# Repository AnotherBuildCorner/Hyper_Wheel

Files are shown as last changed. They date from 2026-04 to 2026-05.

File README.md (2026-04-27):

# Multi-Layer Embedded HID Interface with Rotary Input

A programmable HID control interface that replaces discrete key presses with continuous rotary input, enabling precise, context-aware interaction for workflows like video editing and CAD.

**Codename:** Hyper_Wheel

## Engineering Summary

- 4-layer mixed-signal embedded system (98 × 65 mm) based on nRF52840 (BLE + USB HID)
- RF-aware PCB layout with calculated 50Ω antenna trace on TG155 FR4
- Battery-powered architecture (LiPo + charger + protection + load switching)
- Multi-bus I²C system separating OLED displays and encoders for signal integrity
- Designed within JLCPCB DFM constraints (no blind vias, optimized BOM, 0402/0603 preference)
- Staged bring-up strategy using XIAO validation platform to decouple firmware and hardware risk

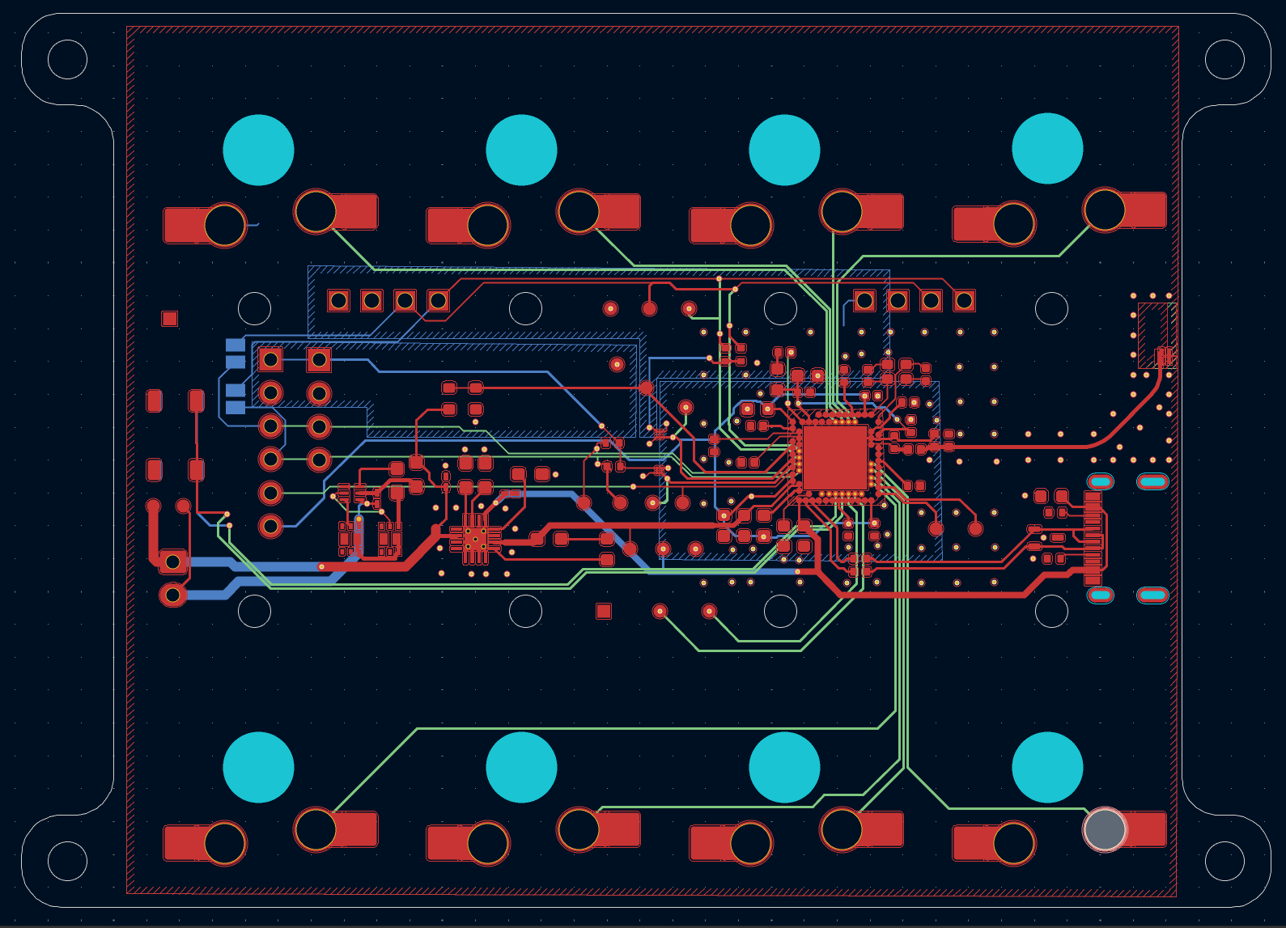
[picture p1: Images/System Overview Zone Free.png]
Full PCB

> > 4-layer mixed-signal PCB with dense MCU fanout, controlled routing, and separated power/RF domains
---

## What This Demonstrates

This project demonstrates the ability to:

- Design a mixed-signal embedded system with RF considerations  
- Make system-level tradeoffs under real constraints (power, layout, manufacturability)  
- Identify and mitigate risk without full simulation tooling  
- Structure hardware bring-up and validation intentionally  

This is not a proof-of-concept—it is a system designed to be built, debugged, and iterated.

---

## Status

- Rev A PCB complete and ready for fabrication  
- Validation hardware in production  
- Firmware development in progress  

---

## Intended Outcome

The goal of this project is to produce a fully functional, portable HID control surface that can be:

- Built using standard PCB manufacturing workflows  
- Assembled and validated without specialized RF tooling  
- Used in real workflows without custom drivers or software dependencies  

Success is defined by reliable operation, predictable behavior, and ease of integration into existing systems.

---

## Concept

### Early Concept Render
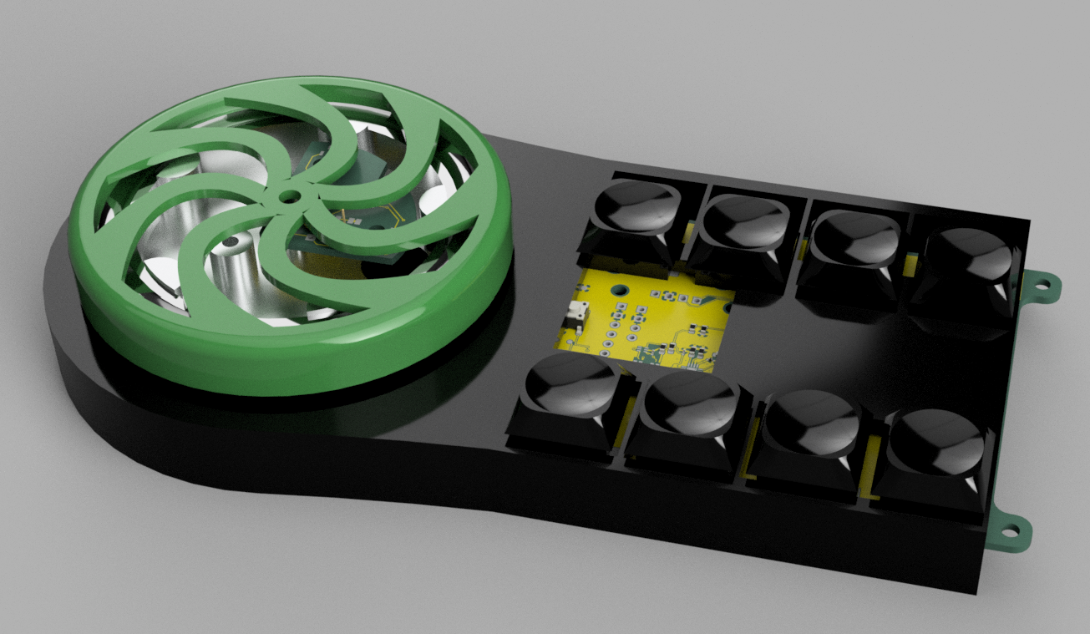
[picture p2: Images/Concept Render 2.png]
Early Render

> *Early prototype render shown for system concept demonstration. Mechanical design is still evolving.*

Hyper Wheel is a rotary-first HID control surface designed to replace discrete macro inputs with continuous, context-aware control.

The system combines:
- High-resolution rotary encoder input  
- Programmable key matrix  
- Onboard display feedback  

Primary use cases:
- Video editing (timeline scrubbing, precision control)  
- CAD navigation  
- General HID-based workflows  

The design prioritizes:
- Compact form factor  
- Driverless operation (USB/BLE HID only)  
- Integration of continuous and discrete input into a single interface  
---

## System Overview

Hyper Wheel is a programmable HID macro device built around a high-resolution magnetic encoder, designed to provide precise, context-aware control.

Unlike typical macro pads:
- Primary input is continuous (rotary), not discrete  
- Output is standard HID (keyboard + mouse)  
- Feedback is integrated via dual OLED displays  

The system is designed for enterprise compatibility:
- No custom drivers  
- USB and BLE HID only  

Current development focuses on validating:
- Power architecture  
- Multi-layer PCB layout with RF considerations  
- Scalable I/O architecture  

## System Architecture

```mermaid
flowchart LR

%% Power Path
USB[USB 5V] --> CHG[LiPo Charger]
BAT[LiPo Battery] --> PROT[Protection Circuit]
PROT --> CHG
CHG --> SYS[nRF52840 VDDH + Internal Regulator]
PROT --> VMON[ADC Batt Divider]
VMON --> MCU_ADC

%% Core System
SYS --> NRF[nRF52840 MCU] 
SYS --> LS[Load Switches]

%% Peripheral Power
LS --> OLED[Dual OLED Displays]
LS --> ENC[AS5600 Encoders]

%% Data / Control
NRF --> I2C1[I2C Bus 1]
NRF <--> I2C2[I2C Bus 2]
NRF --> LS
I2C1 --> OLED
I2C2 <--> ENC

%% Inputs
KEYS[Keyswitches on GPIO] --> NRF

%% Host Communication
NRF <--> USBDATA[USB 2.0]
NRF --> BLE[BLE]
USBDATA <--> HOST[Host Computer]
BLE --> HOST
```

## Key Features

- nRF52840-based system with **BLE + USB HID support**  
- High-resolution **magnetic encoder (AS5600-based)**  
- Dual **I2C OLED displays** for contextual UI feedback  
- **User-defined key mapping** (firmware-controlled)  
- **Left/right-hand agnostic layout** with mode switching  
- **LiPo + USB power architecture**  
- Modular sensor and expansion strategy  
- Fully **driverless operation (standard HID only)**  

---

## Engineering Highlights

### Single-MCU USB + BLE Architecture
- Transitioned from QFN48 to USB-capable aQFN73 to enable USB HID while maintaining BLE
- Preserved single-MCU architecture to reduce system complexity

### Battery-First Power System
- Implemented Nordic VDDH Config 4 architecture for battery-first operation
- USB used for detection only; system powered from charger output
- Enabled internal DC/DC (DCDCEN0/1), eliminating need for external regulator

### RF Design Approach
- Used reference antenna layout with controlled ground zones
- Calculated 50Ω impedance trace for 2.4 GHz operation on TG155 FR4
- Designed for short-range BLE use (desktop device)
- Validation deferred to hardware bring-up

### Routing Density & Layer Strategy
- Moved key matrix to inner layer to reduce congestion
- Improved fanout of high-density MCU region
- Optimized via sizing for manufacturing cost

### Iteration Strategy (Firmware First)
- Developed XIAO-based validation board to decouple firmware and hardware bring-up
- Allows testing of UI, input pipeline, and HID behavior before full PCB assembly

### Constraint-Driven Design

- Designed without access to RF simulation or SI toolchains, relying on first-principles reasoning and reference layouts to achieve first-pass success  
- Applied calculated trace geometry and conservative design margins to mitigate signal integrity risk  
- Prioritized manufacturability and iteration speed over theoretical optimization  
- Structured design to enable validation through hardware bring-up rather than pre-simulation

---

## Key Engineering Decisions

- **Single-MCU architecture (nRF52840)**  
  Reduced system complexity while supporting both BLE and USB HID

- **Battery-first power design (VDDH Config 4)**  
  Enabled seamless USB + battery operation without conflicting domains

- **Split I²C buses**  
  Prevented address conflicts and improved signal integrity under expansion

- **HID-only communication (no custom drivers)**  
  Ensures enterprise compatibility and plug-and-play behavior

- **Staged bring-up using validation hardware**  
  Reduced risk by separating firmware development from full system assembly

- **Conservative RF design without simulation tooling**  
  Relied on reference layouts and controlled geometry with validation deferred to hardware
---

## Validation Status

| Area | Status |
|---|---|
| Power System | Not yet characterized under load |
| RF Performance | Not validated (no RF test equipment available) |
| USB Signal Integrity | Not measured |
| I2C Stability | Not stress-tested |
| Firmware Integration | In progress |

> Validation strategy is structured to isolate failure modes early, reducing system-level debugging complexity during full integration

> Firmware bring-up and subsystem testing occurring prior to full hardware integration.

---

## Power Profile (Preliminary)

The following figures are early design estimates based on component datasheets and expected operating modes. Final values will be validated during bring-up.

### Component-Level Current Estimates

| Component / Mode | Estimated Current | Notes |
|---|---:|---|
| nRF52840, BLE active (+8 dBm) | 14.8 mA | Active BLE operating point on 3.3 V rail |
| OLED display (each) | 12–20 mA | 0.96" Winstar OLED at 3.3 V, ~50% illumination |
| AS5600 encoder (each, active) | 6.4 mA | Active measurement mode |
| Keyswitches | ~0 mA | No static consumption |
| nRF52840 system-off, RAM retained, wake on GPIOTE | 2.36 µA | MCU-only low-power state |

### Estimated System Current

| System Mode | Estimated Current | Notes |
|---|---:|---|
| Active, one OLED + one encoder + BLE | ~33.2–41.2 mA | 14.8 + 12–20 + 6.4 |
| Active, two OLEDs + one encoder + BLE | ~45.2–61.2 mA | Current main-board target configuration |
| Active, two OLEDs + two encoders + BLE | ~51.6–67.6 mA | Higher-end fully populated case |
| Deep sleep / system-off | ~33 µA | Includes MCU, charger, protection IC, hall sensor, FET leakage, and battery divider |

### Estimated Runtime (2000 mAh LiPo)

| Mode | Estimated Runtime |
|---|---:|
| 45.2 mA active draw | ~44 hours |
| 61.2 mA active draw | ~33 hours |
| 67.6 mA active draw | ~30 hours |
| 33 µA sleep current | ~6.9 years theoretical |

Sleep-current validation will also include key-matrix wake behavior, since retained GPIO pullups can dominate standby current if not configured carefully.

> Sleep-mode runtime is a first-order electrical estimate only and does not account for battery self-discharge, cell aging, converter losses, or environmental effects.

> These values are estimates and will be validated during hardware bring-up.

##  Hardware Overview

The following images highlight key aspects of the PCB design, including routing strategy, RF layout considerations, and multi-layer power distribution.

---

### Full PCB Layout (Routing View)
Full PCB

> Overall PCB layout showing multi-layer routing strategy, peripheral distribution, and controlled RF region placement.

---

##  MCU / RF Region Detail

### Top Layer (Routing)
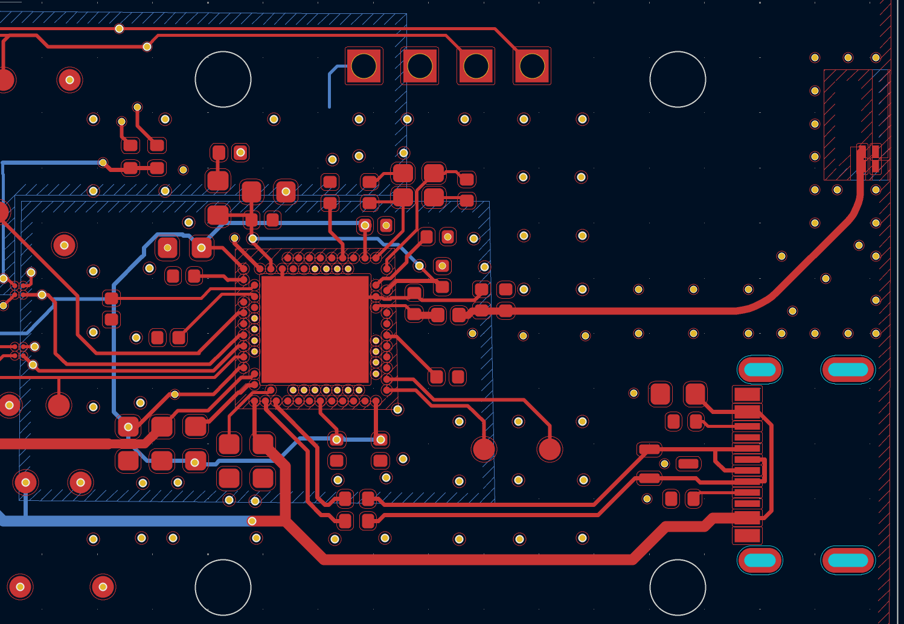
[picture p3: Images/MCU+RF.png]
MCU Routing


> nRF52840 fanout and high-density routing region, including USB interface routing and transition into a controlled antenna region.

---

### Ground Reference Layer
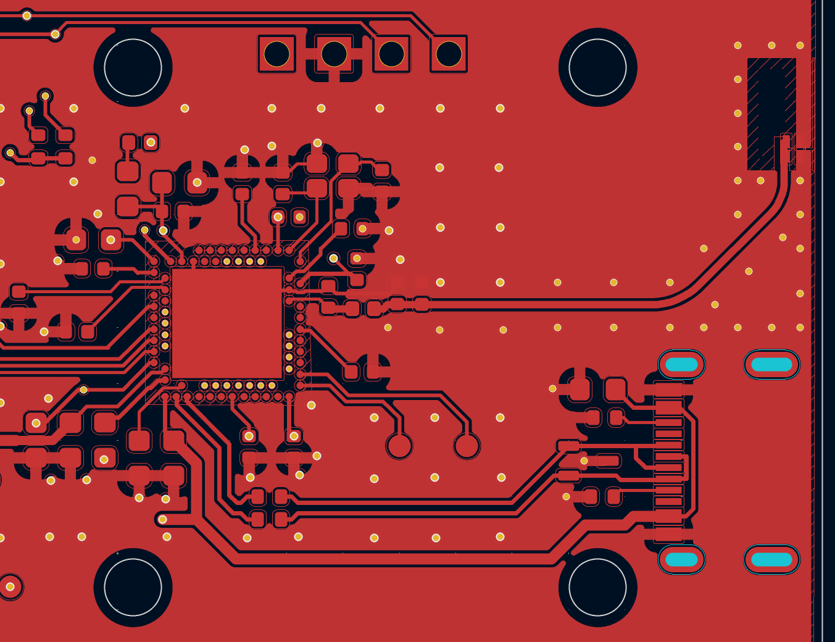
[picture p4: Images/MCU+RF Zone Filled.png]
Ground Plane


> Ground reference layer showing return path continuity, stitching strategy, and antenna clearance region.

---

### Power Distribution Layer || Metal 4
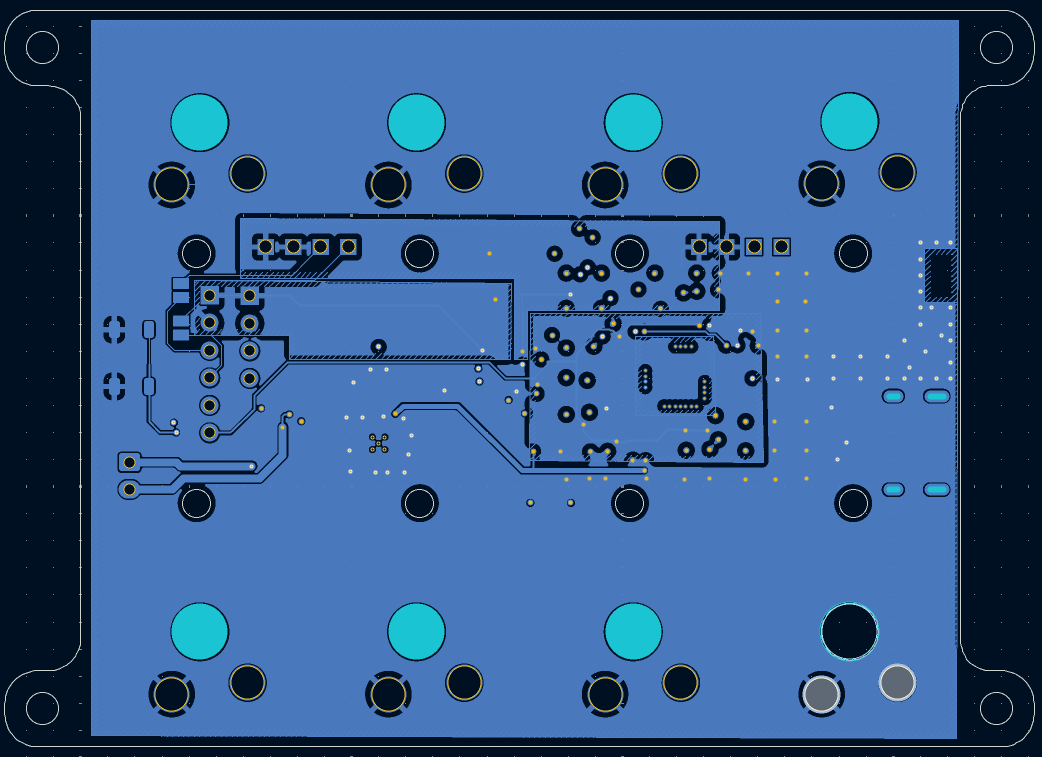
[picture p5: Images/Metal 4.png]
Power Plane


> Multi-zone power distribution separating 3.3V, Load domains, and ground to reduce coupling and improve system stability.

---

##  Layer Stack & Power Distribution

### Full Ground Plane || Metal 3
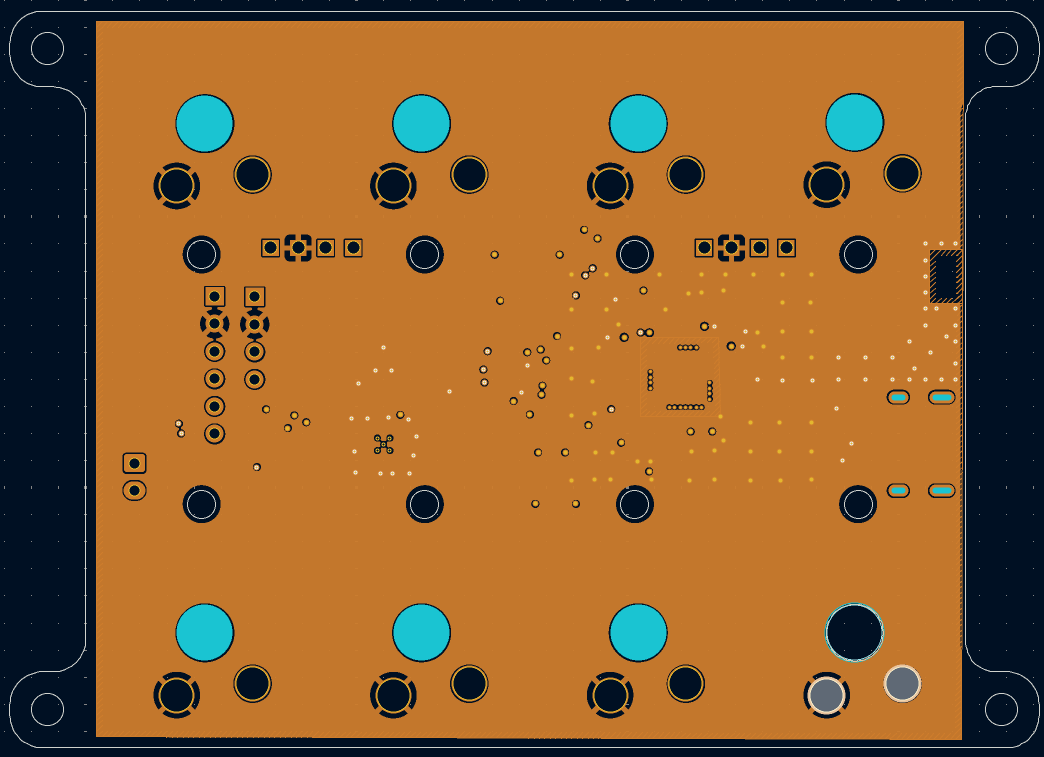
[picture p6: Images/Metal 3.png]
Full Ground


> Continuous ground plane providing low-impedance return paths across the board and supporting RF performance.

---

### Full Signal Plane || Metal 2
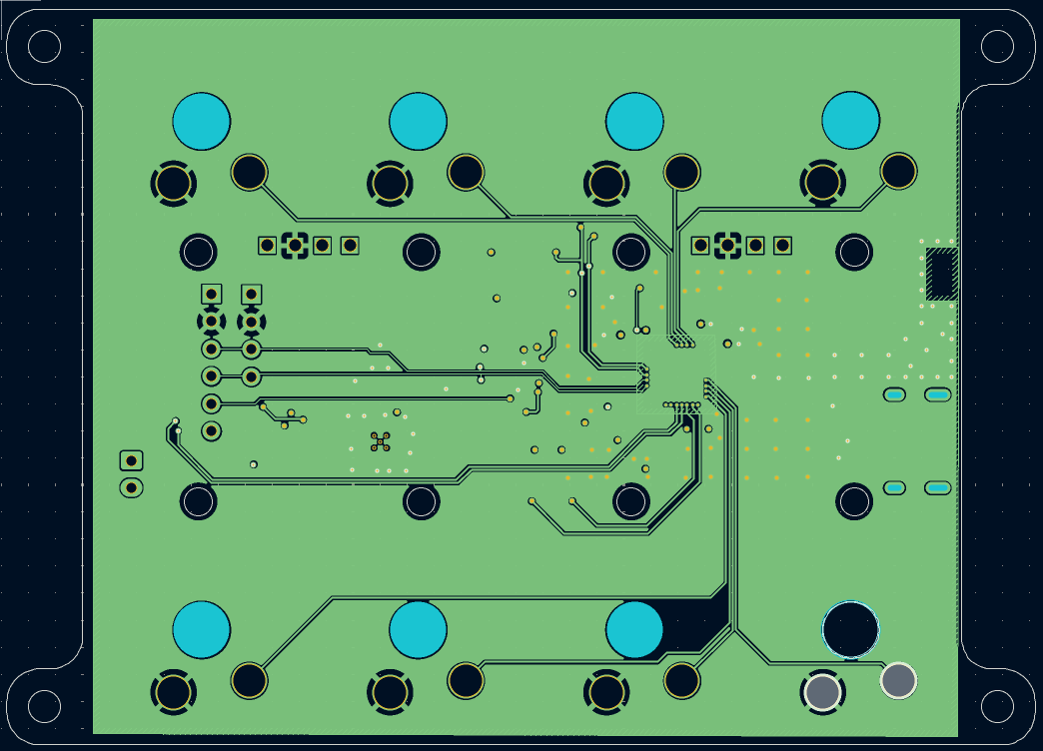
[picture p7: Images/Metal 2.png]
Full Power


> Second layer signal plane for BGA fanout.

---

### Full Top Plane || Metal 1
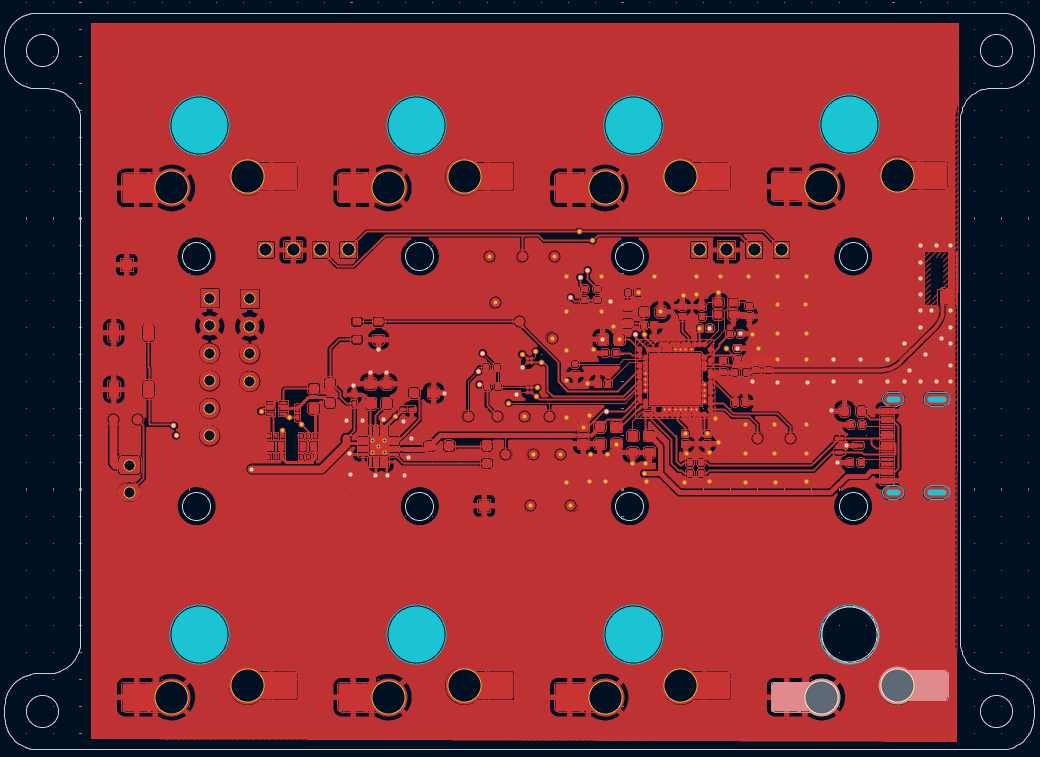
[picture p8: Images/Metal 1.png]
Full Top Plane


> Primary signal plane with all zone ground.

---

##  Dev Platform / Prototype

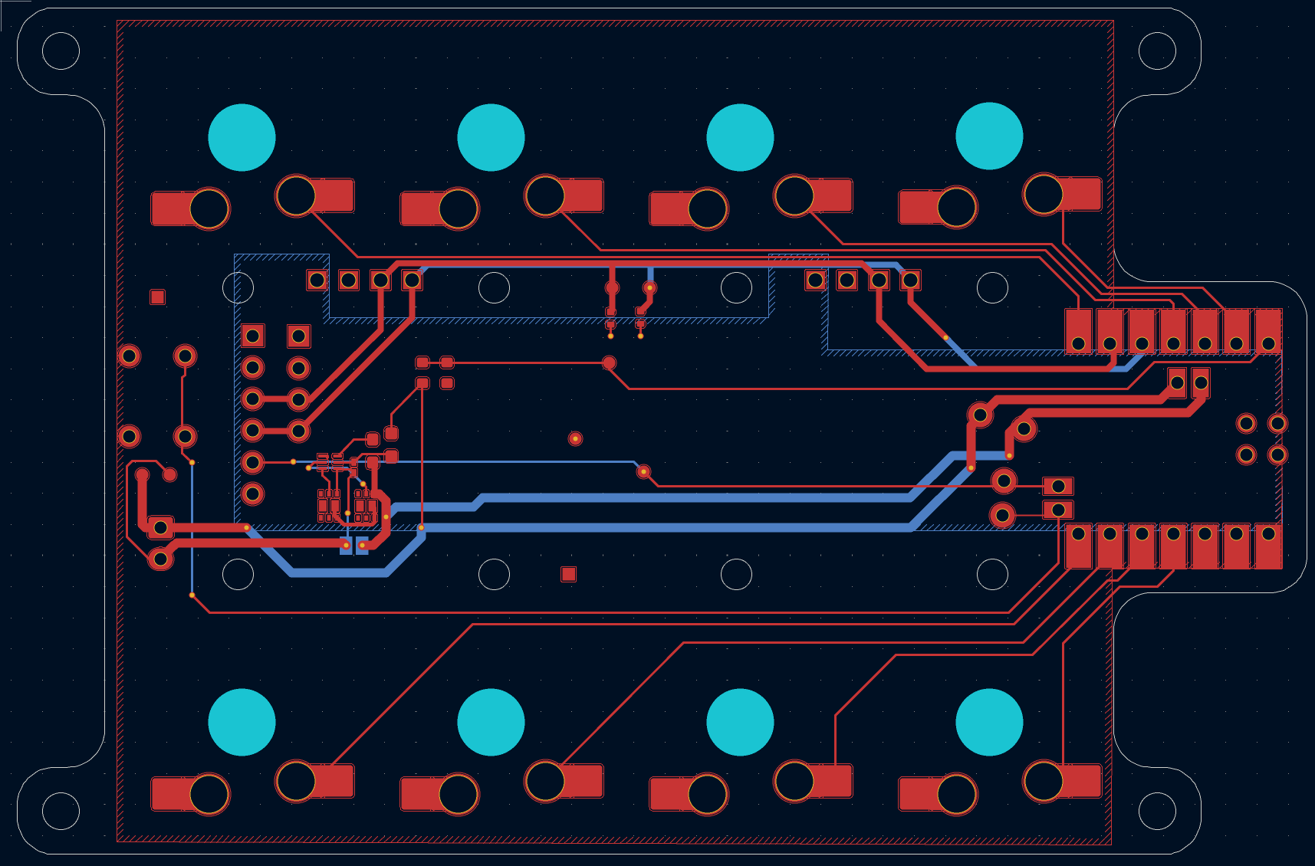
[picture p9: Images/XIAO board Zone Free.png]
XIAO Dev Board

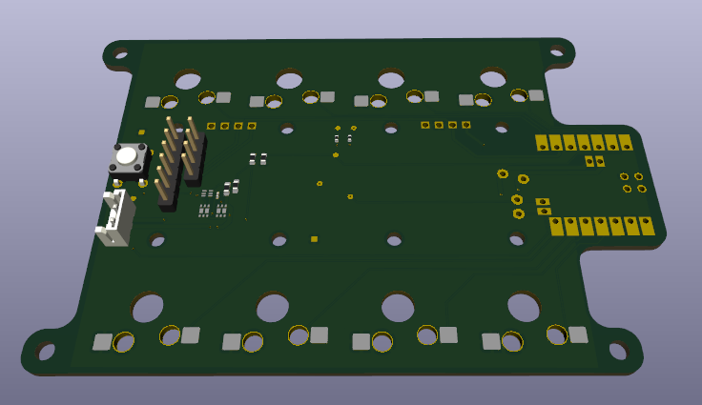
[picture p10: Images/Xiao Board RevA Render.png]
XIAO Render


> Simplified firmware validation platform based on the XIAO nRF52840, enabling rapid iteration of firmware and UI behavior prior to full hardware validation.

### Dev System Architecture

```mermaid
flowchart LR

%% Power Path
USB[USB 5V] --> CHG[XIAO Onboard LiPo Charger]
BAT[LiPo Battery] --> PROT[Protection Circuit]
PROT --> CHG
CHG --> SYS[XIAO VDDH + Internal Regulator]
PROT --> VMON[ADC Batt Divider]
VMON --> MCU_ADC

%% Core System
SYS --> NRF[nRF52840 MCU] 

%% Peripheral Power
SYS --> OLED[Dual OLED Displays]
SYS --> ENC[AS5600 Encoders]

%% Data / Control
NRF <--> I2C1[I2C Bus 1]
I2C1 <--> OLED
I2C1 <--> ENC

%% Inputs
KEYS[Keyswitches on GPIO] --> NRF

%% Host Communication
NRF <--> USBDATA[USB 2.0]
NRF --> BLE[BLE]
USBDATA <--> HOST[Host Computer]
BLE --> HOST
```

---

## Hardware Iterations

### Rev A – Firmware Validation Platform
- XIAO nRF52840-based
- Reduced feature set to validate input, display, and HID stack
- 2-layer board for reduced cost/complexity

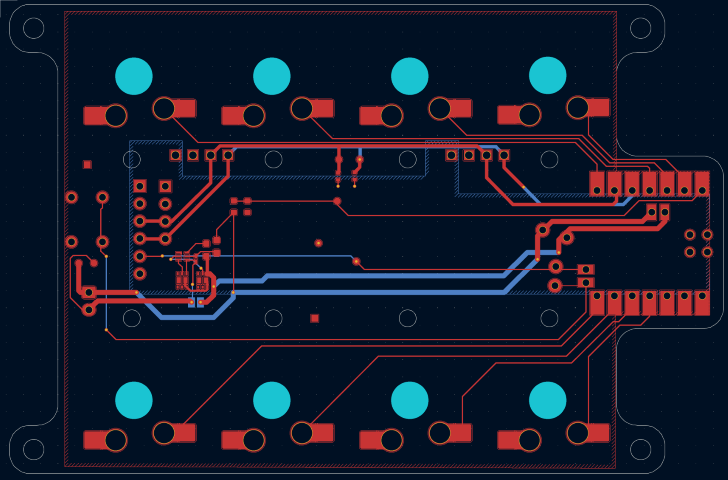
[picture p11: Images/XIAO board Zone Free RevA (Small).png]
 
> Rev A Board.

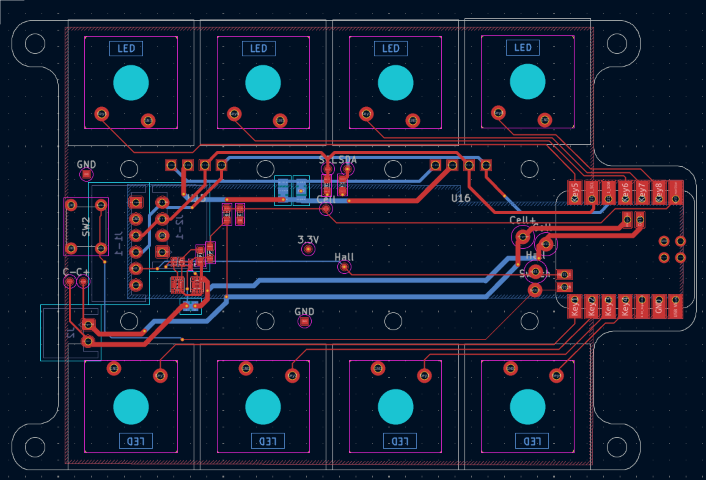
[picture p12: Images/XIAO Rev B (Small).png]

> Rev B board, note change in keyswitch footprints and added jumper network
### Rev B – Connector + Layout Refinement
- Introduced JST right-angle connectors (2/4/6 pin)
- Retained 2.54mm headers for bring-up flexibility
- Implemented rotationally symmetric connector layout
  - Enables cross-compatibility between 4-pin and 6-pin harnesses
  - Increased routing complexity but improved wiring consistency
- Adjusted OLED power routing for improved modularity

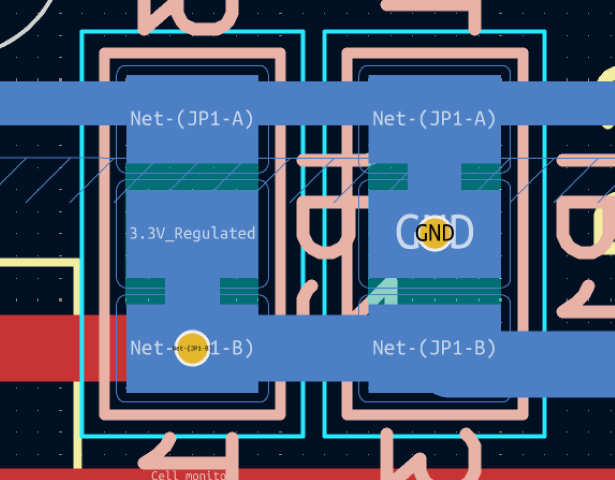
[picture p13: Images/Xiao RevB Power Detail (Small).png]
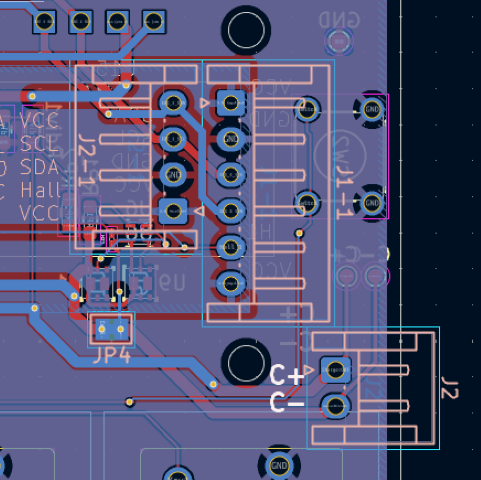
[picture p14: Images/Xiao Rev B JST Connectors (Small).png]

> Right shows the reconfigurable jumper array to switch GND and VCC pins to OLED

### Key Takeaways
- Connector standardization impacts both layout complexity and user error rate
- Bring-up flexibility is worth temporary redundancy (2.54 + JST)
- Physical interface decisions cascade into firmware, assembly, and usability

## Design for Manufacturing (DFM)

This design explicitly considers **PCBA cost and manufacturability**, not just functionality.

- Designed within standard JLCPCB capabilities (no blind vias, no via-in-pad)  
- Optimized via sizing for cost  
- Minimized use of 0201 components where not required  
- Favoring 0402 / 0603 for improved assembly yield  
- Reducing unique BOM values (ongoing)

This ensures the design is **practical for real-world assembly**, not just theoretical performance.

---

##  Assembly / 3D Model

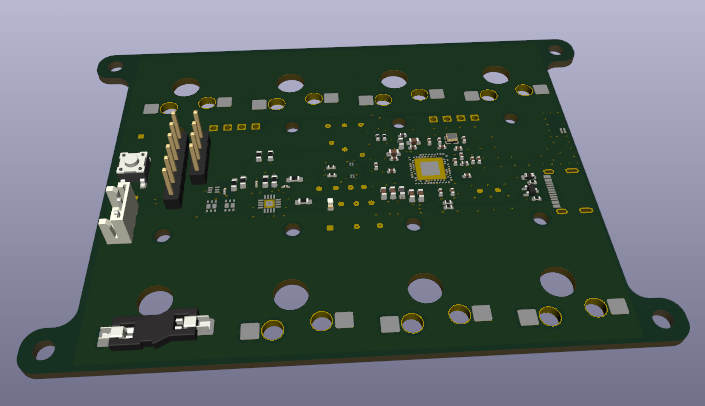
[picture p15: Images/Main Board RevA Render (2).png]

> Not all components have linked 3D models. USB and Keyswitches not shown
---

## Current Status

### Hardware
- Main PCB: Ready for fabrication (Rev A)  
- XIAO-based validation boards: Fabricated, awaiting delivery  
- Power architecture implemented (VDDH-based system)  
- Multi-layer routing and RF region defined  
- Test points and debug access integrated  

### Firmware
- Early development in progress (PlatformIO)  
- HID architecture defined (USB + BLE)  
- Encoder and display integration in progress  
- UI/UX layer not yet implemented  

### Mechanical
- Concept prototype complete (wheel + macro pad)  
- Final enclosure design pending  
- Mounting and integration strategy in development  

---

### Next Milestones

1. Bring-up XIAO validation platform  
2. Validate encoder and OLED pipeline  
3. Verify power behavior under real load  
4. Assemble Rev A main board  
5. Begin enclosure integration  

---

## Design Constraints

- Designed for standard PCB manufacturing (JLCPCB) with no blind/buried vias  
- Limited board size due to encoder geometry and enclosure constraints  
- Required HID-only communication for enterprise compatibility  
- Power system designed around single-cell LiPo with safe charge/discharge behavior

### Key Tradeoffs

- Chose single-MCU (nRF52840) over multi-chip architecture to reduce system complexity at the cost of tighter routing constraints  
- Accepted lack of RF simulation tooling and relied on reference layout + conservative design margins  
- Used internal VDDH regulation to simplify power architecture, trading off external regulator flexibility  
- Split I2C buses to manage address conflicts and maintain signal integrity under expansion

---
## Use Cases

**Primary**
- Video editing (timeline scrubbing, precision control)

**Secondary**
- CAD navigation  
- General productivity workflows  
- Custom macro environments  

---

## Future Work

### Firmware

- Development of configurable HID mapping system  
- Exploration of QMK/ZMK compatibility with encoder-based input  
- Potential on-device configuration interface via OLED UI  

### Mechanical

- Final enclosure design around encoder and key layout  
- Mounting strategy for PCB and battery integration  
- Ergonomic considerations for left/right-handed use

---

## Design Philosophy

- Use **standard HID** instead of custom drivers  
- Prioritize **iteration speed over theoretical perfection**  
- Design within **real manufacturing constraints**  
- Document decisions and tradeoffs explicitly

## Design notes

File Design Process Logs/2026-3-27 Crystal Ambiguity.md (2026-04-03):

# Crystal Footprint and Package Interpretation

## Context

Initial schematic review suggested ambiguity in crystal pin count based on symbol representation.

## Observation

- Schematic representation appeared to imply a third connection
- BOM entry only specified package size (XTAL SMD 2016)
- No explicit pin count provided

## Resolution

Review of reference PCB layout shows:

- 4-pad crystal footprint (2 active + 2 grounded case pads)
- Two pads routed to XC1 / XC2
- Two pads tied to ground plane

## Decision

Use 4-pad 2016 crystal footprint with grounded case.

## Notes

- Schematic symbols can be misleading when nodes are shared visually
- PCB layout is the authoritative reference for footprint selection
- Grounded crystal cases improve EMI and stability in RF designs

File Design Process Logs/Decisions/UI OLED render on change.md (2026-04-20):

# Event-Driven Display Update Model

**Date:** 2026-04-20

## Context
The display was originally updated continuously in the main loop, calling `displayRender()` every iteration.

This caused performance issues:
- OLED updates over I2C consumed significant time
- Encoder responsiveness degraded due to shared I2C bus contention

## Options Considered
- Option A: Continue constant redraw loop
- Option B: Throttle redraw using timing delays
- Option C: Move to event-driven redraw model

## Decision
Adopt event-driven redraw model using a dirty flag system.

## Why
Continuous redraw was unnecessary and interfered with input responsiveness. Most UI frames do not change every loop iteration.

Event-driven updates ensure:
- redraw only occurs when state changes
- I2C bandwidth is preserved
- encoder input remains responsive

## Implementation Notes
- `actionLayerUpdate()` returns a `uiChanged` flag
- Main loop sets `gDisplayDirty` when UI changes
- Mode transitions also force redraw
- Display renders only when `gDisplayDirty == true`

## Risks / Unknowns
- Missed dirty flag updates could cause stale display
- Mode transitions must always trigger redraw

## Revisit Trigger
- If UI becomes more dynamic (animations, live telemetry)
- If missed redraw bugs appear

## Notes
Menu-level caching was removed or minimized due to conflict with external dirty flag system

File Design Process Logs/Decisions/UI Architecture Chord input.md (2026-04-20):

# Input Architecture: System Button, Chords, and Preset Interaction Model

**Date:** 2026-04-20

## Context

The device now includes:
- 8 matrix keys (mapped per preset)
- 1 onboard system button (non-key, global control)
- 1+ encoders (profile-driven behavior)
- Chord detection (simultaneous key presses)

The system requires a scalable, low-friction method to access:
- Preset switching
- Preset editing
- Encoder configuration
- Bluetooth host selection
- System-level settings (orientation, pairing, etc.)

Early approaches risked overloading the system button or requiring deep menu navigation for all operations.

## Decision

Adopt a **layered input architecture** with distinct roles:

### 1. System Button → Preset Access
- **Tap:** Toggle between last two active presets
- **Hold:** Open preset picker UI

### 2. Column Chords (Top + Bottom Key in Same Column) → System Portals
Reserved for firmware-level context entry:

| Column | Function | Activation |
|---|---|---|
| Col 0  | Preset Editor | Contextual |
| Col 1  | System Menu | Tap chord  |
| Col 2  | Bluetooth Menu | Tap chord  |
| Col 3  | Encoder Tools | Hold chord |

### 3. Contextual Behavior Inside Preset Picker
When preset picker is open:
- Encoder scrolls presets
- System button confirms selection
- **Preset Editor chord enters edit mode for the currently highlighted preset**

### 4. Encoder Role (Mode-dependent)
- Normal mode: executes profile-defined action
- Menu mode: navigates selections
- Edit mode: modifies values (keycode, modifiers, labels, etc.)
- Hold-chord mode (encoder tools): performs live adjustments (e.g., sensitivity)

## Architectural Model

Inputs are separated into three tiers:

### Tier 1: Direct Actions
- Matrix keys
- Encoder (normal mode)

### Tier 2: Global Access
- System button (preset control)

### Tier 3: Context Entry
- Reserved chords (system-level mode entry)

### Tier 4: Context Execution
- Encoder + keys operate within active mode (menu/edit/system)

## Key Principles

- **Presets are accessed via the system button, not chords**
- **Chords are used for entering system contexts, not performing actions**
- **Editing is context-sensitive and tied to the currently selected preset**
- **Encoder is the primary control within all non-normal modes**
- **Hold-based chords are used for temporary, continuous adjustments**
- **Avoid overloading with multi-tap/double-tap patterns where possible**

## Rationale

This structure:
- Minimizes accidental activation (physical separation of chords)
- Matches frequency of use (presets = frequent, system settings = rare)
- Reduces reliance on timing-based gestures
- Scales cleanly as features are added
- Keeps UI mental model consistent (enter mode → operate within mode)

## Risks / Unknowns

- Exact chord mappings may need refinement based on ergonomics
- Users may require visual cues for chord discovery
- Encoder sensitivity adjustment behavior (temporary vs persistent) is not yet finalized
- Bluetooth usage patterns may influence whether dedicated chord access remains justified

## Revisit Trigger

Revisit after:
- Preset picker and editor flows are fully implemented
- Encoder adjustment behavior is tested in real use
- Bluetooth switching usage patterns are observed

## Notes

- Preset editor is not a top-level mode; it is accessed from within preset context
- Column chords remain reserved for system-level access only
- Future user-programmable chords may be restricted to non-column combinations

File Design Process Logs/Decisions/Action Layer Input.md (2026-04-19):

# Action Layer Owns Input Modes and Reserved Menu Entry

**Date:** 2026-04-19

## Context
The firmware had begun splitting into hardware input, keymap config, display rendering, and transport layers, but the central application/action layer was still missing. A specific need emerged for an internal menu system that can be entered without extra hardware, while preserving reversible device orientation and future keymap editability.

## Options Considered
- Option A: Bind menu entry to a dedicated hardware button outside the key matrix
- Option B: Reserve a hidden chord on the existing 8-key matrix
- Option C: Bind menu access as a normal mappable action within the keymap

## Decision
The action layer will own device mode switching and menu dispatch. Internal menu entry will initially use a reserved logical-key chord rather than a raw physical button chord or a user-mappable key action.

## Why
The action layer is the correct place to decide whether inputs should be interpreted as normal HID actions or as internal UI/menu controls. Using logical keys for the reserved chord preserves usability across both device orientations. Keeping menu entry outside the user keymap avoids conflicts with editable mappings and guarantees access to firmware-owned functions.

## Implementation Notes
Initial action layer structure includes:
- MODE_NORMAL
- MODE_MENU

Initial reserved menu entry:
- hold logical keys 1–4 for 1 second

Initial menu controls:
- encoder = navigate
- logical key 1 = select
- logical key 2 = back/exit

Normal HID output is suppressed while the reserved chord is being evaluated.

## Risks / Unknowns
A hidden chord may still be less discoverable than a dedicated system button. Exact menu control bindings may need refinement after display integration and real use testing. Future system controls such as BLE pairing, profile switching, or configuration save/load may require additional menu states or a broader system state model.

## Revisit Trigger
Revisit if:
- a dedicated system button is added
- logical chord entry proves awkward in use
- menu functionality expands beyond simple root navigation
- user-editable keymaps introduce conflicts with current assumptions

## Notes
The entry trigger is intentionally decoupled from the menu state machine so it can later be replaced by dedicated hardware, BLE commands, or maintenance/debug triggers without rewriting menu behavior.

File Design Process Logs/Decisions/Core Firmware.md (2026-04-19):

# Core Firmware Architecture Will Be Stabilized Before Menu and BLE Expansion

**Date:** 2026-04-19

## Context
The firmware now includes working pieces for button input, physical-to-logical key mapping, encoder step detection, USB HID transport, display rendering, and an early action layer. BLE service scaffolding also exists, but it is not yet integrated into the active application flow. Menu handling has started inside the action layer, but the normal-mode control path is not yet fully stabilized.

## Options Considered
- Option A: Continue adding menu and BLE features directly into the current scaffold
- Option B: Pause feature expansion and stabilize the architecture around the normal-mode control path first

## Decision
Core architecture stabilization will happen before expanding menu behavior or BLE integration.

## Why
The current codebase has the correct major pieces, but the full normal operating path is not yet cleanly complete. Continuing to add menu and BLE behavior before the normal path is stabilized would increase coupling and debugging difficulty. A stable baseline should exist where hardware input, logical mapping, action lookup, transport routing, and display state all work cleanly in normal mode before additional layers are added.

## Implementation Notes
Near-term architecture target:
- Definitions/config layer
- Hardware input layer
- Transport layer
- UI/render layer
- Application/action routing layer
- Minimal main entry point

Near-term order of work:
1. stabilize normal mode
2. add transport abstraction for USB/BLE routing
3. separate menu behavior into a dedicated menu layer
4. integrate BLE into the common action path
5. add persistence/config editing later

## Risks / Unknowns
Delaying menu and BLE work may feel slower in the short term, but it reduces the chance of architectural churn and hidden coupling. Encoder behavior, display redraw policy, and reserved chord handling may still need refinement during stabilization.

## Revisit Trigger
Revisit once:
- all 8 keys work end-to-end in normal mode
- encoder routing is finalized for normal mode
- action dispatch no longer depends directly on temporary debug or USB-only assumptions

## Notes
The immediate milestone is not feature breadth. It is a clean, reliable normal-mode pipeline that future menu and BLE layers can build on.

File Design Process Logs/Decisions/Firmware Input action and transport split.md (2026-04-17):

# Firmware Input / Action / Transport Split

**Date:** 2026-04-17

## Context
Initial bring-up started from single-file Arduino test sketches for encoder, OLED, and HID behavior. As USB HID, button scanning, display layout, and future BLE support began to converge, keeping all logic in one sketch became increasingly fragile. There was also a risk of coupling the encoder directly to keyboard output and coupling display logic directly to internal modules.

## Options Considered
- Option A:
  Keep most logic in a monolithic sketch and continue extending it with direct calls between buttons, encoder, HID, and OLED code.

- Option B:
  Split firmware into separate modules for inputs, mapping/action resolution, transport, and display rendering, while allowing the encoder to bypass keyboard-specific mapping when needed.

## Decision
Adopt a modular firmware structure where:
- buttons own GPIO scan, debounce, and edge detection
- encoder owns AS5600 reading and motion/step generation
- key/button mappings and encoder bindings resolve into actions
- USB/BLE act as transport layers
- display code renders a prepared display state rather than owning business logic

The encoder may bypass a keyboard-specific keymap when needed, but it should still resolve into the same action layer as the buttons.

## Why
This preserves flexibility without letting the encoder or OLED become side systems with their own incompatible logic paths. It supports:
- keyboard shortcuts for Resolve-style control
- future non-key actions such as scroll or consumer/media control
- future BLE transport without rewriting the core input model
- stable OLED rendering without circular dependencies between modules

## Implementation Notes
Current direction is:
- `buttons.*` for key GPIO handling
- `encoder.*` for AS5600 wheel handling
- `usb_hid.*` for USB keyboard transport
- `display.*` for OLED rendering from a display-state struct
- orientation and label layout handled separately from hardware scan logic

OLED grouping is defined as:
- screen A = keys 5, 6, 1, 2
- screen B = keys 7, 8, 3, 4

## Risks / Unknowns
- HID timing still needs cleanup to remove blocking delays
- BLE transport may impose different timing or report-structure needs
- final action model may need to expand beyond keyboard-only behavior
- shared I2C bus timing with encoder and dual OLEDs may need tuning

## Revisit Trigger
Revisit if:
- encoder needs scroll/media behavior instead of keyboard-only output
- BLE integration forces a different action abstraction
- OLED update timing interferes with input responsiveness
- menu/layer logic begins to blur module boundaries again

## Notes
The immediate proof point for this architecture is successful integration of:
1. dual OLED runtime screen
2. 8-button scan path
3. encoder and button actions through one common dispatch path

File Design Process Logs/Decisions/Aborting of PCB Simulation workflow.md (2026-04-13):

# Aborting Full PCB Simulation Workflow

**Date:** 2026-04-10

## Context
A possible simulation workflow was investigated for deeper PCB analysis, primarily around PDN, EM, and board-level behavior. The rough open-source path appeared to be KiCad → SALOME → Elmer, with the hope that copper features could be selectively simplified or excluded during model preparation.

The intent was to determine whether a full or near-full board analysis workflow was practical for this design, particularly for a multilayer PCB with dense routing, stitched vias, power distribution, USB, and RF concerns.

## Options Considered
- Option A: Build a full analysis workflow using KiCad exports into SALOME/Elmer and attempt to simulate large portions of the real PCB geometry.
- Option B: Use simplified or targeted analysis only, limiting simulation to specific concerns such as antenna behavior, rough thermal checks, or hand-calculated power integrity.
- Option C: Seek a more dedicated PDN / SI toolchain, accepting that most professional-grade options are commercial and likely impractical for this project.

## Decision
Abort the attempt to pursue full-board FEM / PDN-style analysis as a primary design workflow.

Instead, use targeted analysis only where it provides clear value, and rely on standard PCB design practice, simplified checks, and hand calculations for the rest.

## Why
The open-source simulation path appears to require far more geometry cleanup and abstraction work than is justified for this design.

Key reasons:
- SALOME / Elmer are not PCB-aware tools and do not naturally understand traces, pads, vias, or nets as design objects.
- Selectively excluding traces or simplifying copper after export is not straightforward unless geometry is already separated appropriately.
- A real multilayer board with stitching vias and normal routing detail would require substantial model preparation effort.
- The likely outcome is spending significant time building a simulation pipeline rather than resolving actual board risks.
- Dedicated PDN / SI tools that better match this type of problem are generally commercial and not reasonable for this project budget.

This makes full-board simulation a poor time investment relative to the likely design benefit.

## Implementation Notes
Going forward:
- Use simulation only for narrowly scoped problems where the result meaningfully affects layout decisions.
- RF / antenna behavior remains a possible candidate for targeted simulation.
- Thermal checks may still be worth doing with simplified geometry if needed.
- Power integrity should be handled primarily through layout discipline, trace/via sizing, return path awareness, and hand calculations unless a specific issue emerges.

## Risks / Unknowns
- Some second-order effects may go unmodeled.
- USB and RF behavior will rely more heavily on best practices than numerical verification.
- There is still some chance that a lighter-weight or more specialized free tool could be found later for one subset of the problem.

## Revisit Trigger
Revisit this decision if:
- A specific board issue appears that cannot be explained or resolved by normal layout review.
- A targeted simulation need emerges with clear scope and payoff.
- A practical free or low-cost PCB-aware analysis tool becomes available.
- The design grows substantially in complexity or power density.

## Notes
This is not a rejection of analysis in general. It is a rejection of building a full-board open-source simulation workflow when the tooling overhead outweighs the design value for this project.

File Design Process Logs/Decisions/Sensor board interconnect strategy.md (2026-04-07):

## Sensor Board Interconnect Strategy

**Date:** 2026-04-06

- Short internal cable (~40mm) inside single enclosure considered acceptable for AS5600/hall daughterboard
- Keeps main board compact and avoids extending PCB length by ~40mm
- Requires defined padout and strain relief strategy
- 6 pin layout (2 power, 1 ground, 2 I2c, and one switch)
- considering 1.25mm pitch ribbon connect

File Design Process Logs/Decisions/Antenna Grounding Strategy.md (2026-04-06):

# Antenna Zone and Grounding Strategy

**Date:** 2026-04-06

## Context
Chip antenna layout showed excessive GND pullback and poor copper merging behavior.  
Initial assumption pointed to custom rule conflicts, but behavior was inconsistent with rule definitions.

## Options Considered
- Option A: Increase global clearance
- Option B: Use custom rules to force zero clearance
- Option C: Adjust zone settings and pad connection locally

## Decision
Use localized zone and pad behavior control:
- Reduce zone clearance to 0.127mm
- Disable thermal relief for antenna GND pads
- Maintain footprint-defined keepout zones

## Why
- Global rules distorted RF geometry unnecessarily  
- Custom rules did not affect zone-level behavior  
- Zone clearance directly controlled copper pullback  
- Pad connection mode controlled actual electrical merging  

## Implementation Notes
- Zone clearance was incorrectly set to 0.5mm  
- Pads 2 and 3 require solid GND connection  
- Keepout zones embedded in footprint ensure portability  

## Risks / Unknowns
- RF performance not validated  
- Geometry deviates slightly from reference layout  
- Sensitive to nearby structures (USB, enclosure, battery)

## Revisit Trigger
- Poor BLE range or instability  
- Layout changes near antenna  
- Transition to production validation

## Notes
This issue originated from zone-level settings, not custom rule definitions.

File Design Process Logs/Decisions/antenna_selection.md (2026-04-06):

# 2.4 GHz Antenna Selection

**Date:** 2026-04-02

## Context
Need compact 2.4 GHz antenna for NRF52-based design with limited board space.

## Options Considered
- Johanson 2450AT07A0100001T (compact, higher gain, requires keepout)
- Johanson variant allowing ground underneath (lower performance, easier layout)
- Center board variant also considered

## Decision
Selected 2450AT07A0100001T chip antenna

## Why
- Better gain performance
- Smaller footprint
- Acceptable tradeoff vs layout constraints
- Center board model unacceptably expensive

## Risks / Unknowns
- No RF validation tools (no VNA/spectrum analyzer)
- Matching network tuning not verified
- Layout sensitivity (ground clearance, feed trace, orientation)

## Revisit Trigger
- Poor range / connection instability during real-world testing

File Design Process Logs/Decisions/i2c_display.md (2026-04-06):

# I2C Display Architecture

**Date:** 2026-04-02

## Context
Want UI feedback for key assignments

## Options Considered
- Single OLED
- Dual OLEDs on same bus
- Fully integrated display vs module
- Run each screen on separate bus, shared with one AS5600 each

## Decision
- Two I2C OLED modules on same bus [Tentative]
- Using prebuilt modules instead of raw OLED integration

## Why
- Faster implementation
- Library compatibility
- Visual layout (corner displays)

## Risks / Unknowns
- I2C address conflicts (must be configurable)
- Bus capacitance (especially if wiring expands)
- Limited refresh rate if both update frequently

## Revisit Trigger
- If UI lag or bus instability appears

---

# OLED Integration Strategy

## Context
Choice between integrating OLED directly vs using module

## Decision
Use I2C OLED module footprint instead of full integration

## Why
- Avoids driver/library complexity
- Reduces firmware risk
- Faster iteration

## Risks / Unknowns
- Larger footprint
- Less control over hardware optimization

## Revisit Trigger
- If moving toward production or space becomes critical

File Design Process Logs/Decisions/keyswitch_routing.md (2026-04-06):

# Keyswitch Routing Strategy

**Date:** 2026-04-02

## Context
Dense routing around MCU causing fanout congestion

## Options Considered
- Route on top layers (simpler but crowded)
- Push switch matrix to inner layer (Layer 3)

## Decision
Moved keyswitch routing to Layer 3

## Why
- Improves fanout from MCU
- Reduces congestion on outer layers
- Cleaner routing paths

## Risks / Unknowns
- Debug visibility reduced
- Potential coupling/noise if ground reference is poor

## Revisit Trigger
- If signal integrity or scanning issues appear

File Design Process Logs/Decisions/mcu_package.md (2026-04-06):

# Package Selection Trade Study

**Date:** 2026-03-28

## Context
Initial design targeted QFN48 for easier assembly.

## Discovery
QFN48 does not support USB and limits functionality.

## Impact
USB HID not available, conflicts with system requirements.

## Options Considered
- Remain on QFN48
- Add secondary MCU
- Transition to USB-capable package

## Decision
Transition to USB-capable package (aQFN73)

## Why
- Enables native USB HID
- Preserves single-MCU architecture

## Risks / Unknowns
- Increased assembly difficulty

## Notes
Reinforces importance of verifying package capabilities early.

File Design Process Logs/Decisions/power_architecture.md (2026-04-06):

# Power Architecture Update — Config 1 → Config 4

**Date:** 2026-03-28

## Context
Initial power architecture aligned with Nordic Config 1, assuming USB as primary supply.

## Problem
Config 1 conflicts with battery-first system design and existing charger architecture.

## Observations
Config 4 supports battery-backed operation and USB functionality.

## Decision
Transition to Config 4 power architecture.

## Why
- Aligns with battery-first behavior
- Avoids conflicting power domains
- Maintains USB functionality
- Improves efficiency via DC/DC

## Implementation Notes
- VDDH from charger output
- USB VBUS used for detection only
- DCDCEN0 / DCDCEN1 enabled
- External LDO removed

## Risks / Unknowns
- Must ensure valid VDDH range
- Requires proper low-voltage cutoff handling
- Careful USB routing required

## Revisit Trigger
- During bring-up validation

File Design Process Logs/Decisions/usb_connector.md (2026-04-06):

# USB-C Connector Placement

**Date:** 2026-04-02

## Context
USB-C connector is relatively near MCU / antenna region. System is expected to use either BLE or USB in most operating modes, with charging + BLE as a possible overlap case.

## Decision
Current placement retained for now; relocation under wheel section remains a fallback option.

## Why
- Layout constraints
- Reduced concern about simultaneous high USB data activity and BLE operation

## Risks / Unknowns
- Antenna detuning from nearby connector/cable/ground
- Charger or USB power-path noise during BLE use while charging
- Mechanical and routing tradeoffs not fully resolved

## Revisit Trigger
- Before final placement lock
- If BLE range or stability is poor in testing, especially while charging

## Notes

### USB/BLE Coexistence Assumption
System is expected to operate primarily in one of three modes:
- BLE on battery
- USB wired operation
- USB charging with BLE active

Design does not assume sustained high-speed USB data activity concurrent with BLE.
This reduces expected coexistence issues, but antenna placement and USB region layout still require care.

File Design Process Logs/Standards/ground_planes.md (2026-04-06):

# Ground Plane Strategy

**Date:** 2026-04-02

## Context
4-layer board design.

## Strategy
Use dedicated internal ground planes with outer layer fills.

## Structure
- Layers 2 and 3: solid ground
- Layers 1 and 4: signal + partial fill

## Rationale
- Improves return paths
- Reduces noise
- Supports RF + digital stability

## Risks / Tradeoffs
- Improper stitching → fragmented ground
- Antenna keepout violations

## Revisit Trigger
- Final layout review

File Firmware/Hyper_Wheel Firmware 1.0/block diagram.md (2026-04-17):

```mermaid

flowchart LR
KEY[GPIO Keys] --> HAND[Input Handler]
ENC[Rotary Encoder] --> HAND

PRE[Internal Presets] --> KMAP[Key Binding Map]
PRE --> EMAP[Encoder Binding Map]

HAND --> ROT[Orientation / Position Map]

ROT --> KMAP
ROT --> EMAP

KMAP --> ACT[Action Resolver]
EMAP --> ACT

ACT --> BLE[BLE HID]
ACT --> USB[USB HID]
ACT --> OLM[OLED Menu Control]

OLED[OLED Screen]
PRE --> OLED
KMAP --> OLED
OLM --> OLED

```

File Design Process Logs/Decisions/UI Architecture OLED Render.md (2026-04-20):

# Display Architecture Split (Mode-Specific Rendering)

**Date:** 2026-04-20

## Context
The initial display system used a single quadrant-based renderer designed for the main operating screen, where key labels are displayed in fixed positions corresponding to physical buttons.

When implementing the preset picker, this renderer was reused, requiring menu content to be forced into the quadrant layout.

## Options Considered
- Option A: Continue using quadrant renderer for all UI modes
- Option B: Introduce separate rendering paths for different UI modes

## Decision
Adopt separate render paths per UI mode:
- Normal mode uses quadrant renderer
- Preset picker uses dedicated list-style renderer
- Future modes (edit/system) will define their own render paths

## Why
Quadrant rendering is tightly coupled to the key-label display model and does not translate well to menu/list interfaces. Forcing menu content into this structure created unnecessary complexity and reduced clarity.

Separating render paths allows each mode to use a layout appropriate to its function.

## Implementation Notes
- Added `displayRenderNormal(...)`
- Added `displayRenderPresetPicker(...)`
- Preset picker renders directly from `ActionLayerState`, not `DisplayState`
- Removed menu usage of quadrant fill logic

## Risks / Unknowns
- Additional render paths may increase display module complexity
- Future modes may require further layout abstraction

## Revisit Trigger
- When implementing preset editor or system menu UI
- If rendering logic becomes duplicated across modes

## Notes
Display module remains centralized; separation is at function level, not file level (for now)

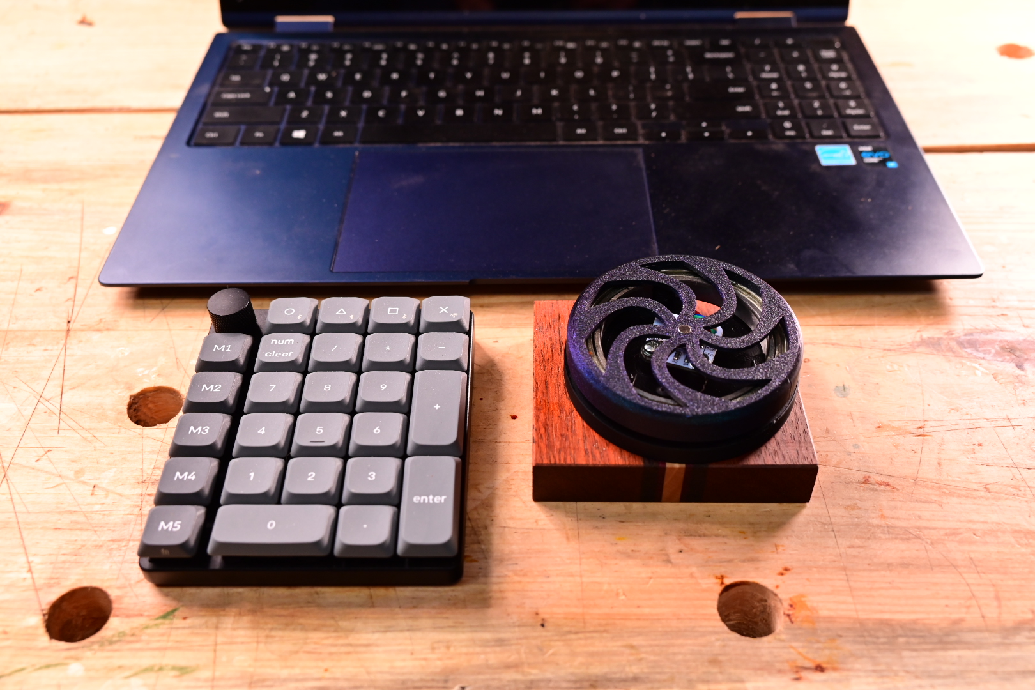
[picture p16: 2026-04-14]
Images/Concept Full.JPG

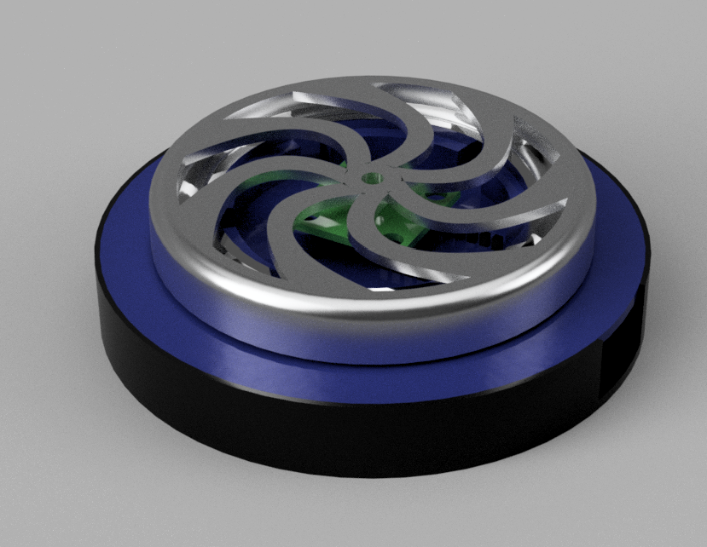
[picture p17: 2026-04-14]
Images/Original Concept.png

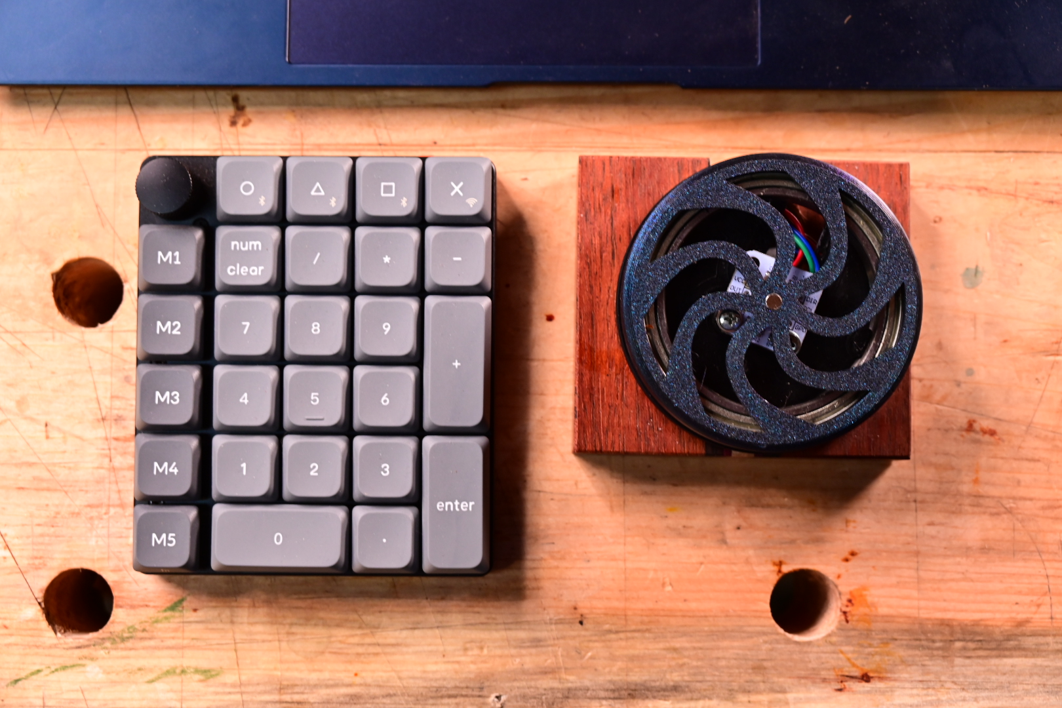
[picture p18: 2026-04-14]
Images/Concept Top Down.JPG

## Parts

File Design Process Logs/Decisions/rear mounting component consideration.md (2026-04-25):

# Rear-Mounted Component Strategy for Final Board

**Date:** 2026-04-24

## Context
Rev A XIAO board inspection showed that front-side component placement creates mechanical and accessibility constraints. The keyswitch sockets were misunderstood as front-mounted parts when they are actually rear-mounted for front-facing switches. The OLED module pinout also created a layout failure due to mismatch between reference symbol assumptions and the final module used.

## Options Considered
- Option A: Keep most components front-mounted.
- Option B: Rear-mount most SMT components except through-hole/user-facing items.
- Option C: Rear-mount most SMT components and replace OLED module with onboard SSD1306/display circuitry.

## Current Direction
Rear-mounting most non-through-hole components is under consideration for the final board.

## Why
Rear mounting may improve test pad access, reduce front-side crowding, and leave the front face primarily for user-interface elements: keys, display, wheel, and any required indicators.

## Implementation Notes
- Keep THT/mechanical interface items front-oriented where needed.
- Re-check hotswap socket footprint side/orientation explicitly.
- Verify OLED/display pinout from the exact final part, not a generic module reference.
- Charge LED may need a light pipe, edge-facing LED, or alternate visible indicator strategy.
- Onboard SSD1306/display integration may change this decision.

## Risks / Unknowns
- Rear-mounted parts may complicate assembly or enclosure clearance.
- Charge indicator visibility may become awkward.
- Display strategy is not yet settled.
- Test pad access improves only if enclosure/mechanical design leaves the rear reachable.

## Revisit Trigger
Revisit before Rev B/full-board routing is locked, especially after deciding between OLED module and onboard SSD1306/display implementation.

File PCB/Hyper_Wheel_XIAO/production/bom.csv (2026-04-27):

Designator | Footprint | Quantity | Value | LCSC Part #
CELL+, CELL-, HALL_2, SWITCH | TestPoint_Plated_Hole_D2.0mm | 4 | TestPoint
CH1, CH2, CH3, CH4, CH5, CH6, CH7, CH8 | SW_KS33_1u | 8 | KS33_SW_HS
CP1 | 0201 | 1 | 0.1u
J1-1 | JST_EH_S6B-EH_1x06_P2.50mm_Horizontal | 1 | Conn_01x06_Socket
J2 | JST_EH_S2B-EH_1x02_P2.50mm_Horizontal | 1 | LIPO
J2-1 | JST_EH_S4B-EH_1x04_P2.50mm_Horizontal | 1 | Conn_01x04_Socket
JP4 | SolderJumper-2_P1.3mm_Bridged_Pad1.0x1.5mm | 1 | Jumper_2_Bridged
RDIV1 | 0603 | 1 | 150k
RDIV2 | 0603 | 1 | 300k
RI1, RI2 | 0603 | 2 | 4.7k
RP1 | 0603 | 1 | 2.2k
RP2 | 0603 | 1 | 330
SW2 | SW_TH_Tactile_Omron_B3F-100x | 1 | SW_Push
U1, U9 | CDS85301-DQK0006B | 2 | CSD85301Q2
U15, U16 | OLED 128x64 | 2 | ~
U2 | XIAO-nRF52840-Sense-14P-THTMOD | 1 | Seeed Studio XIAO nRF52840
U6 | BQ29700-DSE0006A | 1 | BQ29700DSER

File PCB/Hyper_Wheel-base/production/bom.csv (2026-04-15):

Designator | Footprint | Quantity | Value | LCSC Part #
C1, C17, C18, C2 | 0402 | 4 | 12p
C10, C13, C22 | 0402 | 3 | N.C.
C11 | 0402 | 1 | 100p
C12, C25, C26, C5, C7, C8 | 0402 | 6 | 100n
C14, C15, C23, C24 | 0603 | 4 | 1.0u
C16 | 0402 | 1 | 47n
C19, C20, C21, C6 | 0603 | 4 | 4.7u
C3 | 0402 | 1 | 0.8p
C4 | 0402 | 1 | 0.5p
C9 | 0402 | 1 | 820p
CH1, CH2, CH3, CH4, CH5, CH6, CH7, CH8 | SW_KS33_HS_KS-2P02B01-02_HS_1u | 8 | KS33_SW_HS
CP1 | 0201 | 1 | 0.1u
CP2 | 0201 | 1 | 1u
CP3 | 0201 | 1 | 4.7u
D1 | 0603 | 1 | D_TVS
DP1 | 0603 | 1 | LED
J1-1 | PinHeader_1x06_P2.54mm_Vertical | 1 | Conn_01x06_Socket
J2 | JST_EH_B2B-EH-A_1x02_P2.50mm_Vertical | 1 | LIPO
J2-1 | PinHeader_1x04_P2.54mm_Vertical | 1 | Conn_01x04_Socket
J3 | USBC-CONN_8p94X6p5X3p16_12L_GCC | 1 | USB4215-03-A
JP1, JP2 | SolderJumper-2_P1.3mm_Open_Pad1.0x1.5mm | 2 | Jumper_2_Open
L1 | 0402 | 1 | 4.7nH
L2, L4 | 0603 | 2 | 10uH
L3 | 0402 | 1 | 15nH
RCC1, RCC2 | 0402 | 2 | 5.1k
RD1, RD2, RS1, RS2 | 0402 | 4 | 4.7k
RDIV1 | 0603 | 1 | 150k
RDIV2 | 0603 | 1 | 300k
RP1 | 0603 | 1 | 2.2k
RP2 | 0603 | 1 | 330
RP3 | 0603 | 1 | 1.5k
RP4 | 0603 | 1 | 4.12k
RP5 | 0603 | 1 | 1.18k
RP6 | 0603 | 1 | 1.13k
RUSB1, RUSB2 | 0402 | 2 | 22
SW1, SW2 | SW_SPST_PTS647_Sx38 | 2 | SW_Push
U1, U9 | CDS85301-DQK0006B | 2 | CSD85301Q2
U10, U4 | DBV0006A_L | 2 | TPS22916CNYFPR
U11 | SOT-323_SC-70 | 1 | TPD2EUSB30ADRTR
U13, U3 | AS5600L-ASOM_AMS | 2 | AS5600L-ASOM
U14, U8 | DRV5032-DBZ0003A-IPC_A | 2 | DRV5032FCDBZR
U15, U16 | OLED 128x64 | 2 | ~
U17 | 2450AT07A0100T_JOT+Keepout | 1 | 2450AT07A0100T
U2 | NORDIC_NRF52840-QIAA-R7 | 1 | NRF52840-QIAA-R7
U6 | BQ29700-DSE0006A | 1 | BQ29700DSER
U7 | BQ24074-QFN50P300X300X100-17N | 1 | BQ24074RGTR
Y1 | Crystal_SMD_2016-4Pin_2.0x1.6mm | 1 | 32MHz

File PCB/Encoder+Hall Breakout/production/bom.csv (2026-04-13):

Designator | Footprint | Quantity | Value | LCSC Part #
3.3V1, CCW1 | SolderJumper-2_P1.3mm_Open_Pad1.0x1.5mm | 2 | Jumper_2_Open
5V1, CW1 | SolderJumper-2_P1.3mm_Bridged_Pad1.0x1.5mm | 2 | Jumper_2_Bridged
C1 | 0603 | 1 | 100n
C2 | 0603 | 1 | 10u
J1-2 | PinHeader_1x06_P2.54mm_Vertical | 1 | Conn_01x06_Pin
OUT1 | PinHeader_1x01_P1.00mm_Vertical | 1 | TestPoint
PGO1 | TestPoint_Pad_D2.0mm | 1 | TestPoint
R1, R2 | 0603 | 2 | 4.7k
U1 | AS5600L-ASOM_AMS | 1 | AS5600L-ASOM
U2, U3 | DRV5032-DBZ0003A-MFG | 2 | DRV5032FCDBZR

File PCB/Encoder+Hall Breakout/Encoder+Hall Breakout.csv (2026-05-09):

Reference | Qty | Value | DNP | Exclude from BOM | Exclude from Board | Footprint | Datasheet
3.3V1,CCW1 | 2 | Jumper_2_Open |  |  |  | Jumper:SolderJumper-2_P1.3mm_Open_Pad1.0x1.5mm
5V1,CW1 | 2 | Jumper_2_Bridged |  |  |  | Jumper:SolderJumper-2_P1.3mm_Bridged_Pad1.0x1.5mm
C1 | 1 | 100n |  |  |  | Capacitor_SMD:C_0603_1608Metric_Pad1.08x0.95mm_HandSolder
C2 | 1 | 10u |  |  |  | Capacitor_SMD:C_0603_1608Metric_Pad1.08x0.95mm_HandSolder
J1-2 | 1 | Conn_01x06_Pin |  |  |  | Connector_PinHeader_2.54mm:PinHeader_1x06_P2.54mm_Vertical
OUT1 | 1 | TestPoint |  |  |  | Connector_PinHeader_1.00mm:PinHeader_1x01_P1.00mm_Vertical
PGO1 | 1 | TestPoint |  |  |  | TestPoint:TestPoint_Pad_D2.0mm
R1,R2 | 2 | 4.7k |  |  |  | Resistor_SMD:R_0603_1608Metric_Pad0.98x0.95mm_HandSolder
U1 | 1 | AS5600L-ASOM |  |  |  | Hyper_Wheel:AS5600L-ASOM_AMS | AS5600L-ASOM
U2,U3 | 2 | DRV5032FCDBZR |  |  |  | Hyper_Wheel:DRV5032-DBZ0003A-MFG | https://www.ti.com/lit/gpn/drv5032

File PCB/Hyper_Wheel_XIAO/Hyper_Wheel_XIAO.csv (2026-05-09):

Reference | Qty | Value | DNP | Exclude from BOM | Exclude from Board | Footprint | Datasheet
Cell+1,Cell-1,Hall1,Switch1 | 4 | TestPoint |  |  |  | TestPoint:TestPoint_Plated_Hole_D2.0mm
CH1,CH2,CH3,CH4,CH5,CH6,CH7,CH8 | 8 | KS33_SW_HS |  |  |  | Hyper_Wheel:SW_KS33_1u
CP1 | 1 | 0.1u |  |  |  | Capacitor_SMD:C_0201_0603Metric_Pad0.64x0.40mm_HandSolder
J1-1 | 1 | Conn_01x06_Socket |  |  |  | Connector_JST:JST_EH_S6B-EH_1x06_P2.50mm_Horizontal
J1-2 | 1 | Conn_01x06_Pin
J2 | 1 | LIPO |  |  |  | Connector_JST:JST_EH_S2B-EH_1x02_P2.50mm_Horizontal
J2-1 | 1 | Conn_01x04_Socket |  |  |  | Connector_JST:JST_EH_S4B-EH_1x04_P2.50mm_Horizontal
JJ2-2 | 1 | Conn_01x04_Pin
JP4 | 1 | Jumper_2_Bridged |  |  |  | Jumper:SolderJumper-2_P1.3mm_Bridged_Pad1.0x1.5mm
Rdiv1 | 1 | 150k |  |  |  | Resistor_SMD:R_0603_1608Metric_Pad0.98x0.95mm_HandSolder
Rdiv2 | 1 | 300k |  |  |  | Resistor_SMD:R_0603_1608Metric_Pad0.98x0.95mm_HandSolder
RI1,RI2 | 2 | 4.7k |  |  |  | Resistor_SMD:R_0603_1608Metric_Pad0.98x0.95mm_HandSolder
RP1 | 1 | 2.2k |  |  |  | Resistor_SMD:R_0603_1608Metric_Pad0.98x0.95mm_HandSolder
RP2 | 1 | 330 |  |  |  | Resistor_SMD:R_0603_1608Metric_Pad0.98x0.95mm_HandSolder
SW2 | 1 | SW_Push |  |  |  | Button_Switch_THT:SW_TH_Tactile_Omron_B3F-100x
U1,U9 | 2 | CSD85301Q2 |  |  |  | Hyper_Wheel:CDS85301-DQK0006B | https://www.ti.com/lit/gpn/csd85301q2
U2 | 1 | Seeed Studio XIAO nRF52840 |  |  |  | Hyper_Wheel:XIAO-nRF52840-Sense-14P-THTMOD
U3,U13 | 2 | AS5600L-ASOM |  |  |  | Hyper_Wheel:AS5600L-ASOM_AMS | AS5600L-ASOM
U6 | 1 | BQ29700DSER |  |  |  | Hyper_Wheel:BQ29700-DSE0006A | https://www.ti.com/lit/gpn/bq2970
U8,U14 | 2 | DRV5032FCDBZR |  |  |  | Hyper_Wheel:DRV5032-DBZ0003A-IPC_A | https://www.ti.com/lit/gpn/drv5032
U15,U16 | 2 |  |  |  |  | Hyper_Wheel:OLED 128x64

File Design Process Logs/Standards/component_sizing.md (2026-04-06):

# Passive Component Sizing Strategy

**Date:** 2026-03-26

## Context
Reference design uses 0201 components extensively.

## Strategy
Divide components into categories based on function.

## Categories / Rules
- RF-Critical (retain 0201)
- Timing-Critical (0402 consideration)
- General Passives (0402)
- Bulk Components (0603)

## Rationale
- Maintain RF integrity
- Improve assembly success rate
- Reduce placement difficulty

## Notes
Component size affects parasitics at RF frequencies.

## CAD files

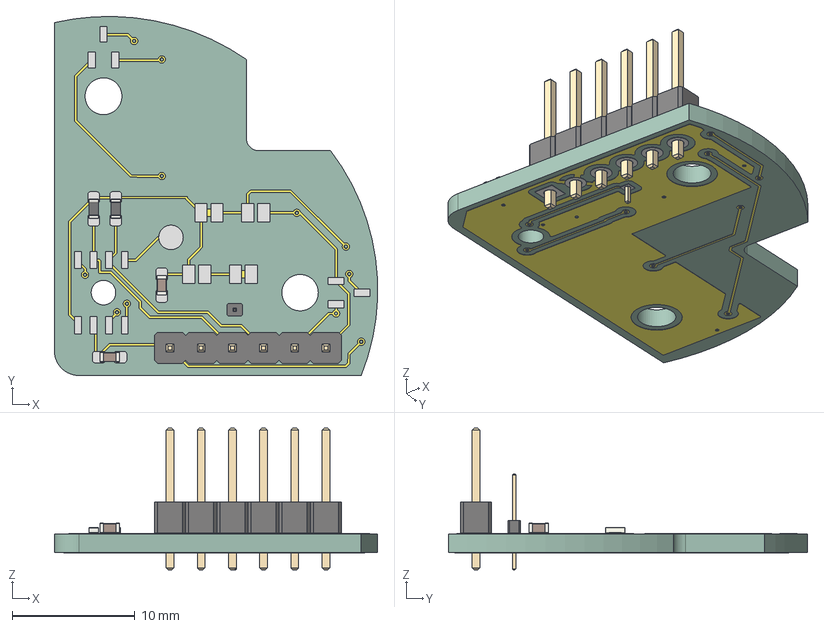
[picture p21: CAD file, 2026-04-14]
PCB/Encoder+Hall Breakout/Encoder Breakout.step
26.3 x 29.2 x 11.5 mm
PinHeader_1x01_P1.00mm_Vertical
R_0603_1608Metric x 2
C_0603_1608Metric x 2
PinHeader_1x06_P2.54mm_Vertical
Encoder+Hall Breakout_copper
Encoder+Hall Breakout_pad
Encoder+Hall Breakout_via
Encoder+Hall Breakout_PCB

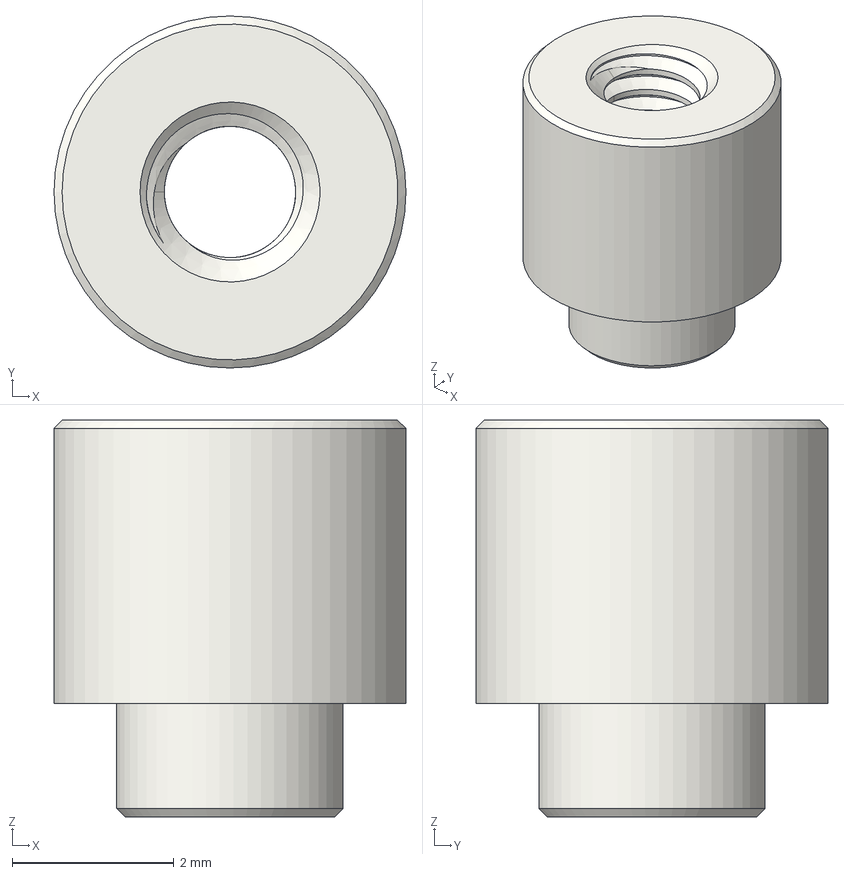
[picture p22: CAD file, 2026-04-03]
PCB/Hyper_Wheel_XIAO/Vendor Parts/marbastlib-main/marbastlib-main/3dmodels/Mounting_Wuerth_WA-SMSI-M2_H3P5mm_9774035243R.step
4.35 x 4.35 x 4.90 mm

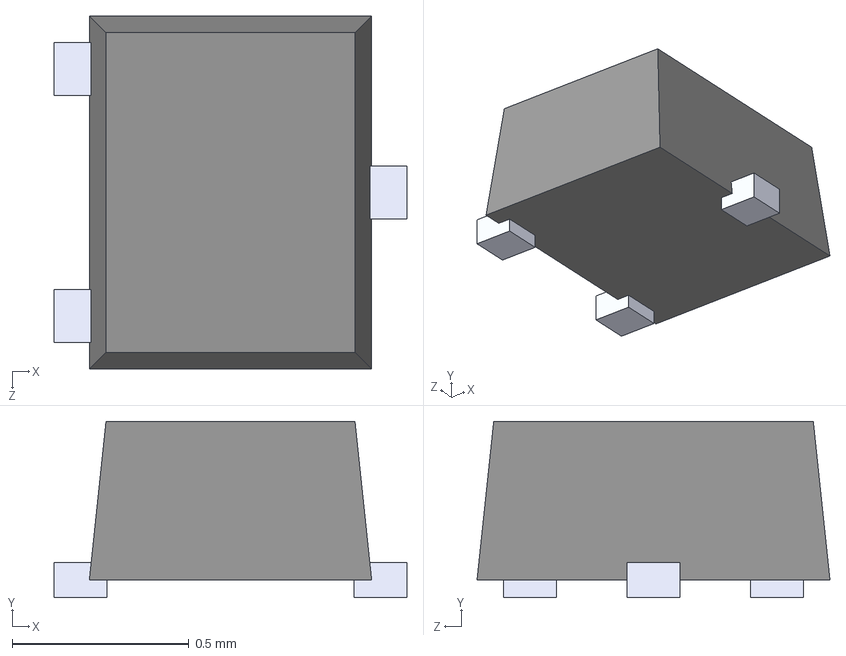
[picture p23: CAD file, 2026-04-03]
PCB/Hyper_Wheel_XIAO/Vendor Parts/TPD2EUSB30ADRTR/TPD2EUSB30ADRTR.step
1.00 x 0.5 x 1.00 mm

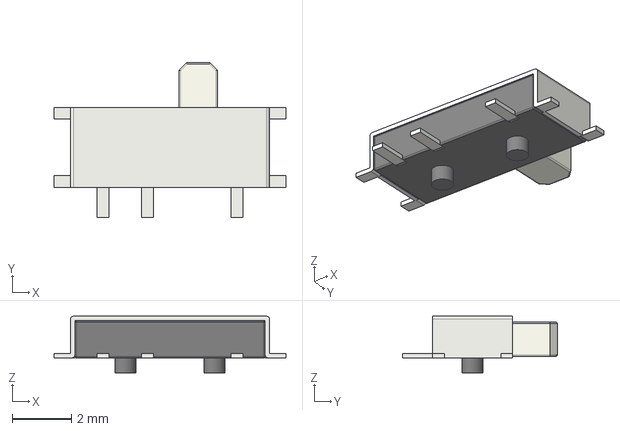
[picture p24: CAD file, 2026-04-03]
PCB/Hyper_Wheel_XIAO/Vendor Parts/marbastlib-main/marbastlib-main/3dmodels/SW_MSK12C02.step
7.80 x 5.20 x 1.90 mm

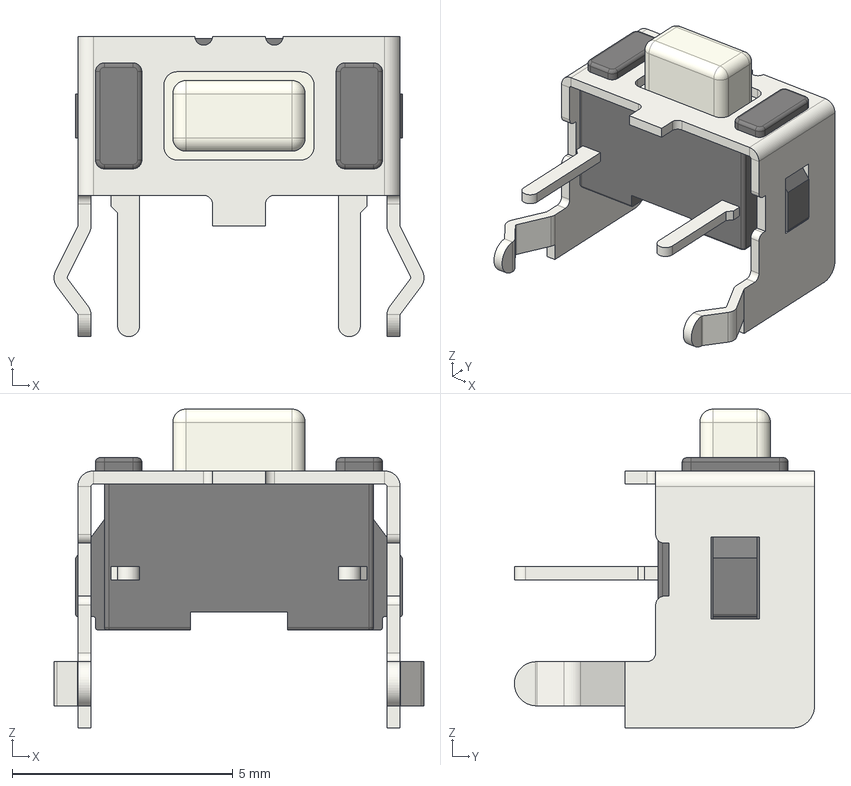
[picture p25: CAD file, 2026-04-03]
PCB/Hyper_Wheel_XIAO/Vendor Parts/marbastlib-main/marbastlib-main/3dmodels/SW_SKHLLC.step
8.38 x 6.80 x 7.22 mm

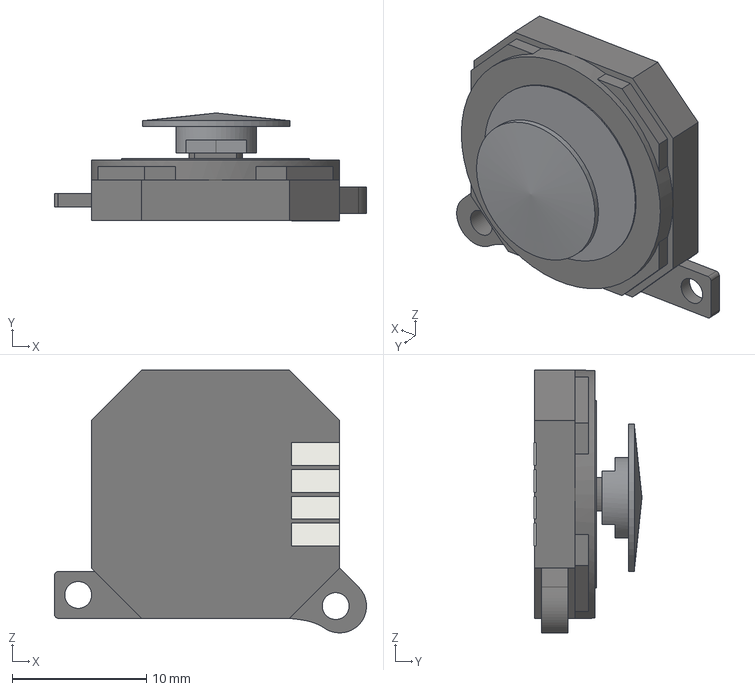
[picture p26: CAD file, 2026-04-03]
PCB/Hyper_Wheel_XIAO/Vendor Parts/marbastlib-main/marbastlib-main/3dmodels/PNT_psp1000.step
23.2 x 8.05 x 19.6 mm

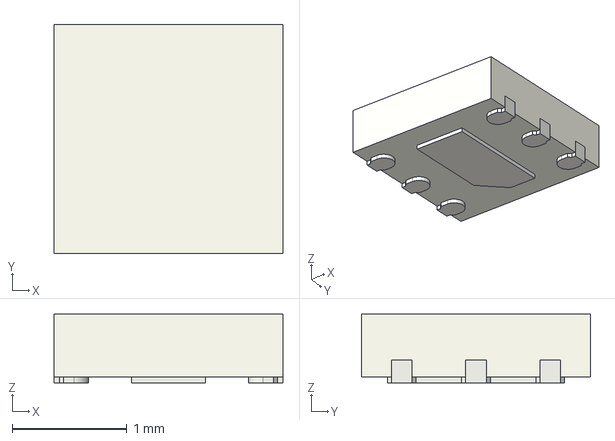
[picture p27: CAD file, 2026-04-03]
PCB/Hyper_Wheel_XIAO/Vendor Parts/marbastlib-main/marbastlib-main/3dmodels/Texas_OPT3004DNPR_QFN-6_EP_2x2_Pitch0.65mm.step
2.00 x 2.00 x 0.6 mm

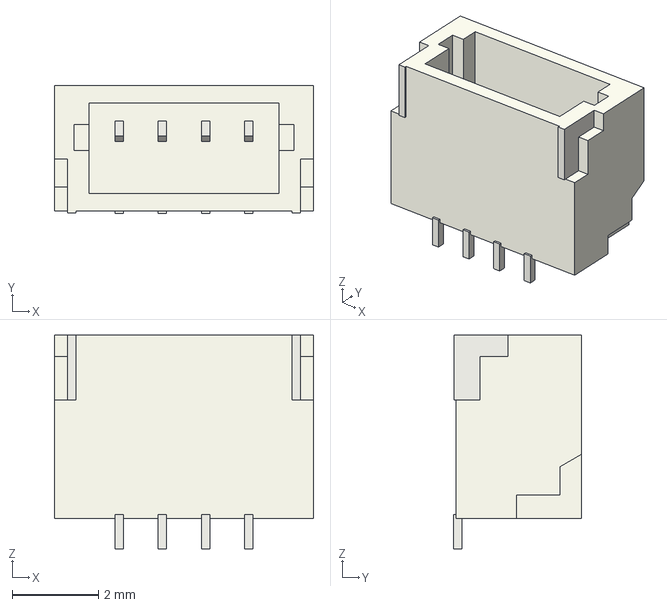
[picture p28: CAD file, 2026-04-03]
PCB/Hyper_Wheel_XIAO/Vendor Parts/marbastlib-main/marbastlib-main/3dmodels/CON_SM04B-SRSS-TB.step
6.00 x 2.96 x 4.95 mm

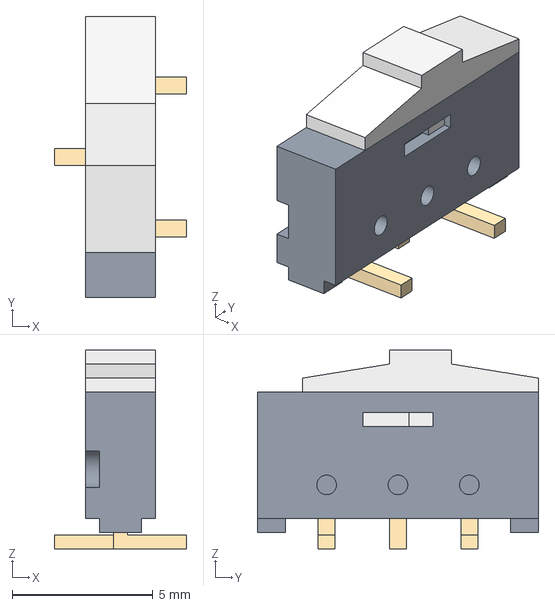
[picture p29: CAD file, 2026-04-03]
PCB/Hyper_Wheel_XIAO/Vendor Parts/marbastlib-main/marbastlib-main/3dmodels/SW_ESP3020.step
4.70 x 10.0 x 7.08 mm

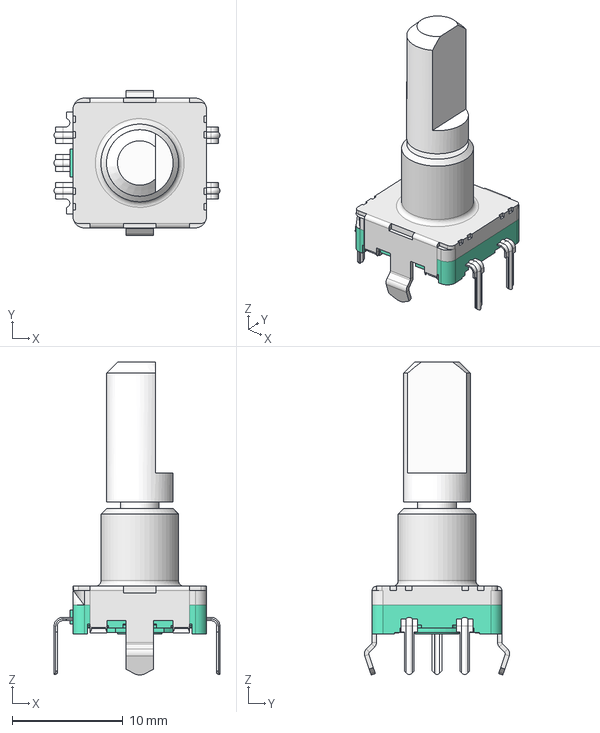
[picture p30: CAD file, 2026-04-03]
PCB/Hyper_Wheel_XIAO/Vendor Parts/marbastlib-main/marbastlib-main/3dmodels/ROT_EC11E.step
14.9 x 13.1 x 28.2 mm

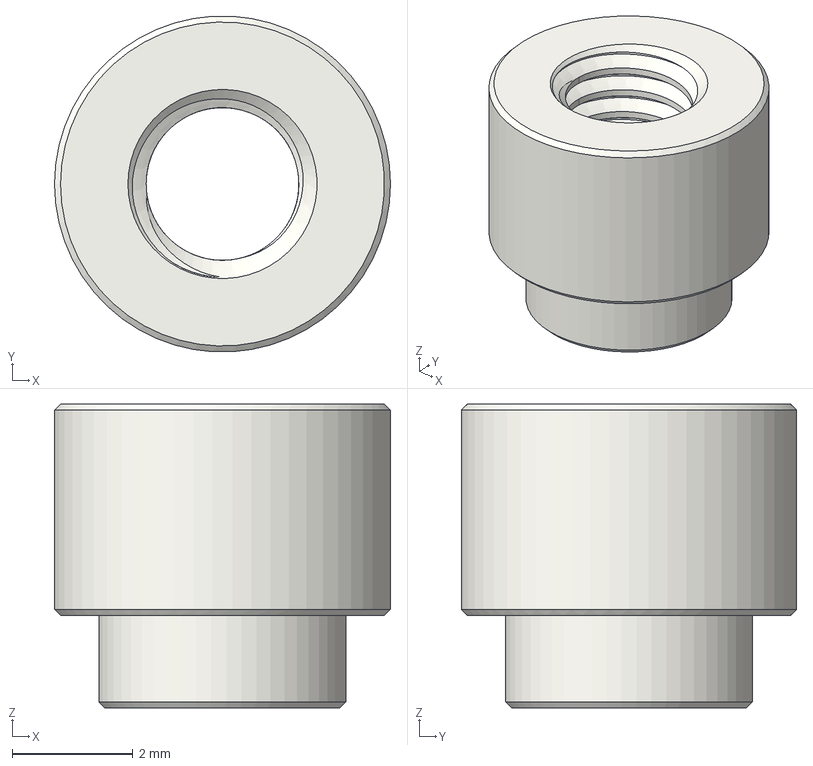
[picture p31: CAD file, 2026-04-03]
PCB/Hyper_Wheel_XIAO/Vendor Parts/marbastlib-main/marbastlib-main/3dmodels/Mounting_Sinhoo_SolderElement_SMTSO3035CTJ.step
5.56 x 5.55 x 5.03 mm

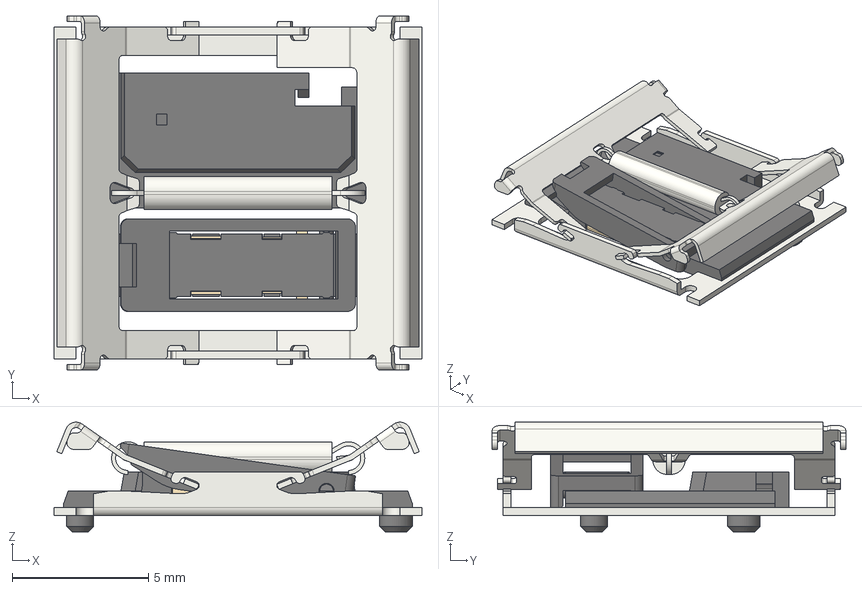
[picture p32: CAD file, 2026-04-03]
PCB/Hyper_Wheel_XIAO/Vendor Parts/marbastlib-main/marbastlib-main/3dmodels/SW_Kailh_CPG1316S-2.step
13.5 x 13.0 x 4.03 mm
PG1316S-»ù×ù
Çý¶¯¸Ë
Æ½ºâ¼Ü
À»É
PG1316S-¶¯½Ó´¥Æ¬-´ ø´¥µã
PG1316S-¾²Æ¬-´ø´¥µ ã
Æ½ºâ¼Ü-B
1316S-»ù×ù¿¨¼þ

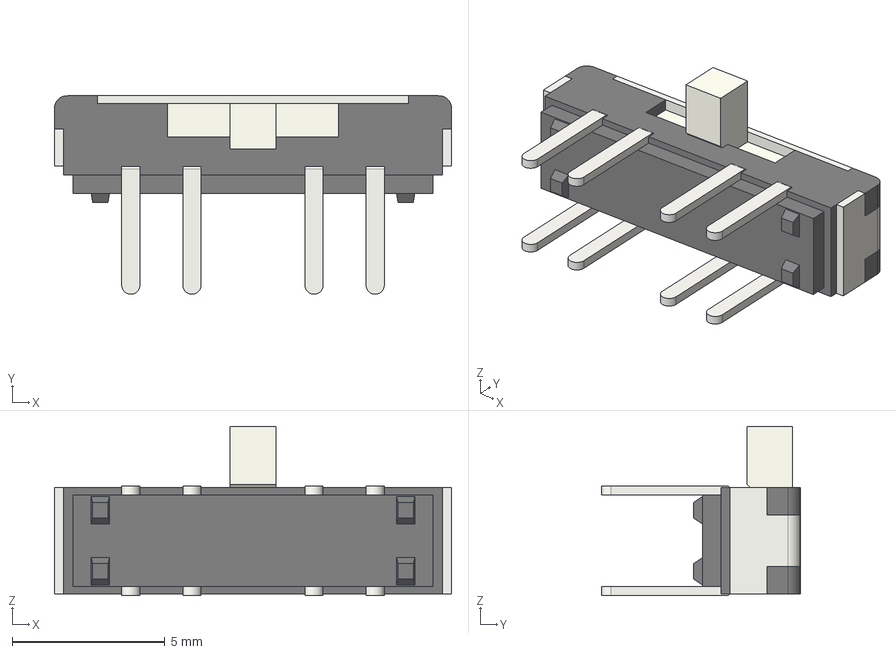
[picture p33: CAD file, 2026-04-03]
PCB/Hyper_Wheel_XIAO/Vendor Parts/marbastlib-main/marbastlib-main/3dmodels/SW_SSSS223900.step
13.0 x 6.50 x 5.55 mm

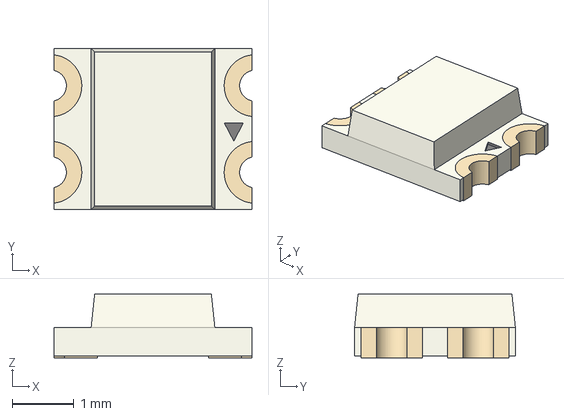
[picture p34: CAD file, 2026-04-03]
PCB/Hyper_Wheel_XIAO/Vendor Parts/marbastlib-main/marbastlib-main/3dmodels/LED_Everlight_15-13DR6GHBHC-A012T.step
3.20 x 2.60 x 1.03 mm

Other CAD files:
PCB/Hyper_Wheel_XIAO/Vendor Parts/marbastlib-main/marbastlib-main/3dmodels/CON_781710004.step
PCB/Hyper_Wheel_XIAO/Vendor Parts/marbastlib-main/marbastlib-main/3dmodels/Texas_X2QFN-12_1.6x1.6mm.step
PCB/Hyper_Wheel_XIAO/Vendor Parts/marbastlib-main/marbastlib-main/3dmodels/CON_SM13B-SRSS-TB.step
PCB/Hyper_Wheel_XIAO/Vendor Parts/marbastlib-main/marbastlib-main/3dmodels/CON_781710002.step
PCB/Hyper_Wheel-base/Vendor Parts/59453_062110ECHLF/59453-062110ECHLF.step
PCB/Hyper_Wheel_XIAO/Vendor Parts/BQ24074RGTR/BQ24074RGTR.step
PCB/Hyper_Wheel_XIAO/Vendor Parts/NRF52840_QIAA_R7/NRF52840-QIAA-R7.step
PCB/Hyper_Wheel_XIAO/Vendor Parts/marbastlib-main/marbastlib-main/3dmodels/ANT_Johanson_2450AT18D0100001E v1.step
PCB/Hyper_Wheel_XIAO/Vendor Parts/marbastlib-main/marbastlib-main/3dmodels/CON_2082940020.step
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

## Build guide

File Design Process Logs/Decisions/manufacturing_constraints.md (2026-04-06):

# Manufacturing Constraints - JLCPCB

**Date:** 2026-04-02

## Context
Board must meet JLCPCB standard capabilities (low-cost tier)

## Constraints
- Trace width: 0.127 mm used (min 0.1 mm)
- Spacing: 0.1 mm
- Power traces: 0.2 mm where possible
- No blind/buried vias
- No vias in pad under NRF

## Decision
Designed within standard JLC constraints

## Why
- Keeps cost low
- Avoids advanced fabrication requirements

## Risks / Unknowns
- Tight tolerances → higher failure risk
- Power integrity may be marginal on thin traces
- Routing compromises due to via limitations

## Revisit Trigger
- If thermal or voltage drop issues appear
- If routing becomes overly constrained → consider upgrading stackup

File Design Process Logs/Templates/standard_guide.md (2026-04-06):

# Standard Entry Guide

Use this when:
- You define a rule used across the entire design
- You categorize behavior (e.g., component sizing, grounding)

Rules:
- Applies globally, not to one decision
- Should guide future decisions

Do NOT use for:
- One-off choices

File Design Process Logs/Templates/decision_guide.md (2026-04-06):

# Decision Entry Guide

Use this when:
- You choose between options
- The choice affects layout, architecture, or behavior

Rules:
- Keep all reasoning (do not compress thinking)
- Always include WHY
- Include risks even if uncertain

Do NOT use for:
- Small adjustments
- Ongoing exploration

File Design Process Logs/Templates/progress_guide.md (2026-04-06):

# Progress Log Guide

Reference example:
(see existing entries)

Use this when:
- You did work
- You changed layout or routing
- You discovered an issue

Tags:
- [WIP] → ongoing work
- [OPEN] → unresolved issue
- [DECISION] → major choice made
- [CONSTRAINT] → external limitation
- [TEST NEEDED] → unverified assumption

Rules:
- Keep entries short
- Always include why it mattered (1 line)
- Do NOT explain deeply (that belongs in decision files)

Structure:
- Bullet = action
- Sub-bullet = meaning

Daily Summary:
- Direction → what improved
- Risk → biggest concern
- Next Focus → next likely step

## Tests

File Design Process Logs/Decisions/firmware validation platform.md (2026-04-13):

# Firmware Validation Platform Architecture

**Date:** 2026-04-12

## Context
The original design aimed to integrate full system functionality on a custom nRF52840 PCB, including power management (LiPo charging, load switches), multiple I2C buses, and low-power optimization.

This introduced significant complexity in layout and bring-up:
- High GPIO demand exceeding available pins
- Increased routing complexity (multi-layer, power domains)
- Higher risk during initial firmware validation

A faster iteration path was needed to validate firmware, UI, and core functionality independently.

---

## Options Considered

- Option A: Continue full custom board  
  - Pros:
    - Direct path to final hardware
    - No migration required  
  - Cons:
    - Slower iteration
    - Higher debugging complexity
    - Firmware blocked by hardware issues

- Option B: Simplified dev board using XIAO nRF52840  
  - Pros:
    - Rapid bring-up
    - Reduced layout complexity (2-layer)
    - Known-good RF and power subsystem  
  - Cons:
    - Limited GPIO
    - Missing system features
    - Requires later migration

---

## Decision
Adopt a dedicated firmware validation platform using the XIAO nRF52840.

This platform:
- Prioritizes firmware and UI validation
- Uses a simplified 2-layer PCB
- Removes non-critical systems (charger, load switching, secondary I2C)
- Preserves physical layout for key interfaces (switches and displays)

---

## Why
Iteration speed is the primary constraint.

Separating firmware from full hardware:
- Enables independent firmware development
- Reduces compounded debugging complexity
- Allows faster iteration cycles

---

## Implementation Notes

- Removed due to GPIO limits:
  - Load switches
  - Secondary I2C bus

- Converted to 2-layer PCB
- Simplified power distribution (rear-layer zones)
- Updated components to 0603 where practical
- Added bypass jumpers for LiPo anti-drain circuit
- Maintained placement for:
  - Key switches
  - OLED displays
- Added board extension to accommodate XIAO module

Planned:
- AS5600 + hall sensor breakout boards
  - Include I2C pull-ups
  - Add protection components for reuse

---

## Risks / Unknowns

- Firmware may depend on simplified hardware assumptions
- Migration risks:
  - Power sequencing differences
  - I2C loading changes
  - GPIO reassignment conflicts
- Load switching and low-power behavior not validated
- Breakout boards may not reflect final signal integrity

---

## Revisit Trigger

- Firmware reaches stable baseline:
  - Input handling
  - Display control
  - Encoder behavior

- Need to validate:
  - Power system
  - Multi-device I2C
  - Battery management

---

## Notes

Firmware must use assignable / abstracted pin definitions.

Failure to enforce this will significantly increase migration difficulty.

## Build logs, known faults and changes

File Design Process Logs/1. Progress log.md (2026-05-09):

[2026-03-26]

- Performed component size analysis [WIP]
  - Evaluated physical constraints of major components
  - Informed feasibility of compact layout

---

[2026-03-27]

- Investigated crystal selection ambiguity [OPEN]
  - Identified uncertainty in correct spec / configuration
  - Flagged for clarification before final schematic lock

---

[2026-03-28]

- Evaluated nRF52840 package options [DECISION]
  - Identified limitation: QFN48 lacks USB support 
  - Confirmed VDD/VDDH constraints and lack of USB HID capability
  - Transitioned to USB-capable package (aQFN73)

- Established single-MCU architecture direction [DECISION]
  - Rejected dual-MCU USB bridge approach (complexity + power concerns)

- Defined early power architecture approach [WIP]
  - Evaluating battery + USB power interaction
  - Considering charging + runtime scenarios

---

[2026-04-02]

- Switched to chip antenna layout (Johanson 2450AT07A0100001T) [DECISION]
  - Prioritized gain and compact size over layout flexibility
  - Will rely on reference layout due to lack of RF validation tools [TEST NEEDED]

- Moved keyswitch routing to Layer 2 [DECISION]
  - Improved fanout and routing cleanliness

- Continued refinement of key placement [WIP]
  - Adjusting layout to support routing strategy

- Locked into JLCPCB standard constraints [CONSTRAINT]
  - 0.127 mm traces, 0.1 mm spacing
  - 0.2 mm power traces where possible
  - No blind/buried vias, no via-in-pad under NRF

- Increased display count from 1 → 2 I2C OLEDs [DECISION]
  - Shared bus configuration
  - Intended for per-corner key assignment display (optional)

- Added footprint for I2C OLED module [DECISION]
  - Avoided full OLED integration due to library constraints

- Identified concern with USB-C placement near MCU + antenna [OPEN]
  - Considering relocation under wheel section

- Established 4-layer ground strategy [DECISION]
  
  - Layers 1 & 2: signal + partial ground fill
  - Layer 3: solid ground plane
  - Layer 4: power zones with partial ground plane

- Things to consider
    - Location of power circuitry/LIPo   Under Wheel or with keyswitches?
    - Unlocking MCU "grouping" to clean up traces.
    - USB placement relative to Antenna
    - Will Oleds interfere with the MCU signals below?

## 2026-04-06

- [Adjusted antenna GND zone clearance] [DECISION]
  - Reduced from 0.5mm → 0.127mm
  - Removed unintended copper pullback around antenna pads

- [Forced solid connection on antenna GND pads] [DECISION]
  - Disabled thermal relief on pads 2 and 3
  - Ensures proper RF grounding at matching network

- [Validated footprint-based keepout strategy] [WIP]
  - Confirmed antenna clearance region enforced via footprint rule areas
  - Maintains layout portability

- [Diagnosed copper pour behavior issue] [OPEN]
  - Initial issue resembled pad-based clearance halo
  - Root cause traced to zone clearance, not custom rules

### Daily Summary
- Direction: Antenna layout now behaves predictably and aligns closer to reference intent  
- Risk: RF performance still unverified (no measurement tools)  
- Next Focus: Validate surrounding geometry (top copper edge, USB proximity, inner layer clearance)

## 2026-04-06 2.0

- [Completed power circuitry routing] [WIP]
  - Core power path wired and integrated
  - Enables full system bring-up path

- [Placed reset and mode switches] [DECISION]
  - Reset moved to backside (diagnostic use only)
  - Top-side intended for full normal operation

- [Shifted sensor architecture to external breakout] [DECISION]
  - AS5600 + hall sensors likely off-board via 6-wire connection
  - Reduces board size pressure and routing complexity

- [Evaluated interconnect strategy for external sensors] [OPEN]
  - Considering ribbon cable vs compact connector
  - Impacts I2C routing, pull-ups, and mechanical layout

- [Deferred second AS5600 implementation] [DECISION]
  - Simplifies current revision and reduces routing overhead

- [Identified antenna layout issue] [OPEN]
  - Matching network not placed close enough to antenna
  - May degrade RF performance

- [Noted missing mechanical features] [OPEN]
  - No mounting holes defined yet
  - Impacts enclosure and usability

- [Evaluating board density strategy] [OPEN]
  - Large unused board space currently present
  - Tradeoff between compact layout vs functional separation (power vs MCU/USB)

- [Detected OLED footprint misalignment] [CONSTRAINT]
  - Screen not centered relative to footprint
  - True centering would require additional board space

- [Planned RGB LED integration] [WIP]
  - Add RGB LEDs and control rail to final design
  - Impacts power budget and routing

### Daily Summary
- Direction: Core system architecture stabilizing (power, IO structure, antenna identified issues)  
- Risk: Antenna layout + connector decisions may require rework  
- Next Focus: Finalize antenna geometry, choose connector strategy, begin layout tightening

- [Split internal and external wheel interconnect strategy] [DECISION]
  - Internal sensor/module link can use short fixed 1.25mm interconnect
  - External wheel should remain easily swappable via dedicated connector strategy

- [Considering modular external wheel interface] [WIP]
  - Main board may expose a 4-pin internal connector to an intermediate wheel interface
  - Preserves option for later pogo-pin or alternate external connector implementation

### Daily Summary
- Direction: Interconnect architecture is separating into permanent internal links vs serviceable external links
- Risk: External connector choice still depends on enclosure alignment and serviceability goals
- Next Focus: Define 4-pin pinout and decide whether external module is locking connector or pogo-based

## 2026-04-07

- Added two 2.54mm header options for external/peripheral I2C connections [WIP]
  - Added one 6-pin header and one 4-pin header to support modular display / sensor hookup options.
  - Why it mattered: keeps the board flexible while layout and peripheral grouping are still in flux.

- Standardized the first four pins of the 6-pin header to match the 4-pin header and display pinout [DECISION]
  - Shared pinout is Power, GND, SCL, SDA.
  - Why it mattered: reduces wiring ambiguity and allows the same screen pin order to be reused across connector options.

- Added both pin-header and socket/header-side schematic support with hall sensors and AS5600s placed beyond the connectors [WIP]
  - Connectorized sensor/display branches are now present in schematic so footprints can be deleted later depending on final architecture.
  - Why it mattered: preserves optionality without needing to redraw the schematic each time the connector plan changes.

- Removed the third load switch from the design [DECISION]
  - Current plan now assumes two screens and one AS5600 can share one switched rail.
  - Why it mattered: simplifies power switching and reduces part count if grouped-load current stays reasonable.

- Left open the grouping split between displays and AS5600 devices across the two switched branches [OPEN]
  - May move to one rail for both AS5600s and the other for both screens instead of a mixed grouping.
  - Why it mattered: final grouping affects power budget, startup behavior, and how cleanly peripherals can be selectively disabled.

- Need to confirm worst-case current draw for two I2C OLEDs on one switched rail [TEST NEEDED]
  - Question remains whether two OLED modules together could exceed the intended ~150 mA load-switch budget.
  - Why it mattered: this determines whether the current 2-switch plan is safe or whether power partitioning needs to change.

### Daily Summary
- Direction: connector strategy is getting more modular and the schematic now supports easier footprint pruning later.
- Risk: OLED current draw may be high enough to make the current load grouping marginal depending on screen type and brightness.
- Next Focus: verify display current worst-case, then lock which peripherals share each switched rail.

## 2026-04-09

- RF / layout review updates [WIP]
  - Ran the board past a layout engineer with high-speed SerDes experience and applied a broad set of cleanup changes.
  - Why it mattered: external review helped catch layout quality issues before committing further.

- Antenna network thermal relief change [DECISION]
  - Removed thermal pad connections for the antenna pi network.
  - Why it mattered: reduces unnecessary impedance and parasitic effects in the RF matching path.

- USB routing review [WIP]
  - Reviewed USB high-speed routing assumptions, added/checked surrounding ground stitching, and kept unrelated signals away from the pair.
  - Why it mattered: improves confidence in signal integrity for the USB path.

- USB layer interaction note [OPEN]
  - Noted the remaining question around possible impedance discontinuity from signals on inner layers beneath the USB routing, though current judgment is that it is likely a non-issue because the crossed lines are functionally static.
  - Why it mattered: records the last known uncertainty instead of losing it.

- PDN geometry cleanup [WIP]
  - Cleaned up acute angles in the power distribution routing.
  - Why it mattered: improves manufacturability and general layout quality.

- Metal 4 power plane update [DECISION]
  - Reworked metal 4 into a 4-zone plane: 3.3V, Load1, Load2, and remaining ground.
  - Why it mattered: supports cleaner power distribution and reduces resistive drop versus narrower routed distribution.

- Ground plane opening cleanup [WIP]
  - Removed / corrected odd via-related ground plane openings near traces.
  - Why it mattered: avoids unnecessary plane disturbance and keeps return paths cleaner.

- Power trace width increase [DECISION]
  - Increased USB 5V and LiPo power paths to 0.75 mm to reduce IR drop.
  - Why it mattered: aligns better with low-drop power delivery practice and supports the broader plane-based power strategy.

### Daily Summary
- Direction: Layout quality and power distribution improved through outside review and targeted cleanup.
- Risk: Remaining uncertainty is mainly around whether the USB routing sees any meaningful discontinuity from underlying inner-layer signals.
- Next Focus: Final USB sanity check, then broader DRC / manufacturability pass before calling the layout stable.

## 2026-04-10

- Test pads added for key debug and power nodes. [WIP]
  - Power cell, USB VBUS, charger line, 3.3V
  - Load1, Load2, Load1 CTRL, Load2 CTRL
  - Hall sensor, I2C lines, cell monitor
  - SWDCLK, SWDIO
  - Improves bring-up, power validation, and firmware recovery access

- Two spare test pads added. [WIP]
  - Reserved for future debug needs or late-stage signal access
  - Provides flexibility if gaps are found during bring-up

- USB D+ and D− test pads omitted. [DECISION]
  - Existing access is sufficient for probing
  - Avoids unnecessary disturbance to higher-speed USB routing

- RGB support removed from design. [DECISION]
  - Addressable LED options conflicted with low-power supply architecture (voltage requirements)
  - Prevents non-essential feature from complicating power design

### Daily Summary
- Direction: Improved debug accessibility and simplified overall design
- Risk: Potential missing probe points may still appear during bring-up
- Next Focus: Mount holes and final manufacturability cleanup

## 2026-04-10

- Investigated PCB FEM / PDN simulation workflow [WIP]
  - Explored KiCad → SALOME → Elmer path
  - Why it mattered: determine feasibility of full-board analysis before committing time

- Identified geometry and tooling limitations [CONSTRAINT]
  - SALOME cannot selectively ignore traces without pre-separated geometry
  - KiCad exports do not provide usable per-trace control
  - Why it mattered: blocks practical simplification of real PCB layout

- Evaluated alternative PDN tooling options [WIP]
  - Looked for KiCad-integrated PDN tools and plugins
  - Determined no mature or maintained solution exists
  - Why it mattered: confirmed lack of lightweight analysis path

- Aborted full-board simulation approach [DECISION]
  - Shifted toward targeted simulation + standard design practice
  - Why it mattered: avoids time sink with low expected return

### Daily Summary
- Direction: Narrowed analysis strategy to only high-value simulation targets (RF, possibly thermal)
- Risk: Reduced visibility into second-order PDN / SI effects
- Next Focus: Define targeted simulation scope (antenna region) or return to layout refinement

## 2026-04-12

- Rebuilt board around XIAO nRF52840 dev module [DECISION]
  - Shifted from full custom MCU layout to dev-focused architecture to accelerate firmware bring-up

- Reduced board to 2-layer design [DECISION]
  - Simplifies fabrication and iteration speed for early-stage testing

- Removed load switches, charger circuit, and secondary I2C bus [CONSTRAINT]
  - GPIO limitations on XIAO forced reduction in feature set

- Redesigned rear layer power zones [WIP]
  - Adjusted for simplified power distribution without multi-rail switching

- Moved select components to 0603 [STANDARD]
  - Improves hand assembly reliability for rapid iteration

- Added bypass jumpers for LiPo anti-drain circuit [TEST NEEDED]
  - Allows flexible validation of power behavior vs protection circuitry

- Maintained key switch and display placement [WIP]
  - Preserves mechanical/UI consistency across design iterations

- Added board bump-out for XIAO module [CONSTRAINT]
  - Required to physically accommodate prebuilt module footprint

- Defined dev board scope (not optimized for low power) [DECISION]
  - Prioritizes functionality testing over power optimization

- Planned AS5600 + hall sensor breakout boards [WIP]
  - Will include I2C pull-ups and protection to make modules reusable

### Daily Summary
- Direction:
  Strong pivot toward a functional dev platform instead of full system complexity

- Risk:
  Reduced visibility into final architecture (power + switching behavior)

- Next Focus:
  Design and validate AS5600 breakout modules

  ## 2026-04-13

- Updated via strategy across the full board model [DECISION]
  - Increased constrained VIP/BGA escape vias from 0.15 mm hole to 0.2 mm hole.
  - Cleaned up general vias to a 0.3 / 0.5 mm minimum where space allowed.
  - This was primarily driven by JLC cost structure, since 0.2 mm vias are substantially cheaper than 0.25 mm-class handling.

- Adjusted local silkscreen placement [WIP]
  - Repositioned silkscreen markings to reduce conflicts with dense layout regions.
  - Labeling around the nRF remains crowded, since readable text cannot practically be reduced below 1 mm in the available space.

- Pulled edge ground vias back near the antenna region [DECISION]
  - Shifted edge stitching slightly inward near the board cutout area.
  - This avoids conflicts with board edge/cutout constraints and keeps the antenna-edge region cleaner.

- Reduced unnecessary edge ground stitching on the far board edges [DECISION]
  - Dropped dedicated ground stitch vias on the farthest board edges.
  - Keyswitch ground through-holes already provide sufficient grounding/stitching function in those areas.

- Adjusted impedance assumptions for Tg155 laminate [CONSTRAINT]
  - Compared NP-155FR Dk (~4.3 @ 1 GHz) against prior Tg135-based assumptions (~4.5–4.7)
  - Resulting trace width correction (~0.336 → ~0.330 mm) falls within JLC ±0.02 mm tolerance
  - No layout change made; variation dominated by fabrication tolerance, not material shift

### Daily Summary
- Direction: Via strategy was cleaned up for lower fabrication cost and more consistent manufacturability, while edge and silkscreen details were refined.
- Risk: Dense silkscreen around the nRF remains compromised and may require accepting partial labeling or off-part references.
- Next Focus: Verify the updated via set against final DRC/fab assumptions and decide how much local silkscreen near the nRF is worth keeping.
- Consider small packakage adjustments to reduce cost.
- Removing 0201 components and finding a different load switch package will save $25 in "advanced setup"
- reduction in number of different components will save on feeder fees $1.58 per
- PCBA BOM not complete. some components lacking references
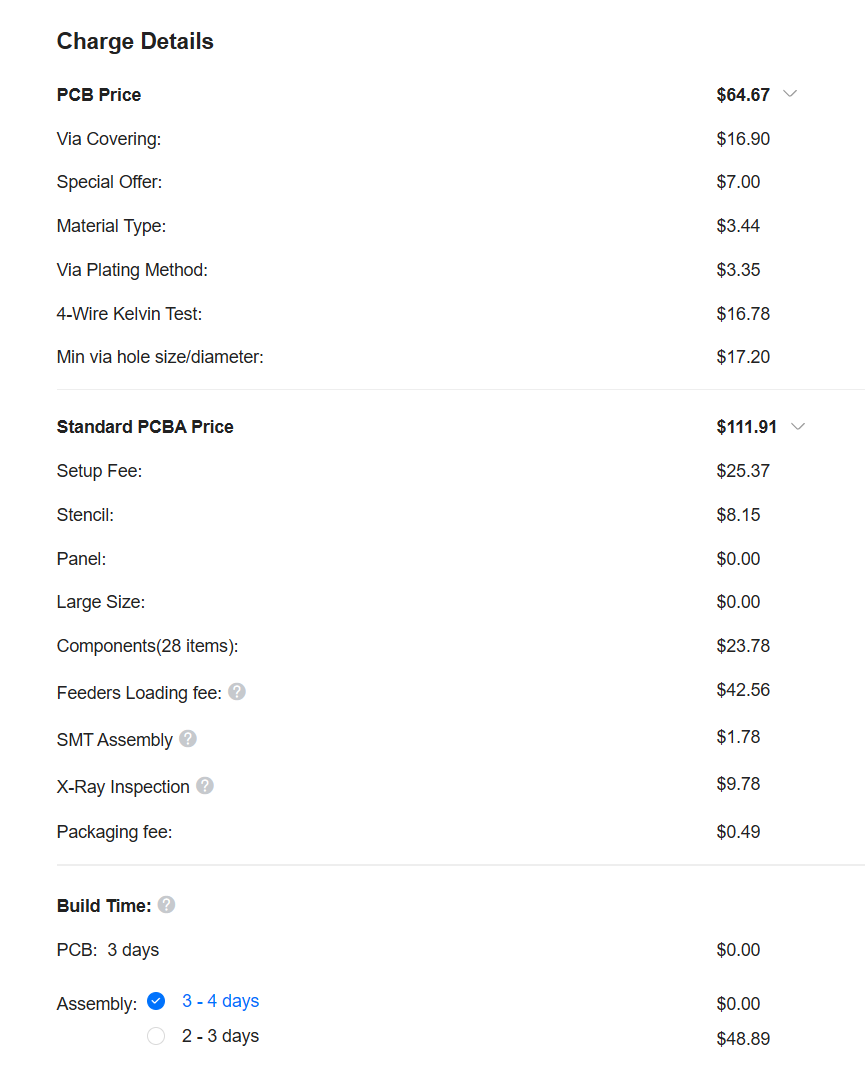
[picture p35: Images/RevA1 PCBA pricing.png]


## 2026-04-15

- Switched load switch selection from TPS22916 to TPS22860 [DECISION]
  - Moved to the SOT-23 package for easier assembly and more practical layout handling.
  - Acceptable because switched rail current is expected to stay well below the 200 mA limit.

- Added recommended local decoupling for the new load switch [WIP]
  - Added 1 µF and 100 nF capacitors per documentation.
  - Improves local stability and keeps the implementation aligned with the intended use of the part.

- Rerouted the affected area to support the new package and capacitor placement [WIP]
  - Updated surrounding routing and placement to fit the larger package and support components.
  - Keeps the power switching section clean and manufacturable after the part swap.

- Retained dual switched rails even though one switch could support the expected load [DECISION]
  - Kept separate switched domains for modular bring-up sequencing: OLEDs first, then encoders.
  - Preserves staged debugging and subsystem isolation during early validation.

- Accepted higher RDS(on) in exchange for lower leakage and better package practicality [DECISION]
  - TPS22860 has higher on-resistance than the previous part, but load current is low enough that the added active loss is not a concern.
  - Priority remains low leakage current and easier implementation, not minimizing a small increase in active power consumption.

### Daily Summary
- Direction: Load switch implementation was simplified mechanically while preserving low-leakage behavior and staged subsystem bring-up.
- Risk: Need to confirm real switched-rail current stays comfortably below the 200 mA limit during worst-case OLED and encoder activity.
- Next Focus: Verify rail current in expected operating modes and confirm the revised switched section behaves cleanly in layout and bring-up.

## 2026-04-17

- [Firmware architecture split into input/output modules] [WIP]
  - Separated encoder, buttons, USB HID transport, and display planning into distinct modules rather than keeping logic in one sketch
  - This matters because the project is moving from test code into a reusable firmware structure

- [USB HID transport validated on working PlatformIO environment] [DECISION]
  - Isolated a PlatformIO environment that preserves serial and allows successful USB keyboard output
  - This matters because firmware bring-up can now continue without repeatedly falling back to bootloader recovery

- [Encoder migrated from Arduino test sketch into modular firmware] [WIP]
  - Ported AS5600 read, wrap-diff math, and step generation into a dedicated encoder module
  - This matters because the wheel now has a reusable input path independent of direct HID send code

- [Encoder USB keypress repeat issue traced to HID release timing] [DECISION]
  - Determined that the apparent “freewheeling” behavior was caused by key release timing rather than the encoder math itself; increasing release delay from 1 ms to 2 ms resolved the stuck-repeat behavior
  - This matters because it avoids chasing the wrong root cause in the encoder logic

- [Buttons module separated from keymap logic] [DECISION]
  - Established that GPIO scanning, debounce, and edge detection belong in a dedicated buttons module rather than in keymap handling
  - This matters because it keeps hardware input, mapping, and HID transport from collapsing into one file

- [Dual OLED runtime UI layout defined] [WIP]
  - Defined OLED grouping as screen A = 5/6/1/2 and screen B = 7/8/3/4, with profile and last-command center fields
  - This matters because runtime display layout is now tied to the physical board arrangement rather than an abstract top/bottom split

### Daily Summary
- Direction: Core firmware is shifting from proof-of-concept sketches into a modular architecture with working USB HID and encoder input
- Risk: HID timing and shared I2C/display integration may still create interaction issues as more modules come online
- Next Focus: Bring up the dual OLEDs using a clean display-state interface, then connect the 8-button scan path into the same action pipeline

# Input Architecture Direction Established (System Button + Chord Model)

**Date:** 2026-04-20

## Summary

Defined a layered input architecture combining the system button, column chords, and encoder-driven interaction to support preset access, editing, and system-level controls.

## Key Updates

- Assigned the onboard system button as the primary **preset control interface**:
  - Tap: toggle between last two presets
  - Hold: open preset picker

- Established **column chords (top+bottom key pairs)** as reserved system-level entry points:
  - Used to enter specific contexts such as system menu, Bluetooth menu, encoder tools, and preset editing

- Defined **preset editor access as contextual**:
  - While in preset picker, pressing the preset editor chord opens the editor for the currently highlighted preset

- Established **encoder as the primary control mechanism** for:
  - Menu navigation
  - Value editing
  - Context-specific adjustments (e.g., sensitivity via hold chord)

- Identified distinction between:
  - Runtime controls (quick access)
  - Editing flows (deliberate)
  - System configuration (rare)

## Architectural Direction

Adopted a 4-tier input model:
1. Direct actions (keys + encoder)
2. Global access (system button)
3. Context entry (reserved chords)
4. Context execution (encoder + keys within modes)

## Notes

- Preset switching remains easily accessible without relying on chords
- Chords are reserved for entering system contexts, not performing actions directly
- Encoder-based adjustments (e.g., sensitivity) will be implemented as temporary hold-chord behaviors initially
- Full menu and edit flows still pending implementation

## Status

- Architecture defined
- Implementation partially complete
- Next steps include:
  - Wiring chord detection into action layer
  - Implementing preset picker behavior
  - Linking encoder configuration to profile changes

  ## 2026-04-20

- [Action] [DECISION]
  - Identified persistent internal storage as the next required architecture layer before deep preset editing
  - Presets are no longer treated as temporary hardcoded test data only; future behavior assumes presets must survive reboot

- [Action] [WIP]
  - Defined next-stage need for a config storage system to load/save the full keymap profile structure
  - Current plan is to keep a default known-good config and load a runtime config from internal memory at boot

- [Action] [CONSTRAINT]
  - Without persistence, preset switching and editing have limited practical value
  - Encoder settings, labels, active preset state, and future BLE/system settings all depend on a stable storage path

### Daily Summary
- Direction: Shifted from temporary bring-up logic toward a real persistent configuration architecture
- Risk: Storage implementation details and validation/CRC handling are not yet defined
- Next Focus: Define default config location, runtime config ownership, and load/save API for internal memory

- [Preset picker behavior implemented and validated] [WIP]
  - System button tap toggles presets, hold opens picker, encoder scrolls, release confirms selection
  - This matters because preset interaction is now functional and matches the defined input architecture

- [System button hold-release behavior corrected for preset picker] [DECISION]
  - Initial implementation caused picker to close on release after hold; added suppression flag to ignore first release event
  - This matters because it enables proper “hold to enter, release to interact” behavior instead of requiring button hold during navigation

- [Display redraw moved to event-driven model] [DECISION]
  - Replaced continuous redraw loop with action-layer-driven dirty flag and mode-change detection
  - This matters because constant OLED updates were interfering with encoder responsiveness due to shared I2C bus usage

- [Preset picker UI separated from quadrant display renderer] [DECISION]
  - Introduced dedicated preset picker rendering path instead of reusing quadrant layout
  - This matters because menu-style interfaces do not map cleanly to key-label quadrant rendering and require independent layout logic

- [Preset picker render cache caused stale display on re-entry] [DECISION]
  - Menu did not redraw after first use due to cached highlight/mode state; resolved by invalidating or removing picker cache
  - This matters because UI state must be reset between menu sessions to avoid hidden state bugs

- [Keymap indexing mismatch caused incorrect key output vs displayed labels] [OPEN]
  - Observed mismatch between displayed label and emitted keycode; traced to keymap indexing alignment rather than input mapping
  - This matters because logical key ordering must remain consistent across display, mapping, and action layers

- [Encoder interaction tuned via mode-specific step thresholds] [WIP]
  - Introduced separate step counts for normal operation and preset picker navigation
  - This matters because UI navigation requires different responsiveness than HID key emission

  ## 2026-04-24

- [Rev A XIAO board received and inspected] [WIP]
  - Physical board arrived and initial fitment checks exposed several layout and footprint issues.
  - Why it mattered: Rev A successfully served its purpose as a firmware/mechanical validator rather than a final production board.

- [Keyswitch footprint issue identified] [OPEN]
  - Hotswap key sockets were placed as if they mounted on the front side of the PCB, but the selected sockets are rear-mounted for front-facing switches.
  - Why it mattered: Current footprints prevent the keyswitches from locating perfectly square and require correction before Rev B/full-board layout.

- [OLED pinout mismatch identified] [OPEN]
  - Design used a reference pin order of VCC / GND / SCL / SDA, while the final OLED module uses GND / VCC / SCL / SDA.
  - Why it mattered: The OLED module cannot be used as laid out without rework or a revised footprint/pinout.

- [OLED-to-key spacing reviewed] [WIP]
  - Screen position relative to the keys may be slightly too tight.
  - Why it mattered: Rev B should slightly open the spacing to improve assembly tolerance and visual/mechanical comfort.

- [Rear-mounted component strategy considered] [OPEN]
  - Considering moving most non-through-hole components to the rear of the final board, while keeping THT/mechanical user-facing items on the front.
  - Why it mattered: Rear mounting may improve test pad accessibility and simplify front-side user interface geometry.

- [Charge indicator visibility reconsidered] [OPEN]
  - If components move to the rear, the charge indicator LED may need a side light pipe or alternate visibility strategy.
  - Why it mattered: The LED is one of the few components with a user-facing reason to remain visible.

- [OLED module vs onboard SSD1306 reconsidered] [OPEN]
  - Considering whether the final board should continue using an OLED module or move to an onboard SSD1306/display implementation.
  - Why it mattered: This choice affects connector/pinout risk, component placement, assembly complexity, and final enclosure/display integration.

### Daily Summary
- Direction: Rev A exposed exactly the kind of physical integration problems the validator board was meant to catch.
- Risk: Footprint/pinout assumptions from modules and reference symbols are now the biggest Rev B layout risk.
- Next Focus: Correct keyswitch socket orientation/footprints, verify OLED pinout strategy, and decide whether final-board components should be rear-mounted.

## 2026-04-24

- [Rev B XIAO board layout updates] [WIP]
  - Incorporated mechanical and electrical corrections identified from Rev A bring-up.
  - Why it mattered: Moves design closer to a manufacturable and reliable final architecture.

- [OLED pinout flexibility added via jumper system] [DECISION]
  - Removed fixed power/ground plane connections and replaced with 3-pad jumper configuration.
  - Default configuration supports GND / VCC / SCL / SDA, with reversible option via trace cut and re-bridge.
  - Why it mattered: Eliminates dependency on inconsistent OLED module pinouts and prevents Rev A-style mismatch failures.

- [Keyswitch positioning adjusted] [WIP]
  - Shifted keyswitches 1mm toward board edge while maintaining board outline.
  - Why it mattered: Improves mechanical fit and alignment based on Rev A observations.

- [Keyswitch orientation revised] [WIP]
  - Rotated one row of switches to mirror across horizontal axis instead of matching prior orientation.
  - Why it mattered: Likely improves routing symmetry and/or usability depending on layout intent.

- [Keyswitch mounting method changed] [DECISION]
  - Replaced hotswap sockets with direct soldered switch connections.
  - Why it mattered: Removes footprint ambiguity, reduces mechanical tolerance issues, and improves reliability for a compact board.

### Daily Summary
- Direction: Rev B is shifting from “validation board” to “intentional hardware design,” reducing ambiguity in both pinout and mechanical interfaces.
- Risk: Jumper-based OLED routing introduces potential user error and signal integrity concerns if not laid out cleanly.
- Next Focus: Validate jumper routing integrity, and re-check front/rear component strategy before finalizing placement.

## 2026-04-27

- Updated power connector placement [WIP]  
  - Moved for improved routing and mechanical accessibility

- Switched primary connectors to JST right-angle variants (2-pin, 4-pin, 6-pin) [DECISION]  
  - Improves cable management and board edge usability

- Retained 2.54mm connectors in parallel [CONSTRAINT]  
  - Allows use of existing inventory and flexibility during bring-up

- Evaluated alternative connector systems (Molex PicoBlade, FPC) [OPEN]  
  - Potential for final design refinement, especially for main encoder interface

- Main encoder connector may migrate to higher-density option [OPEN]  
  - Balances robustness vs space; not locked yet

- Sub-encoder connector remains JST [DECISION]  
  - External interface ambiguity favors simpler, field-friendly connector

- Considered OLED harness cutaway routing feature [DECISION]  
  - Dismissed due to added mechanical complexity with minimal benefit

- Updated 4-pin and 6-pin connectors to rotational symmetry [DECISION]  
  - Increases layout complexity, but keeps wire order consistent per connector
  - Allows the 4-pin connector to physically fit into the 6-pin position without changing wiring order
  - Reduces harness/pinout confusion despite added PCB routing complexity

- Added silkscreen labeling for connector clarity [WIP]  
  - Mitigates wiring ambiguity from connector symmetry

- Noted connector compatibility risk from 4-pin/6-pin symmetry [OPEN]  
  - Cross-fit behavior must be documented to avoid incorrect assumptions during assembly

### Daily Summary
- Direction: Cleaner connector strategy forming; moving toward more intentional I/O architecture  
- Risk: Connector cross-compatibility could cause incorrect population if undocumented  
- Next Focus: Lock connector standard for Rev C and define pinout/keying strategy
- RevB sent for Fab

## 2026-05-09

- [System Bring-Up] [WIP]
  - V2 dev board powered and functional
  - Encoder (AS5600L @ 0x40) reading raw angle correctly
  - Full motion pipeline verified (angle → diff → accum → step → action → HID)
  - Why it mattered: confirms end-to-end firmware path is valid and hardware is operational

- [Bug Fix] [DECISION]
  - HID keypress failure traced to repeated `Wire.begin()` from I2C scanner
  - Removing redundant initialization restored USB HID functionality
  - Why it mattered: establishes that I2C init must be owned centrally (setup only)

- [Hardware Observation] [CONSTRAINT]
  - JST connectors not ideal for final design
  - Vertical connector footprint too tight; right-angle footprint preferred and should be enforced
  - Why it mattered: impacts assembly reliability and usability

- [Hardware Observation] [DECISION]
  - Removed I2C pullups from sensor board
  - System now relies on OLED onboard pullups
  - Why it mattered: avoids parallel pullup reduction and bus instability (previous 4.7k issue)

- [Architecture Update] [DECISION]
  - Encoder system refactored to support multi-instance (A/B abstraction)
  - Action layer updated to use encoder ID instead of global calls
  - Why it mattered: enables future second encoder without redesign

- [Firmware Insight] [OPEN]
  - AS5600L requires explicit address handling vs AS5600 fixed address assumption
  - Library differences between AS5600 and AS5600L confirmed
  - Why it mattered: prevents future integration confusion

### Daily Summary

- Direction:
  - System stable from sensor input → HID output
  - Hardware + firmware integration baseline achieved on V2

- Risk:
  - I2C initialization order can silently break unrelated subsystems (USB timing)
  - Connector selection/layout may require revision before final board spin

- Next Focus:
  - Implement BLE HID transport
  - Begin power characterization (BLE vs USB, idle vs active)
  - Validate sleep / wake behavior with sensors.

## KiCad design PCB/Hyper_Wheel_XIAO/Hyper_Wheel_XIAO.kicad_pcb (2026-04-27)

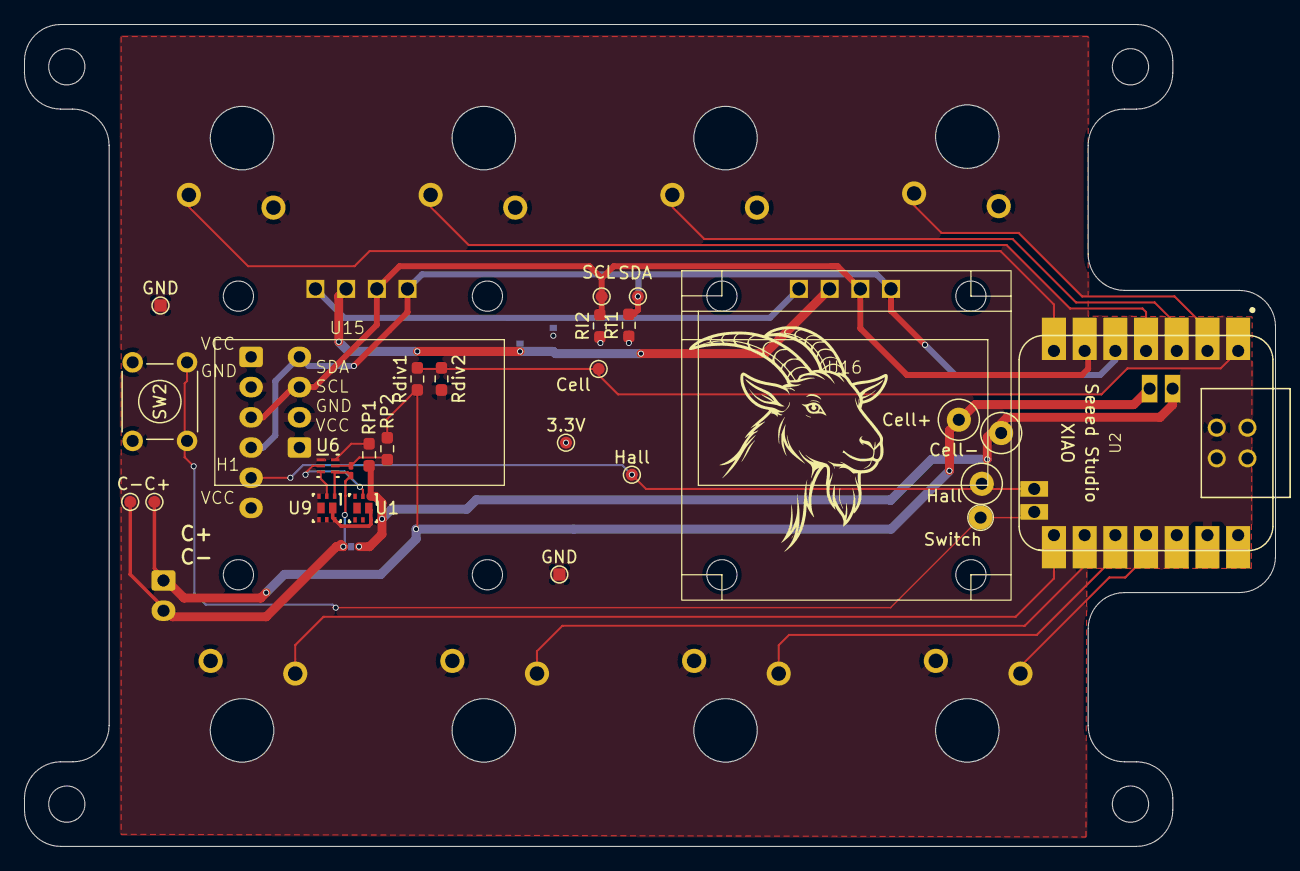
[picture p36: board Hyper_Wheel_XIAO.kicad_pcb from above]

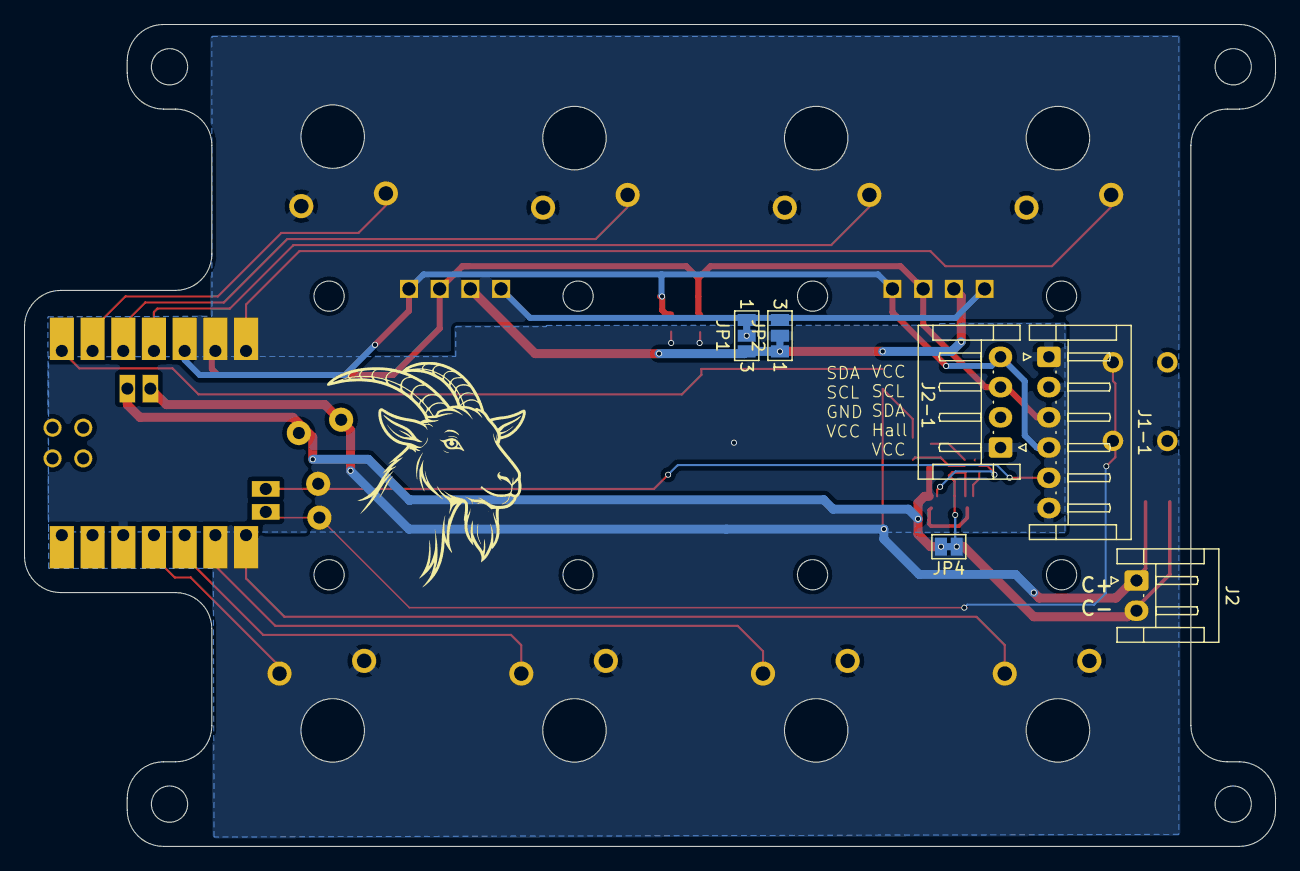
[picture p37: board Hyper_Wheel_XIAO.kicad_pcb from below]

Board: 2 copper layers, 103.5 x 68.0 mm, 41 parts (6 on the bottom side), 25 nets.

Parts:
3.3V: TestPad; TestPoint_Pad_D1.0mm
C+: TestPad; TestPoint_Pad_D1.0mm
C-: TestPad; TestPoint_Pad_D1.0mm
CH1, CH2, CH3, CH4, CH5, CH6, CH7, CH8: KS33_SW_HS; SW_KS33_1u
CP1: 0.1u; C_0201_0603Metric_Pad0.64x0.40mm_HandSolder
Cell: TestPad; TestPoint_Pad_D1.0mm
Cell+: TestPoint; TestPoint_Plated_Hole_D2.0mm
Cell-: TestPoint; TestPoint_Plated_Hole_D2.0mm
GND: TestPad; TestPoint_Pad_D1.0mm
GND#2: TestPad; TestPoint_Pad_D1.0mm
Hall: TestPoint; TestPoint_Plated_Hole_D2.0mm
Hall#2: TestPad; TestPoint_Pad_D1.0mm
J1-1: Conn_01x06_Socket; JST_EH_S6B-EH_1x06_P2.50mm_Horizontal
J2: LIPO; JST_EH_S2B-EH_1x02_P2.50mm_Horizontal
J2-1: Conn_01x04_Socket; JST_EH_S4B-EH_1x04_P2.50mm_Horizontal
JP1, JP2: Jumper_3_Bridged12; SolderJumper-3_P1.3mm_Bridged12_Pad1.0x1.5mm_NumberLabels
JP4: Jumper_2_Bridged; SolderJumper-2_P1.3mm_Bridged_Pad1.0x1.5mm
RI1, RI2: 4.7k; R_0603_1608Metric_Pad0.98x0.95mm_HandSolder
RP1: 2.2k; R_0603_1608Metric_Pad0.98x0.95mm_HandSolder
RP2: 330; R_0603_1608Metric_Pad0.98x0.95mm_HandSolder
Rdiv1: 150k; R_0603_1608Metric_Pad0.98x0.95mm_HandSolder
Rdiv2: 300k; R_0603_1608Metric_Pad0.98x0.95mm_HandSolder
SCL: TestPad; TestPoint_Pad_D1.0mm
SDA: TestPad; TestPoint_Pad_D1.0mm
SW2: SW_Push; SW_TH_Tactile_Omron_B3F-100x
Switch: TestPoint; TestPoint_Plated_Hole_D2.0mm
U1, U9: CSD85301Q2; CDS85301-DQK0006B
U2: Seeed Studio XIAO nRF52840; XIAO-nRF52840-Sense-14P-THTMOD
U6: BQ29700DSER; BQ29700-DSE0006A
U15, U16: OLED 128x64

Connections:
3.3V_Regulated: 3.3V.1 (Pin_1_1), J1-1.1, J1-1.6, J2-1.1, JP2.2 (C), RI1.1, RI2.1, U2.12 (3V3)
/Cell-: Cell-.1 (1_1), JP4.2 (B), RP1.2, U1.1 (S1), U2.21 (BAT-)
/Cell_monitor: Cell.1 (Pin_1_1), Rdiv1.2, Rdiv2.1, U2.1 (P0.02_A0_D0)
/Hall_1: Hall.1 (1_1), Hall#2.1 (Pin_1_1), J1-1.5, U2.19 (P0.09_NFC1)
/I2C_1_SCL: J1-1.3, J2-1.3, RI2.2, SCL.1 (Pin_1_1), U2.6 (P0.05_A5_D5_SCL), U15.3 (SCL), U16.3 (SCL)
/I2C_1_SDA: J1-1.4, J2-1.4, RI1.2, SDA.1 (Pin_1_1), U2.5 (P0.04_A4_D4_SDA), U15.4 (SDA), U16.4 (SDA)
/Key1: CH1.1, U2.8 (P1.12_D7_RX)
/Key2: CH2.1, U2.9 (P1.13_D8_SCK)
/Key3: CH3.1, U2.10 (P1.14_D9_MISO)
/Key4: CH4.1, U2.11 (P1.15_D10_MOSI)
/Key5: CH5.1, U2.7 (P1.11_D6_TX)
/Key6: CH6.1, U2.4 (P0.29_A3_D3)
/Key7: CH7.1, U2.3 (P0.28_A2_D2)
/Key8: CH8.1, U2.2 (P0.03_A1_D1)
/Power Handling/Cell-: C-.1 (Pin_1_1), CP1.2, J2.2, JP4.1 (A), U6.4 (VSS), U9.1 (S1)
/Switch: SW2.1, Switch.1 (1_1), U2.20 (P0.10_NFC2)
ChargerOUT: C+.1 (Pin_1_1), Cell+.1 (1_1), J2.1, RP2.2, Rdiv1.1, U2.22 (BAT+)
GND: CH1.2, CH2.2, CH3.2, CH4.2, CH5.2, CH6.2, CH7.2, CH8.2, GND.1 (Pin_1_1), GND#2.1 (Pin_1_1), J1-1.2, J2-1.2, JP1.2 (C), Rdiv2.2, SW2.2, U2.13 (GND), U2.17 (GND)
unnamed: JP1.1 (A), JP2.3 (B), U15.1 (GND), U16.1 (GND)
unnamed: JP1.3 (B), JP2.1 (A), U15.2 (VCC), U16.2 (VCC)
unnamed: U1.6 (D1), U1.7 (D1), U9.6 (D1), U9.7 (D1)
unnamed: U1.2 (G1), U6.2 (COUT)
unnamed: CP1.1, RP2.1, U6.5 (BAT)
unnamed: U6.3 (DOUT), U9.2 (G1)
unnamed: RP1.1, U6.6 (V-)

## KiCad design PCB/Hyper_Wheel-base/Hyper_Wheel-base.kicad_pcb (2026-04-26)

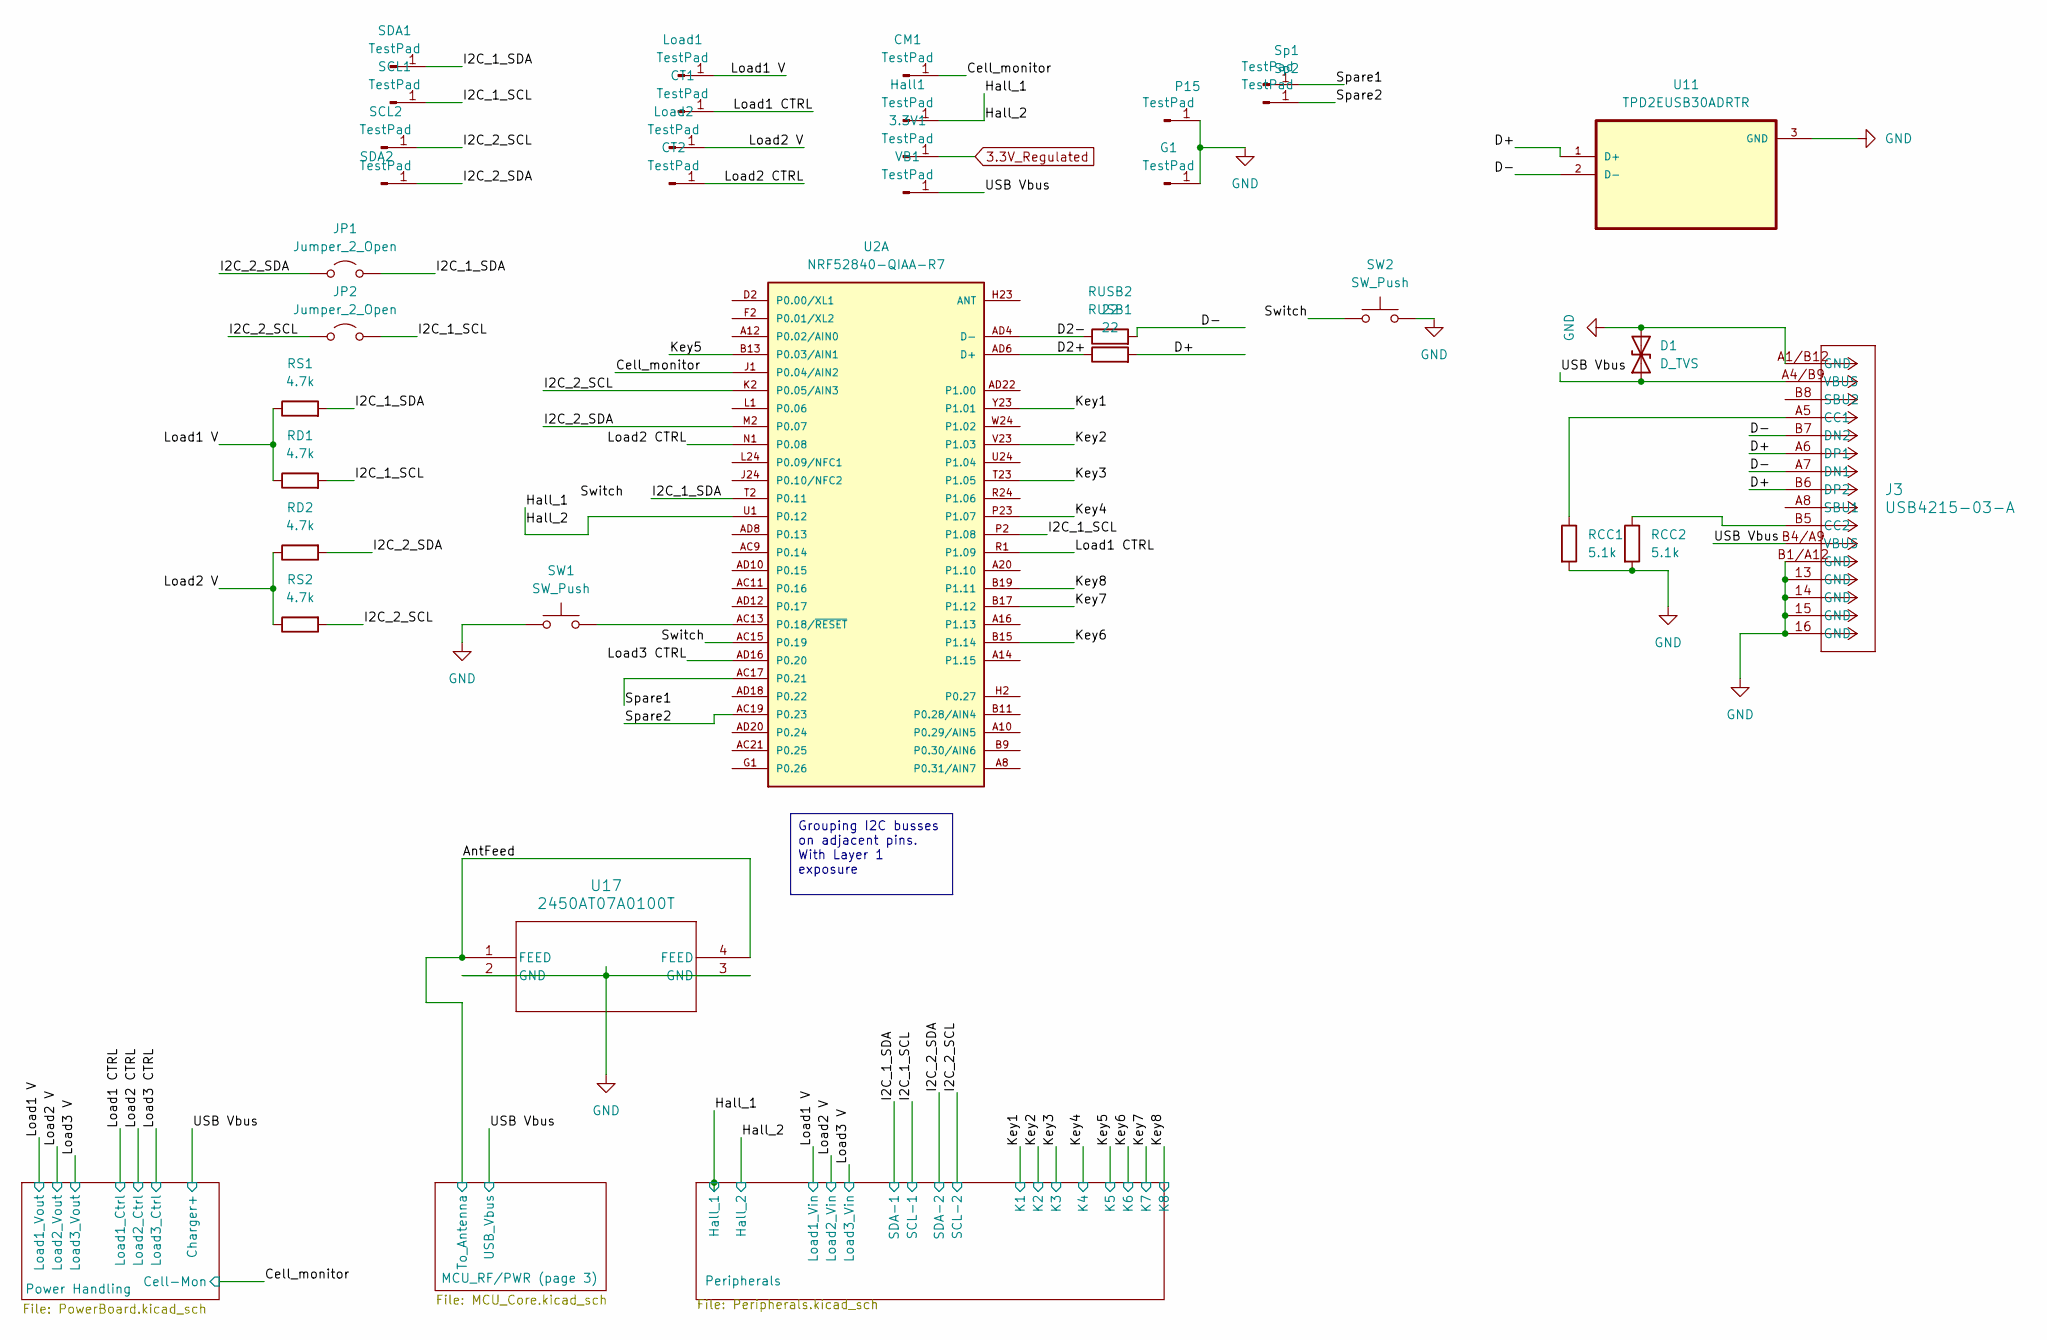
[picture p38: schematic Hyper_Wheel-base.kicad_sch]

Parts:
3.3V1: TestPad; TestPoint_Pad_D1.0mm
CM1: TestPad; TestPoint_Pad_D1.0mm
CT1, CT2: TestPad; TestPoint_Pad_D1.0mm
D1: D_TVS; D_0603_1608Metric
G1: TestPad; TestPoint_Pad_D1.0mm
Hall1: TestPad; TestPoint_Pad_D1.0mm
J3: USB4215-03-A; USBC-CONN_8p94X6p5X3p16_12L_GCC
JP1, JP2: Jumper_2_Open; SolderJumper-2_P1.3mm_Open_Pad1.0x1.5mm
Load1, Load2: TestPad; TestPoint_Pad_D1.0mm
P15: TestPad; TestPoint_Pad_D1.0mm
RCC1, RCC2: 5.1k; R_0402_1005Metric
RD1, RD2: 4.7k; R_0402_1005Metric
RS1, RS2: 4.7k; R_0402_1005Metric
RUSB1, RUSB2: 22; R_0402_1005Metric
SCL1, SCL2: TestPad; TestPoint_Pad_D1.0mm
SDA1, SDA2: TestPad; TestPoint_Pad_D1.0mm
SW1, SW2: SW_Push; SW_SPST_PTS647_Sx38
Sp1, Sp2: TestPad; TestPoint_Pad_D1.0mm
U2: NRF52840-QIAA-R7; NORDIC_NRF52840-QIAA-R7; PARTREV 1.2
U11: TPD2EUSB30ADRTR; SOT-323_SC-70
U17: 2450AT07A0100T; 2450AT07A0100T_JOT+Keepout
VB1: TestPad; TestPoint_Pad_D1.0mm

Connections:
3.3V_Regulated: 3.3V1.1 (Pin_1_1); also elsewhere on the board
/AntFeed: U17.1 (FEED), U17.4 (FEED); also elsewhere on the board
/Cell_monitor: CM1.1 (Pin_1_1), U2.J1 (P0.04/AIN2); also elsewhere on the board
/D2+: RUSB1.1, U2.AD6 (D+)
/D2-: RUSB2.1, U2.AD4 (D-)
/D+: J3.A6 (DP1), J3.B6 (DP2), RUSB1.2, U11.1 (D+)
/D-: J3.A7 (DN1), J3.B7 (DN2), RUSB2.2, U11.2 (D-)
/Hall_1: Hall1.1 (Pin_1_1), U2.U1 (P0.12); also elsewhere on the board
/I2C_1_SCL: JP2.2 (B), RD1.2, SCL1.1 (Pin_1_1), U2.P2 (P1.08); also elsewhere on the board
/I2C_1_SDA: JP1.2 (B), RS1.2, SDA1.1 (Pin_1_1), U2.T2 (P0.11); also elsewhere on the board
/I2C_2_SCL: JP2.1 (A), RS2.2, SCL2.1 (Pin_1_1), U2.K2 (P0.05/AIN3); also elsewhere on the board
/I2C_2_SDA: JP1.1 (A), RD2.2, SDA2.1 (Pin_1_1), U2.M2 (P0.07); also elsewhere on the board
/Key1: U2.Y23 (P1.01); also elsewhere on the board
/Key2: U2.V23 (P1.03); also elsewhere on the board
/Key3: U2.T23 (P1.05); also elsewhere on the board
/Key4: U2.P23 (P1.07); also elsewhere on the board
/Key5: U2.B13 (P0.03/AIN1); also elsewhere on the board
/Key6: U2.B15 (P1.14); also elsewhere on the board
/Key7: U2.B17 (P1.12); also elsewhere on the board
/Key8: U2.B19 (P1.11); also elsewhere on the board
/Load1 CTRL: CT1.1 (Pin_1_1), U2.R1 (P1.09); also elsewhere on the board
/Load1 V: Load1.1 (Pin_1_1), RD1.1, RS1.1; also elsewhere on the board
/Load2 CTRL: CT2.1 (Pin_1_1), U2.N1 (P0.08); also elsewhere on the board
/Load2 V: Load2.1 (Pin_1_1), RD2.1, RS2.1; also elsewhere on the board
/Load3 CTRL: U2.AD16 (P0.20)
/Spare1: Sp1.1 (Pin_1_1), U2.AC17 (P0.21)
/Spare2: Sp2.1 (Pin_1_1), U2.AC19 (P0.23)
/Switch: SW2.1, U2.AC15 (P0.19)
/USB Vbus: D1.1 (A1), J3.A4/B9 (VBUS), J3.B4/A9 (VBUS), VB1.1 (Pin_1_1); also elsewhere on the board
GND: D1.2 (A2), G1.1 (Pin_1_1), J3.13 (GND), J3.14 (GND), J3.15 (GND), J3.16 (GND), J3.A1/B12 (GND), J3.B1/A12 (GND), P15.1 (Pin_1_1), RCC1.2, RCC2.2, SW1.1, SW2.2, U11.3 (GND), U17.2 (GND), U17.3 (GND); also elsewhere on the board
unnamed: J3.A5 (CC1), RCC1.1
unnamed: J3.B5 (CC2), RCC2.1
unnamed: SW1.2, U2.AC13 (P0.18/~RESET)
unnamed 57: U2.H23 (ANT); also elsewhere on the board
unnamed 65: U2.D2 (P0.00/XL1); also elsewhere on the board
unnamed 66: U2.F2 (P0.01/XL2); also elsewhere on the board

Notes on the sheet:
Grouping I2C busses on adjacent pins. With Layer 1 exposure

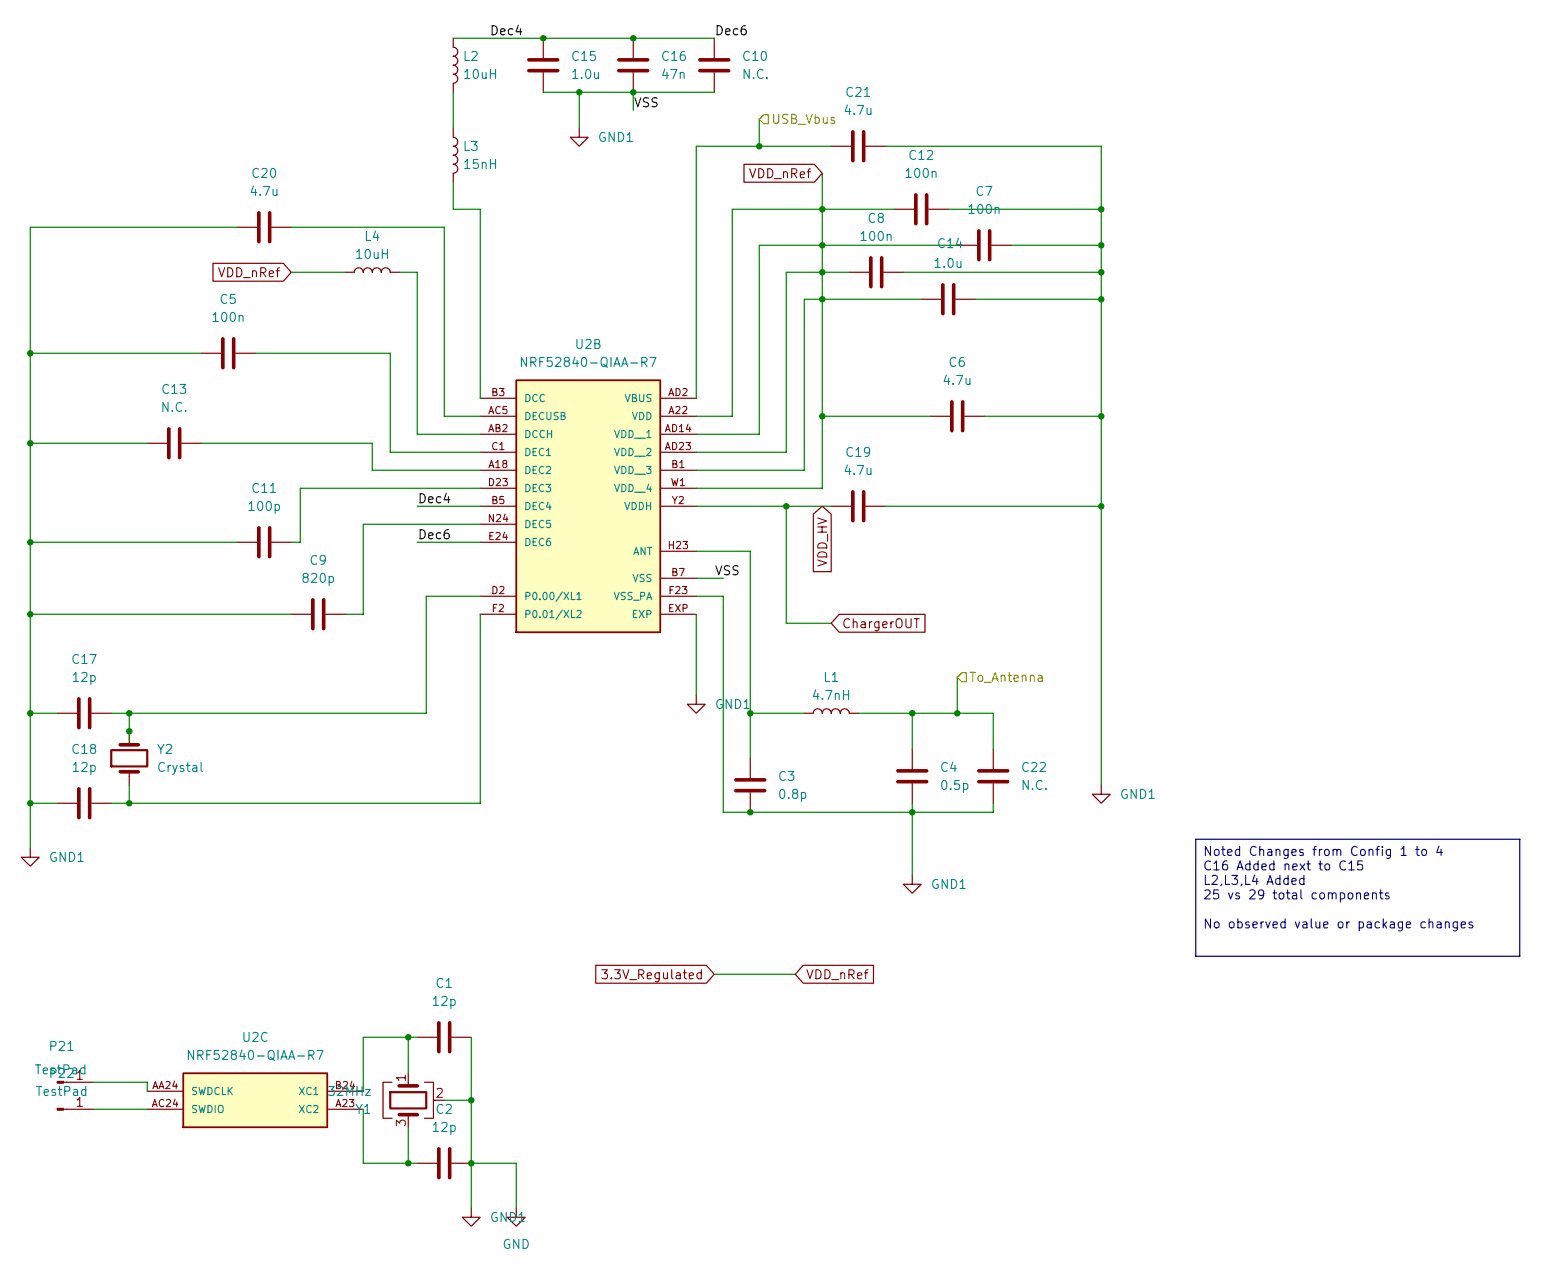
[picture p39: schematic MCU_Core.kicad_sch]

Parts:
C1, C2, C17, C18: 12p; C_0402_1005Metric
C3: 0.8p; C_0402_1005Metric
C4: 0.5p; C_0402_1005Metric
C5, C7, C8, C12: 100n; C_0402_1005Metric
C6, C19, C20, C21: 4.7u; C_0603_1608Metric
C9: 820p; C_0402_1005Metric
C10, C13, C22: N.C.; C_0402_1005Metric
C11: 100p; C_0402_1005Metric
C14, C15: 1.0u; C_0603_1608Metric
C16: 47n; C_0402_1005Metric
L1: 4.7nH; L_0402_1005Metric
L2, L4: 10uH; L_0603_1608Metric
L3: 15nH; L_0402_1005Metric
P21, P22: TestPad; TestPoint_Pad_D1.0mm
U2: NRF52840-QIAA-R7; NORDIC_NRF52840-QIAA-R7; PARTREV 1.2
Y1: 32MHz; Crystal_SMD_2016-4Pin_2.0x1.6mm
Y2: Crystal

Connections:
3.3V_Regulated: C6.1, C7.1, C8.1, C12.1, C14.1, L4.1, U2.A22 (VDD), U2.AD14 (VDD__1), U2.AD23 (VDD__2), U2.B1 (VDD__3), U2.W1 (VDD__4); also elsewhere on the board
/AntFeed: C4.2, C22.1, L1.2; also elsewhere on the board
/MCU_RF/PWR (page 3)/Dec4: C10.2, C15.2, C16.2, L2.1, U2.B5 (DEC4), U2.E24 (DEC6)
/USB Vbus: C21.1, U2.AD2 (VBUS); also elsewhere on the board
ChargerOUT: C19.1, U2.Y2 (VDDH); also elsewhere on the board
GND: C1.2, C2.2, C3.1, C4.1, C5.1, C6.2, C7.2, C8.2, C9.1, C10.1, C11.1, C12.2, C13.1, C14.2, C15.1, C16.1, C17.1, C18.1, C19.2, C20.1, C21.2, C22.2, U2.B7 (VSS), U2.EXP, U2.F23 (VSS_PA), Y1.2 (G), Y1.4 (G); also elsewhere on the board
unnamed: L2.2, L3.1
unnamed: P21.1 (Pin_1_1), U2.AA24 (SWDCLK)
unnamed: P22.1 (Pin_1_1), U2.AC24 (SWDIO)
unnamed: C3.2, L1.1, U2.H23 (ANT)
unnamed: L3.2, U2.B3 (DCC)
unnamed: L4.2, U2.AB2 (DCCH)
unnamed: C5.2, U2.C1 (DEC1)
unnamed: C13.2, U2.A18 (DEC2)
unnamed: C11.2, U2.D23 (DEC3)
unnamed: C9.2, U2.N24 (DEC5)
unnamed: C20.2, U2.AC5 (DECUSB)
unnamed: C17.2, U2.D2 (P0.00/XL1), Y2.2
unnamed: C18.2, U2.F2 (P0.01/XL2), Y2.1
unnamed: C1.1, U2.B24 (XC1), Y1.1
unnamed: C2.1, U2.A23 (XC2), Y1.3

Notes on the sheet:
Noted Changes from Config 1 to 4 C16 Added next to C15 L2,L3,L4 Added 25 vs 29 total components No observed value or package changes

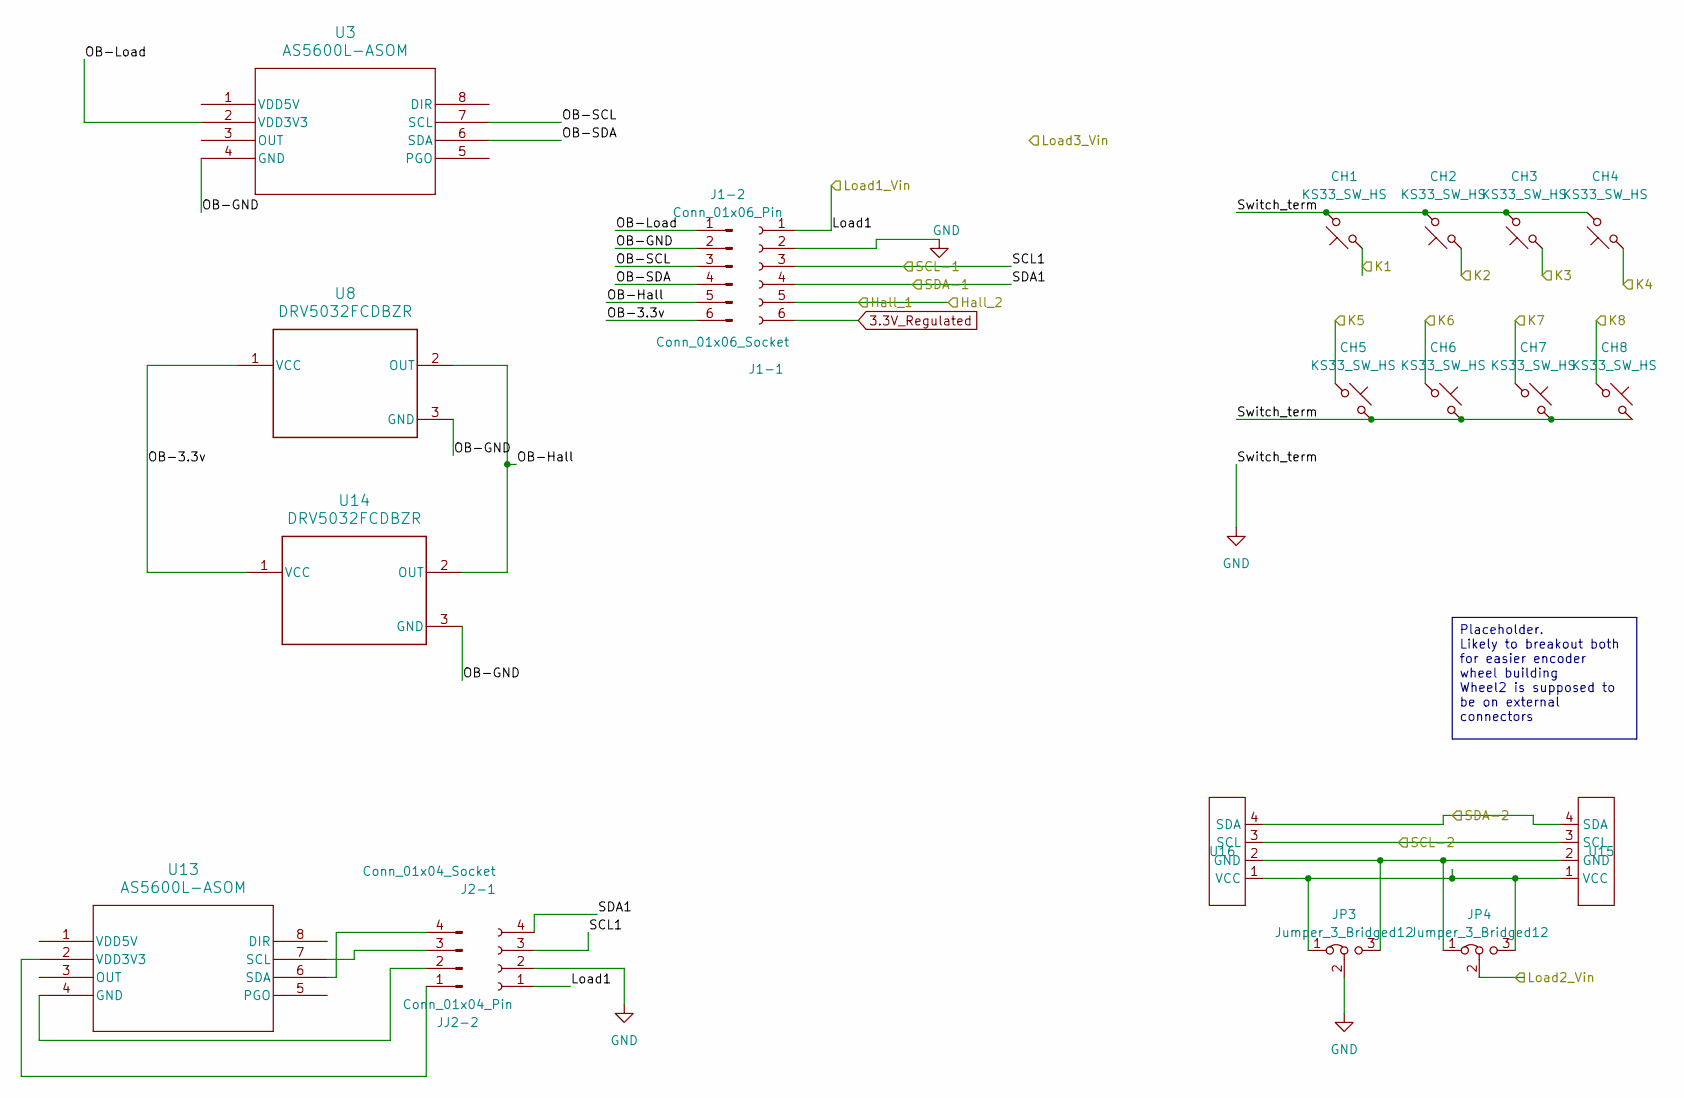
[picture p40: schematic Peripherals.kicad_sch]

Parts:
CH1, CH2, CH3, CH4, CH5, CH6, CH7, CH8: KS33_SW_HS; SW_KS33_HS_KS-2P02B01-02_HS_1u
J1-1: Conn_01x06_Socket; PinHeader_1x06_P2.54mm_Vertical
J1-2: Conn_01x06_Pin
J2-1: Conn_01x04_Socket; PinHeader_1x04_P2.54mm_Vertical
JJ2-2: Conn_01x04_Pin
JP3, JP4: Jumper_3_Bridged12; SolderJumper-3_P1.3mm_Bridged12_Pad1.0x1.5mm
U3, U13: AS5600L-ASOM; AS5600L-ASOM_AMS
U8, U14: DRV5032FCDBZR; DRV5032-DBZ0003A-IPC_A
U15, U16: OLED 128x64

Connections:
3.3V_Regulated: J1-1.6; also elsewhere on the board
/Hall_1: J1-1.5; also elsewhere on the board
/I2C_1_SCL: J1-1.3, J2-1.3; also elsewhere on the board
/I2C_1_SDA: J1-1.4, J2-1.4; also elsewhere on the board
/I2C_2_SCL: U15.3 (SCL), U16.3 (SCL); also elsewhere on the board
/I2C_2_SDA: U15.4 (SDA), U16.4 (SDA); also elsewhere on the board
/Key1: CH1.1; also elsewhere on the board
/Key2: CH2.1; also elsewhere on the board
/Key3: CH3.1; also elsewhere on the board
/Key4: CH4.1; also elsewhere on the board
/Key5: CH5.1; also elsewhere on the board
/Key6: CH6.1; also elsewhere on the board
/Key7: CH7.1; also elsewhere on the board
/Key8: CH8.1; also elsewhere on the board
/Load1 V: J1-1.1, J2-1.1; also elsewhere on the board
/Load2 V: JP4.2 (C); also elsewhere on the board
/Peripherals/OB-3.3v: J1-2.6, U8.1 (VCC), U14.1 (VCC)
/Peripherals/OB-GND: J1-2.2, U3.4 (GND), U8.3 (GND), U14.3 (GND)
/Peripherals/OB-Hall: J1-2.5, U8.2 (OUT), U14.2 (OUT)
/Peripherals/OB-Load: J1-2.1, U3.2 (VDD3V3)
/Peripherals/OB-SCL: J1-2.3, U3.7 (SCL)
/Peripherals/OB-SDA: J1-2.4, U3.6 (SDA)
GND: CH1.2, CH2.2, CH3.2, CH4.2, CH5.2, CH6.2, CH7.2, CH8.2, J1-1.2, J2-1.2, JP3.2 (C); also elsewhere on the board
unnamed: JJ2-2.1, U13.2 (VDD3V3)
unnamed: JJ2-2.2, U13.4 (GND)
unnamed: JJ2-2.3, U13.7 (SCL)
unnamed: JJ2-2.4, U13.6 (SDA)
unnamed: JP3.1 (A), JP4.3 (B), U15.1 (GND), U16.1 (GND)
unnamed: JP3.3 (B), JP4.1 (A), U15.2 (VCC), U16.2 (VCC)

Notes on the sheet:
Placeholder. Likely to breakout both for easier encoder wheel building Wheel2 is supposed to be on external connectors

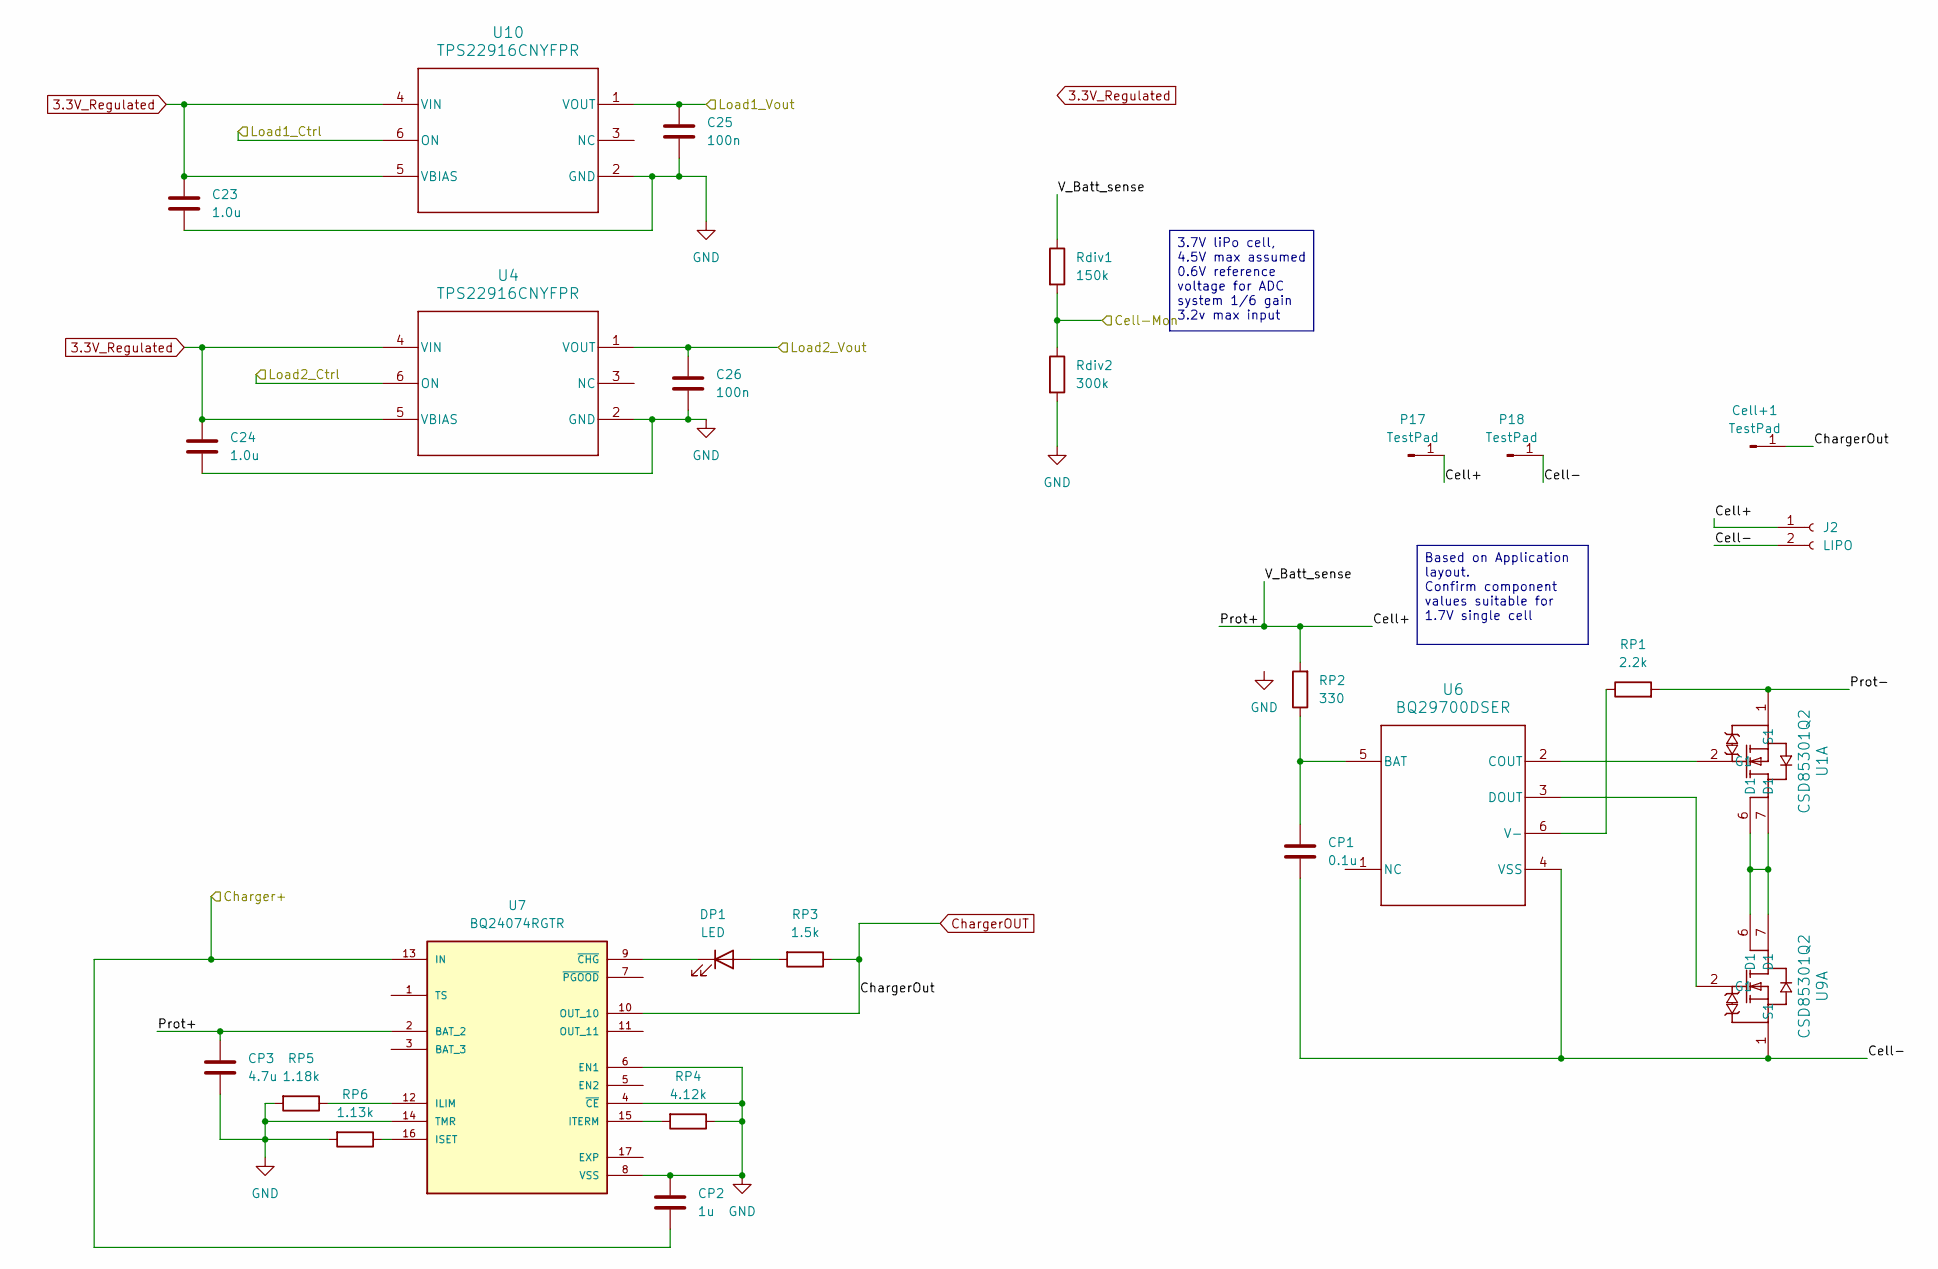
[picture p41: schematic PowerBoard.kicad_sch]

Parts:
C23, C24: 1.0u; C_0603_1608Metric
C25, C26: 100n; C_0402_1005Metric
CP1: 0.1u; C_0201_0603Metric_Pad0.64x0.40mm_HandSolder
CP2: 1u; C_0201_0603Metric_Pad0.64x0.40mm_HandSolder
CP3: 4.7u; C_0201_0603Metric_Pad0.64x0.40mm_HandSolder
Cell+1: TestPad; TestPoint_Pad_D1.0mm
DP1: LED; LED_0603_1608Metric
J2: LIPO; JST_EH_B2B-EH-A_1x02_P2.50mm_Vertical
P17, P18: TestPad; TestPoint_Pad_D1.0mm
RP1: 2.2k; R_0603_1608Metric_Pad0.98x0.95mm_HandSolder
RP2: 330; R_0603_1608Metric_Pad0.98x0.95mm_HandSolder
RP3: 1.5k; R_0603_1608Metric_Pad0.98x0.95mm_HandSolder
RP4: 4.12k; R_0603_1608Metric_Pad0.98x0.95mm_HandSolder
RP5: 1.18k; R_0603_1608Metric_Pad0.98x0.95mm_HandSolder
RP6: 1.13k; R_0603_1608Metric_Pad0.98x0.95mm_HandSolder
Rdiv1: 150k; R_0603_1608Metric
Rdiv2: 300k; R_0603_1608Metric
U1, U9: CSD85301Q2; CDS85301-DQK0006B
U4, U10: TPS22916CNYFPR; DBV0006A_L
U6: BQ29700DSER; BQ29700-DSE0006A
U7: BQ24074RGTR; BQ24074-QFN50P300X300X100-17N; PARTREV M

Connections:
3.3V_Regulated: C23.2, C24.2, U4.4 (VIN), U4.5 (VBIAS), U10.4 (VIN), U10.5 (VBIAS); also elsewhere on the board
/Cell_monitor: Rdiv1.2, Rdiv2.1; also elsewhere on the board
/Load1 CTRL: U10.6 (ON); also elsewhere on the board
/Load1 V: C25.2, U10.1 (VOUT); also elsewhere on the board
/Load2 CTRL: U4.6 (ON); also elsewhere on the board
/Load2 V: C26.2, U4.1 (VOUT); also elsewhere on the board
/Power Handling/Cell+: CP3.1, J2.1, P17.1 (Pin_1_1), RP2.2, Rdiv1.1, U7.2 (BAT_2)
/Power Handling/Cell-: CP1.2, J2.2, P18.1 (Pin_1_1), U6.4 (VSS), U9.1 (S1)
/Power Handling/Prot-: RP1.2, U1.1 (S1)
/USB Vbus: CP2.2, U7.13 (IN); also elsewhere on the board
ChargerOUT: Cell+1.1 (Pin_1_1), RP3.1, U7.10 (OUT_10); also elsewhere on the board
GND: C23.1, C24.1, C25.1, C26.1, CP2.1, CP3.2, RP4.1, RP5.2, RP6.2, Rdiv2.2, U4.2 (GND), U7.4 (~CE), U7.6 (EN1), U7.8 (VSS), U7.14 (TMR), U10.2 (GND); also elsewhere on the board
unnamed: DP1.2 (A), RP3.2
unnamed: DP1.1 (K), U7.9 (~CHG)
unnamed: U1.6 (D1), U1.7 (D1), U9.6 (D1), U9.7 (D1)
unnamed: U1.2 (G1), U6.2 (COUT)
unnamed: CP1.1, RP2.1, U6.5 (BAT)
unnamed: U6.3 (DOUT), U9.2 (G1)
unnamed: RP1.1, U6.6 (V-)
unnamed: RP5.1, U7.12 (ILIM)
unnamed: RP6.1, U7.16 (ISET)
unnamed: RP4.2, U7.15 (ITERM)

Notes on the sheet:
3.7V liPo cell, 4.5V max assumed 0.6V reference voltage for ADC system 1/6 gain 3.2v max input
Based on Application layout. Confirm component values suitable for 1.7V single cell

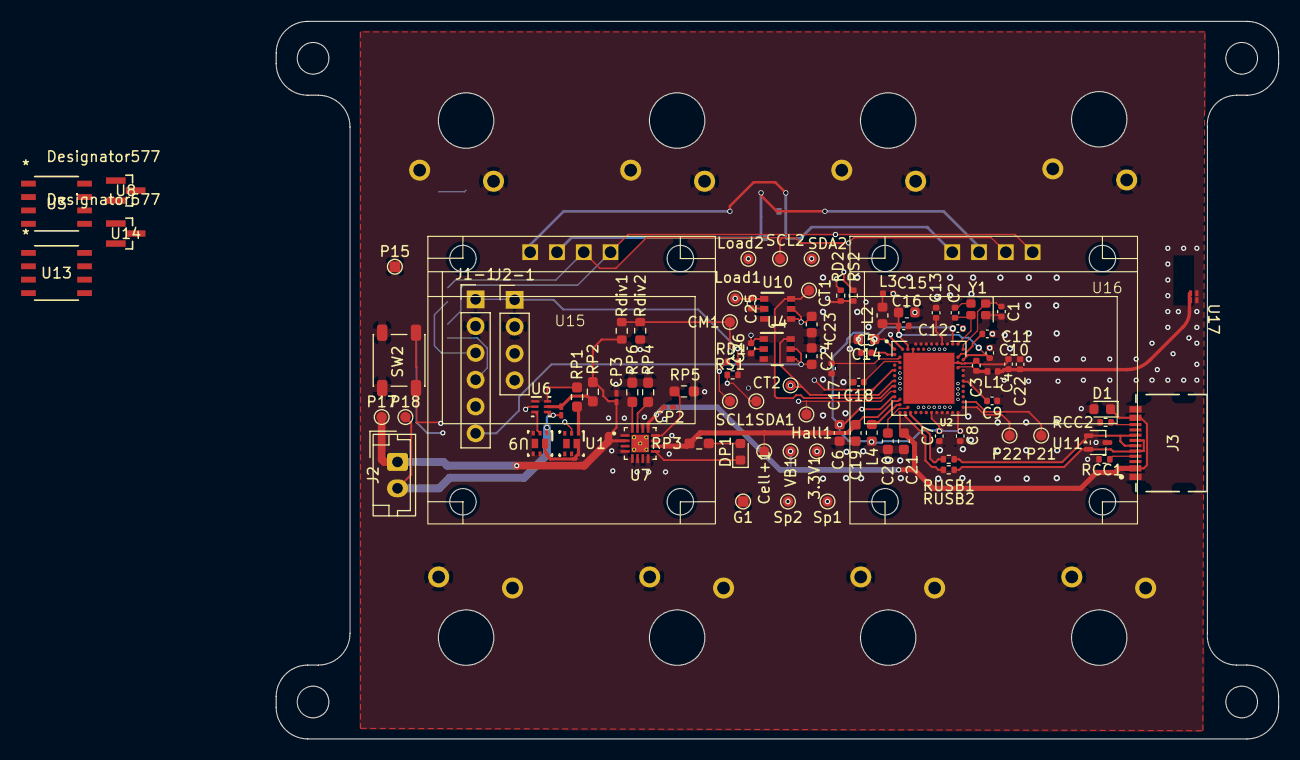
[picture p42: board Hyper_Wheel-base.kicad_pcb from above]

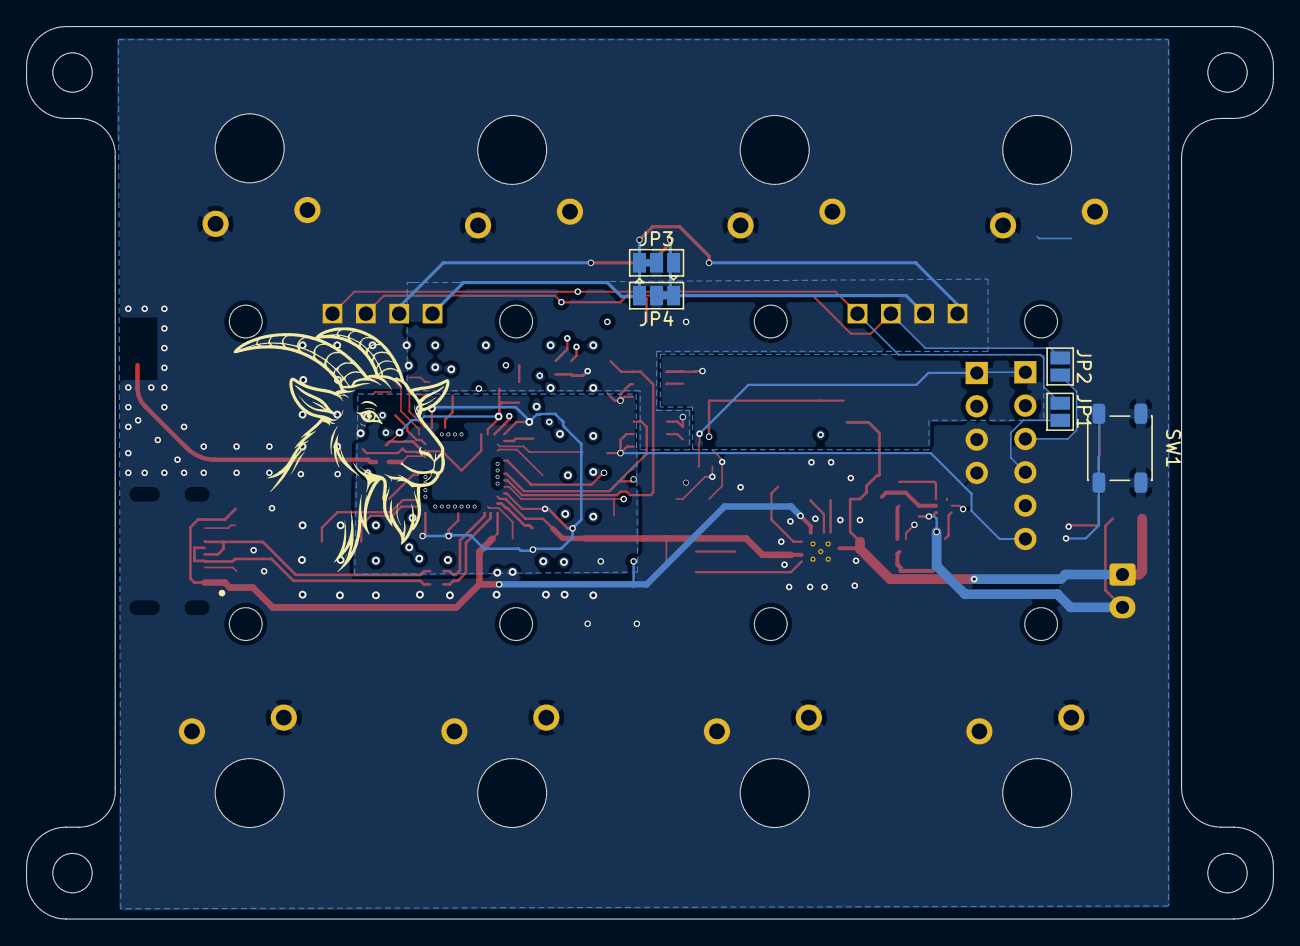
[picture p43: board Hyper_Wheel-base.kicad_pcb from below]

Board: 4 copper layers, 95.0 x 68.0 mm, 106 parts (5 on the bottom side), 67 nets.

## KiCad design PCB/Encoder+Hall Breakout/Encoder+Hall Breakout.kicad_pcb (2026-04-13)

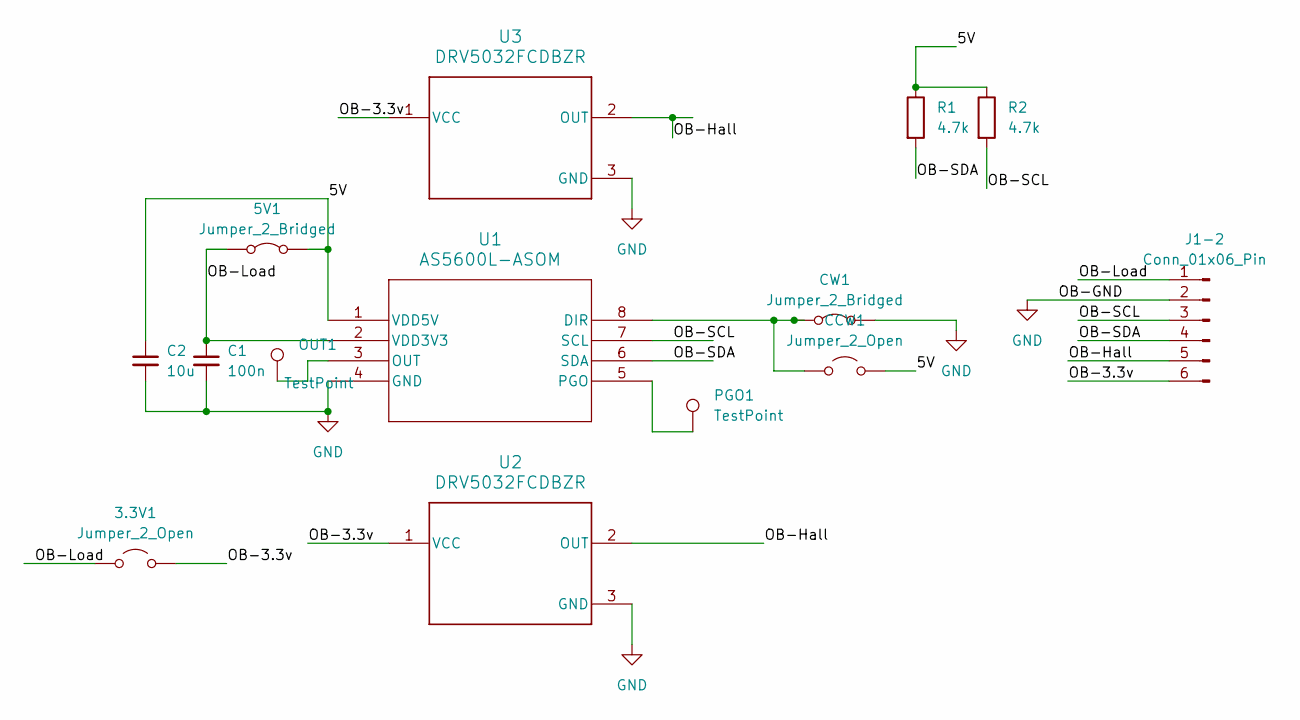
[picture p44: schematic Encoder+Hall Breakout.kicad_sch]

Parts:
3.3V1: Jumper_2_Open; SolderJumper-2_P1.3mm_Open_Pad1.0x1.5mm
5V1: Jumper_2_Bridged; SolderJumper-2_P1.3mm_Bridged_Pad1.0x1.5mm
C1: 100n; C_0603_1608Metric_Pad1.08x0.95mm_HandSolder
C2: 10u; C_0603_1608Metric_Pad1.08x0.95mm_HandSolder
CCW1: Jumper_2_Open; SolderJumper-2_P1.3mm_Open_Pad1.0x1.5mm
CW1: Jumper_2_Bridged; SolderJumper-2_P1.3mm_Bridged_Pad1.0x1.5mm
J1-2: Conn_01x06_Pin; PinHeader_1x06_P2.54mm_Vertical
OUT1: TestPoint; PinHeader_1x01_P1.00mm_Vertical
PGO1: TestPoint; TestPoint_Pad_D2.0mm
R1, R2: 4.7k; R_0603_1608Metric_Pad0.98x0.95mm_HandSolder
U1: AS5600L-ASOM; AS5600L-ASOM_AMS
U2, U3: DRV5032FCDBZR; DRV5032-DBZ0003A-MFG

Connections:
/5V: 5V1.2 (B), C2.1, CCW1.2 (B), R1.1, R2.1, U1.1 (VDD5V)
/OB-3.3v: 3.3V1.2 (B), J1-2.6, U2.1 (VCC), U3.1 (VCC)
/OB-Hall: J1-2.5, U2.2 (OUT), U3.2 (OUT)
/OB-Load: 3.3V1.1 (A), 5V1.1 (A), C1.1, J1-2.1, U1.2 (VDD3V3)
/OB-SCL: J1-2.3, R2.2, U1.7 (SCL)
/OB-SDA: J1-2.4, R1.2, U1.6 (SDA)
GND: C1.2, C2.2, CW1.2 (B), J1-2.2, U1.4 (GND), U2.3 (GND), U3.3 (GND)
unnamed: CCW1.1 (A), CW1.1 (A), U1.8 (DIR)
unnamed: OUT1.1 (1_1), U1.3 (OUT)
unnamed: PGO1.1 (1_1), U1.5 (PGO)

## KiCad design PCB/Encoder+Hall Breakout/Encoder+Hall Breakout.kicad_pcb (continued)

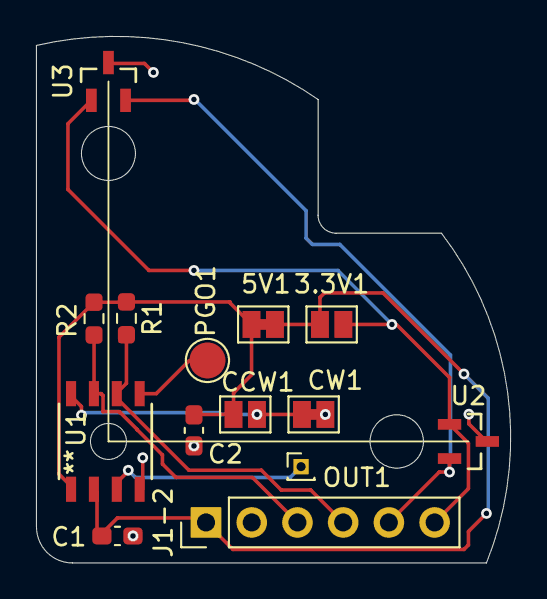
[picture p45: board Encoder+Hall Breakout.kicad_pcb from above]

Board: 2 copper layers, 26.3 x 29.2 mm, 14 parts (0 on the bottom side), 10 nets.

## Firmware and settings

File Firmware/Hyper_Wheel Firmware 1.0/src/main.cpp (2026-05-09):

#include <Arduino.h>
#include <string.h>

#include "buttons.h"
#include "encoder.h"
#include "main_display.h"
#include "action_layer.h"
#include "keymap.h"
#include "interface.h"
#include "config_store.h"
#include "nrf.h"

#include "diagnostics.h"

static DisplayState gDisplayState{};
static ActionLayerState gActionState{};
static DeviceState gDeviceState{};

static bool gDisplayDirty = true;

void enableNfcPinsAsGpio() {
    if (NRF_UICR->NFCPINS != 0) {
        NRF_NVMC->CONFIG = NVMC_CONFIG_WEN_Wen;
        while (NRF_NVMC->READY == NVMC_READY_READY_Busy) {}

        NRF_UICR->NFCPINS = 0;

        while (NRF_NVMC->READY == NVMC_READY_READY_Busy) {}
        NRF_NVMC->CONFIG = NVMC_CONFIG_WEN_Ren;
        while (NRF_NVMC->READY == NVMC_READY_READY_Busy) {}

        NVIC_SystemReset();
    }
}

static void fillDisplayFromActiveProfile(DisplayState& state, const KeymapConfig& config) {
    char labels[8][DISPLAY_LABEL_LEN + 1] = {};

    const KeymapProfile& profile = config.profiles[config.activeProfile];

    for (uint8_t i = 0; i < 8; i++) {
        strncpy(labels[i], profile.keys[i].label, DISPLAY_LABEL_LEN);
        labels[i][DISPLAY_LABEL_LEN] = '\0';
    }

    displaySetProfileName(state, profile.name);
    displaySetLastCommand(
        state,
        config.profiles[config.activeProfile].encoders[0].clockwise.label
    );
    displayFillFromKeyLabels(state, labels);
}



void setup() {
    enableNfcPinsAsGpio();
    Serial.begin(115200);

    //scanI2COnce();
    delay(1000);

    interfaceBegin();
    buttonsBegin();
    systemButtonBegin();
    encoderBegin();


    pinMode(HALL_SENSOR_PIN, INPUT_PULLUP);

    if (!displayBegin()) {
        Serial.println("Display init failed");
        while (1) {
            delay(100);
        }
    }

    configStoreLoadDefaultState(gDeviceState);

    gDeviceState.activePreset = gDefaultKeymapConfig.activeProfile;
    if (gDefaultKeymapConfig.profileCount > 1) {
        gDeviceState.previousPreset =
            (gDefaultKeymapConfig.activeProfile == 0) ? 1 : 0;
    } else {
        gDeviceState.previousPreset = gDefaultKeymapConfig.activeProfile;
    }

    actionLayerBegin(
        gActionState,
        gDefaultKeymapConfig,
        gDeviceState,
        ORIENT_0_DEG
    );

    fillDisplayFromActiveProfile(gDisplayState, gDefaultKeymapConfig);
    displayRenderNormal(gDisplayState);
    gDisplayDirty = false;
}

void loop() {
    bool uiChanged = actionLayerUpdate(gActionState);
    HallTest();
    AnalogTest();

    if (uiChanged) {
        gDisplayDirty = true;
    }

    static InputMode lastMode = MODE_NORMAL;
    if (gActionState.mode != lastMode) {
        gDisplayDirty = true;
        lastMode = gActionState.mode;
    }

    if (gDisplayDirty) {
        if (actionLayerInMenu(gActionState)) {
            displayRenderPresetPicker(gActionState);
        } else {
            fillDisplayFromActiveProfile(gDisplayState, gDefaultKeymapConfig);
            displayRenderNormal(gDisplayState);
        }

        gDisplayDirty = false;
    }

    delay(2);
}

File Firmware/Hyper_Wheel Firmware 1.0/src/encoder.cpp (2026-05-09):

#include "encoder.h"

#include <Wire.h>
#include <AS5600.h>

// -----------------------------------------------------------------------------
// Encoder instance state
// -----------------------------------------------------------------------------
static bool EnableAuxEnc = false;
static bool SerialPrint = true;

struct EncoderState {
    AS5600L dev;

    uint8_t address;

    uint16_t stepCounts = 12;
    uint16_t lastAngle = 0;
    int16_t lastDiff = 0;
    int16_t accum = 0;
    long count = 0;

    uint32_t lastMotionMs = 0;
    volatile int8_t pendingSteps = 0;

    EncoderState(uint8_t addr)
        : address(addr) {}
};

// -----------------------------------------------------------------------------
// I2C / AS5600L
// -----------------------------------------------------------------------------

static constexpr uint8_t EncoderAADDR = 0x40;
static constexpr uint8_t EncoderBADDR = 0x36; // placeholder until second AS5600L is real

static EncoderState encoderA(EncoderAADDR);
static EncoderState encoderB(EncoderBADDR);

// -----------------------------------------------------------------------------
// Encoder tuning
// -----------------------------------------------------------------------------

static constexpr int COUNTS_PER_REV = 4096;
static constexpr int MOTION_THRESHOLD = 1;
static constexpr uint16_t SETTLE_MS = 40;
static constexpr int8_t MAX_PENDING_STEPS = 20;

// -----------------------------------------------------------------------------
// Helpers
// -----------------------------------------------------------------------------

static EncoderState& getEncoderState(EncoderId id) {
    switch (id) {
        case ENCODER_A:
            return encoderA;

        case ENCODER_B:
            return encoderB;

        default:
            return encoderA;
    }
}

static inline int16_t wrapDiff(uint16_t now, uint16_t prev) {
    int16_t d = static_cast<int16_t>(now) - static_cast<int16_t>(prev);

    if (d >  (COUNTS_PER_REV / 2)) d -= COUNTS_PER_REV;
    if (d < -(COUNTS_PER_REV / 2)) d += COUNTS_PER_REV;

    return d;
}

static bool beginEncoder(EncoderState& enc) {
    enc.dev.begin();
    enc.dev.setAddress(enc.address);
    Serial.print("Encoder ");
    Serial.print(enc.address, HEX);
    Serial.println(" initialized.");

    enc.dev.setDirection(AS5600_CLOCK_WISE);

    enc.lastAngle = enc.dev.readAngle();
    enc.lastDiff = 0;
    enc.accum = 0;
    enc.count = 0;
    enc.pendingSteps = 0;
    enc.lastMotionMs = millis();

    return true;
}

static void updateEncoder(EncoderState& enc) {
    uint32_t now = millis();

    uint16_t angle = enc.dev.readAngle();
    int16_t diff = wrapDiff(angle, enc.lastAngle);



    enc.lastAngle = angle;
    enc.lastDiff = diff;

    if (abs(diff) >= MOTION_THRESHOLD) {
        enc.lastMotionMs = now;
        enc.accum += diff;
    } else {
        if ((now - enc.lastMotionMs) > SETTLE_MS) {
            enc.accum = 0;
        }
        return;
    }

    while (abs(enc.accum) >= enc.stepCounts) {
        if (enc.accum > 0) {
            enc.count++;
            enc.accum -= enc.stepCounts;

            if (enc.pendingSteps < MAX_PENDING_STEPS) {
                enc.pendingSteps++;
            }
        } else {
            enc.count--;
            enc.accum += enc.stepCounts;

            if (enc.pendingSteps > -MAX_PENDING_STEPS) {
                enc.pendingSteps--;
            }
            
        }

    }
}

static void setEncoderStepCounts(EncoderState& enc, uint16_t stepCounts) {
    if (stepCounts == 0) {
        stepCounts = 1;
    }

    enc.stepCounts = stepCounts;
}

static int8_t consumePendingSteps(EncoderState& enc) {
    int8_t steps = enc.pendingSteps;
    enc.pendingSteps = 0;
    return steps;
}

// -----------------------------------------------------------------------------
// Public API
// -----------------------------------------------------------------------------

bool encoderBegin() {
    Wire.begin();

    bool okA = beginEncoder(encoderA);
    if(EnableAuxEnc){
        bool okB = beginEncoder(encoderB);
    }

    // Leave this disabled until the second real AS5600L exists.
    // bool okB = beginEncoder(encoderB);

    return okA;
}

void encoderUpdate() {
    updateEncoder(encoderA);
    if(EnableAuxEnc){updateEncoder(encoderB);}

    // Leave disabled until second real encoder exists.
    // updateEncoder(encoderB);
}

int8_t getPendingEncoderSteps(EncoderId id) {
    return consumePendingSteps(getEncoderState(id));
}

bool encoderHasSteps(EncoderId id) {
    return getEncoderState(id).pendingSteps != 0;
}

long getEncoderCount(EncoderId id) {
    return getEncoderState(id).count;
}

uint16_t getEncoderAngle(EncoderId id) {
    return getEncoderState(id).lastAngle;
}

int16_t getEncoderDiff(EncoderId id) {
    return getEncoderState(id).lastDiff;
}

void encoderSetStepCounts(EncoderId id, uint16_t stepCounts) {
    setEncoderStepCounts(getEncoderState(id), stepCounts);
}

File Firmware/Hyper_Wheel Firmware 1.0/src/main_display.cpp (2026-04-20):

#include "main_display.h"

#include "action_layer.h"

#include <Arduino.h>
#include <Wire.h>
#include <Adafruit_GFX.h>
#include <Adafruit_SSD1306.h>
#include <string.h>

static constexpr uint8_t SCREEN_WIDTH = 128;
static constexpr uint8_t SCREEN_HEIGHT = 64;
static constexpr int OLED_RESET = -1;
static constexpr uint8_t OLED_ADDR_A = 0x3D;
static constexpr uint8_t OLED_ADDR_B = 0x3C;

static Adafruit_SSD1306 displayA(SCREEN_WIDTH, SCREEN_HEIGHT, &Wire, OLED_RESET);
static Adafruit_SSD1306 displayB(SCREEN_WIDTH, SCREEN_HEIGHT, &Wire, OLED_RESET);

static DisplayState gLastRenderedNormalState{};
static bool gHasRenderedNormalOnce = false;

static uint8_t gLastRenderedMenuMode = 255;
static uint8_t gLastRenderedHighlight = 255;
static bool gHasRenderedMenuOnce = false;

static bool displayStateEquals(const DisplayState& a, const DisplayState& b) {
    return memcmp(&a, &b, sizeof(DisplayState)) == 0;
}

static void copyLabel(char dest[DISPLAY_LABEL_LEN + 1], const char* src) {
    strncpy(dest, src, DISPLAY_LABEL_LEN);
    dest[DISPLAY_LABEL_LEN] = '\0';
}

void displaySetProfileName(DisplayState& state, const char* text) {
    copyLabel(state.profileName, text);
}

void displaySetLastCommand(DisplayState& state, const char* text) {
    copyLabel(state.lastCommand, text);
}

void displayFillFromKeyLabels(DisplayState& state,
                              const char keyLabels[8][DISPLAY_LABEL_LEN + 1]) {
    copyLabel(state.screenA[0], keyLabels[4]); // Key5
    copyLabel(state.screenA[1], keyLabels[5]); // Key6
    copyLabel(state.screenA[2], keyLabels[0]); // Key1
    copyLabel(state.screenA[3], keyLabels[1]); // Key2

    copyLabel(state.screenB[0], keyLabels[6]); // Key7
    copyLabel(state.screenB[1], keyLabels[7]); // Key8
    copyLabel(state.screenB[2], keyLabels[2]); // Key3
    copyLabel(state.screenB[3], keyLabels[3]); // Key4
}

static void drawQuadrants(Adafruit_SSD1306& d,
                          const char labels[4][DISPLAY_LABEL_LEN + 1],
                          const char* centerText) {
    d.clearDisplay();
    d.setTextColor(SSD1306_WHITE);

    d.setTextSize(1);
    d.setCursor(0, 0);
    d.print(labels[0]);

    d.setCursor(74, 0);
    d.print(labels[1]);

    d.setCursor(0, 54);
    d.print(labels[2]);

    d.setCursor(74, 54);
    d.print(labels[3]);

    d.setTextSize(2);

    int16_t x1, y1;
    uint16_t w, h;
    d.getTextBounds(centerText, 0, 0, &x1, &y1, &w, &h);

    int16_t cx = (SCREEN_WIDTH - w) / 2;
    int16_t cy = (SCREEN_HEIGHT - h) / 2;

    d.setCursor(cx, cy);
    d.print(centerText);

    d.display();
}

static void drawPresetPickerScreenA(Adafruit_SSD1306& d,
                                    uint8_t highlightedPreset,
                                    uint8_t profileCount) {
    d.clearDisplay();
    d.setTextColor(SSD1306_WHITE);

    d.setTextSize(2);
    d.setCursor(0, 0);
    d.print("PRESET");

    d.setTextSize(1);
    d.setCursor(0, 24);
    d.print("Turn: Browse");

    d.setCursor(0, 36);
    d.print("Sys: Select");

    d.setCursor(0, 54);
    d.print(highlightedPreset + 1);
    d.print("/");
    d.print(profileCount);

    d.display();
}

static void drawPresetPickerScreenB(Adafruit_SSD1306& d,
                                    const ActionLayerState& actionState) {
    d.clearDisplay();
    d.setTextColor(SSD1306_WHITE);
    d.setTextSize(1);

    const char* prev = actionLayerGetMenuItemLabel(actionState, 0);
    const char* curr = actionLayerGetMenuItemLabel(actionState, 1);
    const char* next = actionLayerGetMenuItemLabel(actionState, 2);

    uint8_t item = actionState.highlightedPreset;

    d.setCursor(0, 8);
    d.print(" ");
    if (item > 0) {
        d.print(item);
        d.print(": ");
    } else {
        d.print("   ");
    }
    d.print(prev);

    d.drawRect(0, 24, SCREEN_WIDTH, 16, SSD1306_WHITE);
    d.setCursor(2, 28);
    d.print(">");
    d.print(item + 1);
    d.print(": ");
    d.print(curr);

    d.setCursor(0, 48);
    d.print(" ");
    if ((item + 1) < actionState.config->profileCount) {
        d.print(item + 2);
        d.print(": ");
    } else {
        d.print("   ");
    }
    d.print(next);

    d.display();
}

bool displayBegin() {
    Wire.begin();

    if (!displayA.begin(SSD1306_SWITCHCAPVCC, OLED_ADDR_A)) {
        return false;
    }

    if (!displayB.begin(SSD1306_SWITCHCAPVCC, OLED_ADDR_B)) {
        return false;
    }

    displayA.clearDisplay();
    displayA.display();

    displayB.clearDisplay();
    displayB.display();

    return true;
}

void displayRenderNormal(const DisplayState& state) {
    if (gHasRenderedNormalOnce && displayStateEquals(state, gLastRenderedNormalState)) {return;}

    drawQuadrants(displayA, state.screenA, state.profileName);
    drawQuadrants(displayB, state.screenB, state.lastCommand);

    memcpy(&gLastRenderedNormalState, &state, sizeof(DisplayState));
    gHasRenderedNormalOnce = true;
    gHasRenderedMenuOnce = false;
}

void displayRenderPresetPicker(const ActionLayerState& actionState) {
    if (actionState.config == nullptr || actionState.config->profileCount == 0) {
        return;
    }

    if (gHasRenderedMenuOnce &&
        gLastRenderedMenuMode == static_cast<uint8_t>(actionState.mode) &&
        gLastRenderedHighlight == actionState.highlightedPreset) {
        return;
    }

    drawPresetPickerScreenA(displayA,
                            actionState.highlightedPreset,
                            actionState.config->profileCount);

    drawPresetPickerScreenB(displayB, actionState);

    gLastRenderedMenuMode = static_cast<uint8_t>(actionState.mode);
    gLastRenderedHighlight = actionState.highlightedPreset;
    gHasRenderedMenuOnce = true;
}

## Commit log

2026-03-25 stage 1- power system wiring
    [Hyper_Wheel-base.kicad_pcb, Hyper_Wheel-base.kicad_sch, PowerBoard.kicad_sch]
2026-04-03 Base Push
    [ANT_Johanson_2450AT18D0100001E v1.step, BQ24074RGTR.step, CON_2082940020.step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]
2026-04-03 Missing TVS Diode places
    [Hyper_Wheel-base.kicad_pcb, Hyper_Wheel-base.kicad_sch]
2026-04-06 Updated work on antenna, And adjusted log structure
    [Hyper_Wheel-base.kicad_pcb, Hyper_Wheel-base.kicad_sch]
2026-04-06 4-6 progress update
    [Hyper_Wheel-base.kicad_pcb]
2026-04-07 Main board nearing RevA completion
    [Hyper_Wheel-base.kicad_pcb, Hyper_Wheel-base.kicad_sch, Peripherals.kicad_sch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]
2026-04-07 split out magnetic encoder on "ribbon cables" reduces board size
2026-04-10 power plane added, passes Peer review
    [Hyper_Wheel-base.kicad_pcb, Hyper_Wheel-base.kicad_sch, Peripherals.kicad_sch]
2026-04-10 Added test pads,
    [Hyper_Wheel-base.kicad_pcb, Hyper_Wheel-base.kicad_sch, MCU_Core.kicad_sch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]
2026-04-13 XIAO based test board complete
    [ANT_Johanson_2450AT18D0100001E v1.step, AS5600 Breakouts.kicad_pcb, AS5600 Breakouts.kicad_sch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]
2026-04-13 Encoder Breakout added
    [ANT_Johanson_2450AT18D0100001E v1.step, AS5600 Breakouts.kicad_pcb, AS5600 Breakouts.kicad_sch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]
2026-04-13 fabrication submit for XIAO and encoder wheels
    [Encoder+Hall Breakout.kicad_pcb, Hyper_Wheel-base.kicad_pcb, Hyper_Wheel-base.kicad_sch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]
2026-04-13 Final cleanup
    [Hyper_Wheel-base.kicad_pcb, Hyper_Wheel-base.kicad_sch, PowerBoard.kicad_sch]
2026-04-13 added Revision mark
    [Hyper_Wheel-base.kicad_pcb, bom.csv, designators.csv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]
2026-04-13 Added entry to log. Production Hold now.
    [Hyper_Wheel-base.kicad_pcb, Hyper_Wheel-base.kicad_sch, MCU_Core.kicad_sch]
2026-04-14 Readme Update
    [Encoder Breakout.step, Hyper_Wheel-base.kicad_pcb]
2026-04-14 added Power budget
2026-04-15 Switched Load switch update
    [Hyper_Wheel-base.kicad_pcb, Hyper_Wheel-base.kicad_sch, PowerBoard.kicad_sch]
2026-04-15 revA-1 gerbers
    [Hyper_Wheel-base.kicad_pcb, bom.csv, designators.csv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]
2026-04-17 Firmware Begin, Encoder and button core online
2026-04-20 Encoder profiles added, keymap moved
2026-04-20 sticky menu fix and main preset edit
    [action_layer.cpp, main.cpp, main_display.cpp]
2026-04-25 Rev B Xiao. migrated changes to main
    [Hyper_Wheel-base.kicad_pcb, Hyper_Wheel_XIAO.kicad_pcb, Peripherals.kicad_sch]
2026-04-26 added .5mm pitch ribbon cable. install TBD
    [59453-062110ECHLF.step, Hyper_Wheel-base.kicad_pcb]
2026-04-27 RevB Xiao Updates. Fab
    [Hyper_Wheel_XIAO.kicad_pcb, Peripherals.kicad_sch, PowerBoard.kicad_sch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]
2026-05-09 begin dual encoder migration
    [Encoder+Hall Breakout.csv, Hyper_Wheel_XIAO.csv]
2026-05-09 Dual Encoder migration complete. not enabled
2026-05-09 added a tiny cell voltage monitor. more work required
